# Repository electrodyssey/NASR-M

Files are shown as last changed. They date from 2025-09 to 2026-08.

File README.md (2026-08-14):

# NASR-M

SYZYGY carrier board powered by ZYNQ7000 SOC

Work in progress.

[Project goals and short design description](https://electrodyssey.net/nasr-m-syzygy-carrier-board.html)

[PDF schema is in schema-export folder](schema-export/NASR.pdf)

[Please watch ERRATA.txt for issues discovered during the board bringup](ERRATA.txt)

Version D 0.9.5 0b79528 (commit eba317391af35e6ee1b4c2de4c383aa31be21669) was submitted to production for a first prototype.

Things that worked so far:

+power distribution

+base controller (mostly works, but the MCU ethernet circuit isn't soldered in yet). [The Zephyr firmware is here](https://github.com/electrodyssey/NASR-M-ZFW)

+clock generator is configured with 33.333MHz signal

+CPU can run bare metal applications via JTAG

+DDR3 subsystem passes Zynq DDR tests with no errors

+PS Ethernet works

+Linux boots of SD card

+PS to PL DMA transfers works!

Watch [the blog](https://electrodyssey.net/tag_nasr-m.html) for an immersive soap opera experience.

The project is distributed under [Permissive OSHW License version 2](cern_ohl_p_v2.txt).

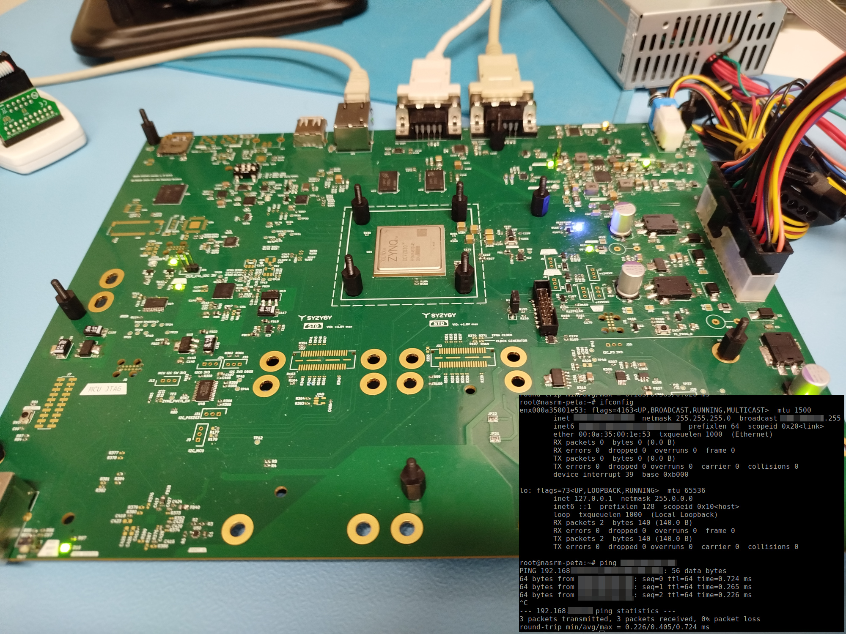
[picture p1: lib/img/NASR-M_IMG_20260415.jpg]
board photo NASR-M


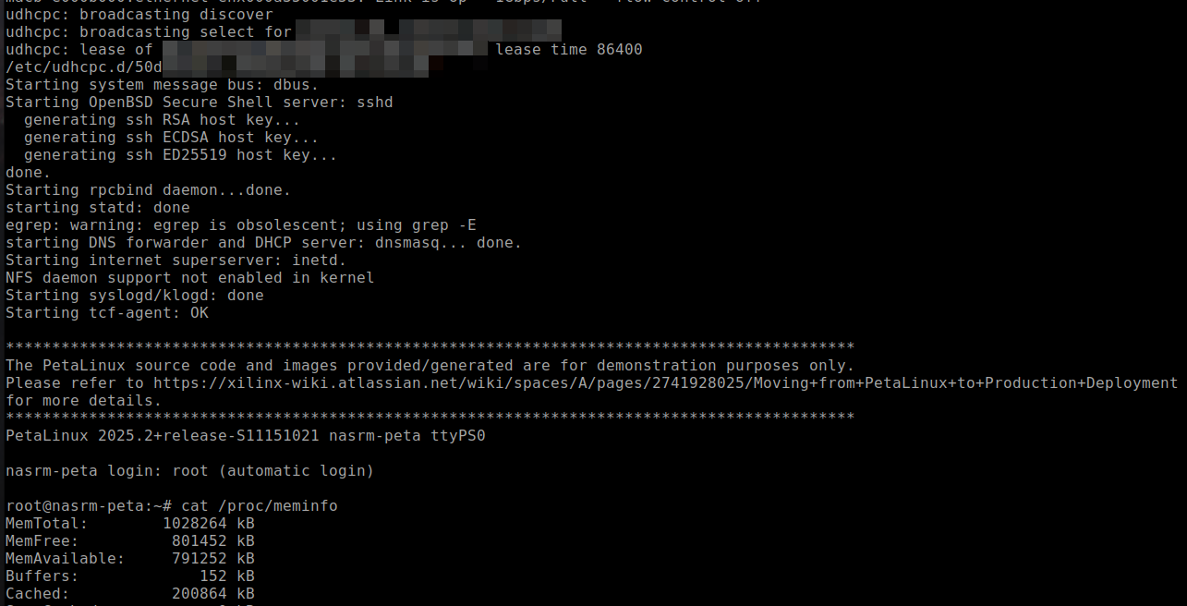
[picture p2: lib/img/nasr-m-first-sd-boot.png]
Linux boot in console NASR-M Linux boot


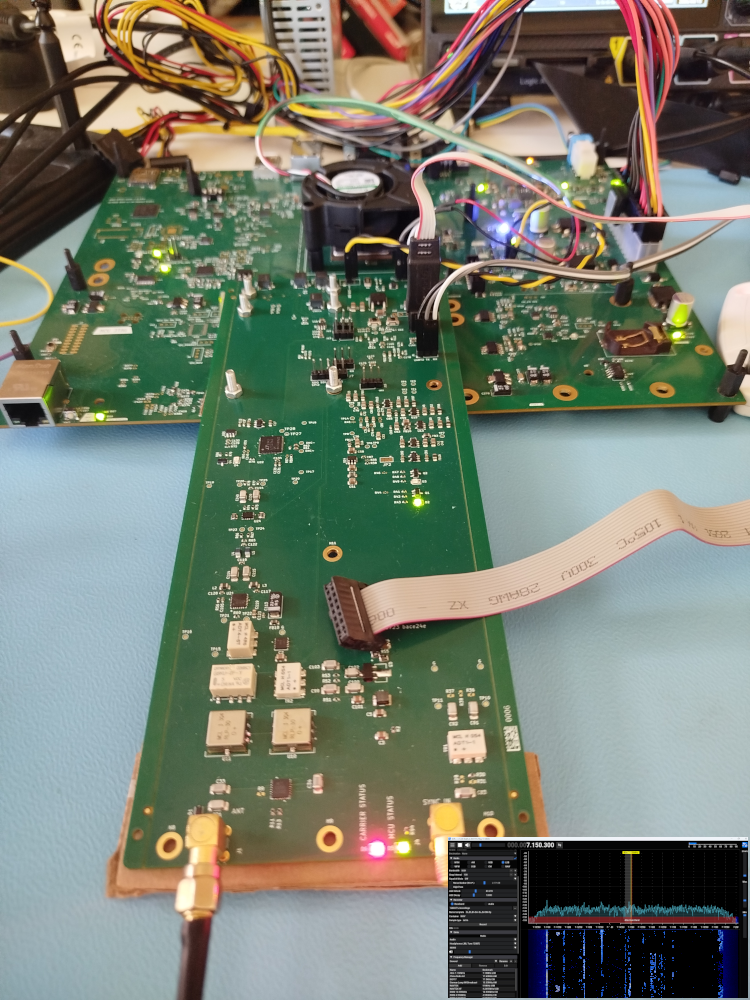
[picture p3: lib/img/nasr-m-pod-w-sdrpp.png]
SDR++ receives HF radio stream NASR-M with an HF receiver pod & SDR++


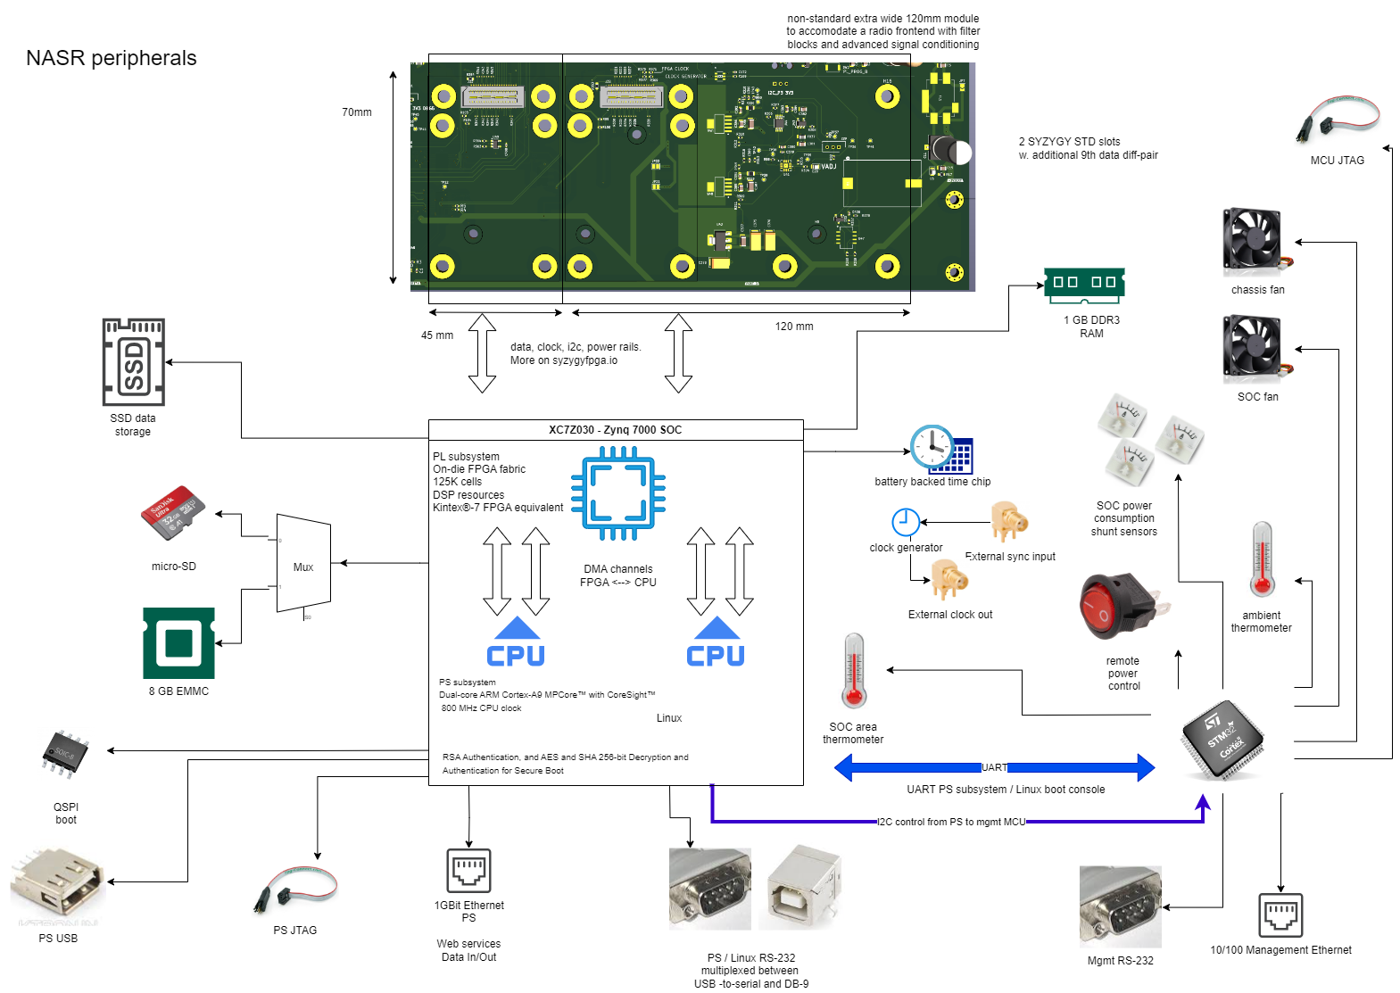
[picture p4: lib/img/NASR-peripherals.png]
Peripherals map Perhipherals map


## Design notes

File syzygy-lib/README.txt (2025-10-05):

SYZYGY templates were obtained from:

https://github.com/SYZYGYfpga/pcb-templates

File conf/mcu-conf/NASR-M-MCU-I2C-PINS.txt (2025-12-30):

PB6 -> I2C1 TREE SCL
PB7 -> I2C1 TREE SDA

PF0 -> I2C2 MCU SDA
PF1 -> I2C2 MCU SCL

PF14 ->I2C4 CLK SCL
PF15 ->I2C4 CLK SDA

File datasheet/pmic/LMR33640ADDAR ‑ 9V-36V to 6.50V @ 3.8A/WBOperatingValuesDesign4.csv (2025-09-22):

Name | Value | Category | Description
Vout | 6.5 V | System Information | Operational Output Voltage
IC Tolerance | 15 mV | IC | IC Feedback Tolerance
Cin IRMS | 1.5 A | Capacitor | Input capacitor RMS ripple current
Cin Pd | 748.89 µW | Capacitor | Input capacitor power dissipation
Cout IRMS | 266.48 mA | Capacitor | Output capacitor RMS ripple current
Cout Pd | 71.89 µW | Capacitor | Output capacitor power dissipation
Coutx IRMS | 346.01 µA | Capacitor | Output capacitor_x RMS ripple current
Coutx Pd | 2.39 nW | Capacitor | Output capacitor_x power loss
L Ipp | 924.33 mA | Inductor | Peak-to-peak inductor ripple current
L Pd | 275.71 mW | Inductor | Inductor power dissipation
Ipp percentage | 24.32% | Inductor | Inductor ripple current percentage (with respect to average inductor current)
Duty Cycle | 19.12% | System Information | Duty cycle
Efficiency | 91.4% | System Information | Steady state efficiency
Frequency | 400 kHz | System Information | Switching frequency
IC Tj | 118.41 °C | IC | IC junction temperature
ICThetaJA | 42.9 °C/W | IC | IC junction-to-ambient thermal resistance
IC Pd | 2.06 W | IC | IC power dissipation
Pout | 24.7 W | System Information | Total output power
Iin Avg | 751.05 mA | IC | Average input current
IC Ipk | 4.26 A | IC | Peak switch current in IC
Mode | CCM | System Information | Conduction Mode
Vout p-p | 3.79 mV | System Information | Peak-to-peak output ripple voltage
Vin p-p | 126.94 mV | System Information | Peak-to-peak input voltage
Phase Marg | 57.63 ° | System Information | Bode Plot Phase Margin
Cross Freq | 29.64 kHz | System Information | Bode plot crossover frequency
Low Freq Gain | 89.51 dB | System Information | Gain at 1Hz
Gain Marg | -28.19 dB | System Information | Bode Plot Gain Margin
Total Pd | 2.34 W | Power | Total Power Dissipation
FootPrint | 600 mm² | System Information | Total Foot Print Area of BOM components
Vin | 36 V | System Information | Vin operating point
Iout | 3.8 A | System Information | Iout operating point
Cin Pd | 748.89 µW | Power | Input capacitor power dissipation
Cout Pd | 71.89 µW | Power | Output capacitor power dissipation
Coutx Pd | 2.39 nW | Power | Output capacitor_x power loss
L Pd | 275.71 mW | Power | Inductor power dissipation
IC Pd | 2.06 W | Power | IC power dissipation
Vout Actual | 6.49 V | System Information | Vout Actual calculated based on selected voltage divider resistors
Vout Tolerance | 3.23% | System Information | Vout Tolerance based on IC Tolerance (no load) and voltage divider resistors if applicable
Total BOM | $4.26 | System Information | Total BOM Cost
BOM Count | 23 | System Information | Total Design BOM count

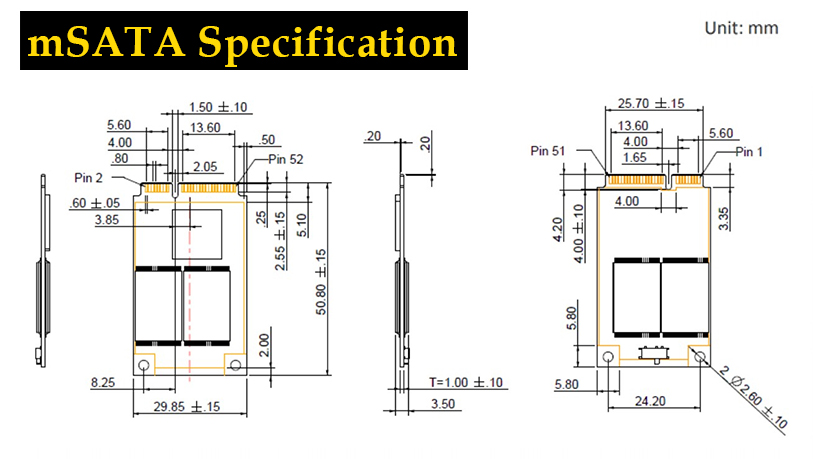
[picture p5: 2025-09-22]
mech/msata/mSATA-size-Specification.jpg

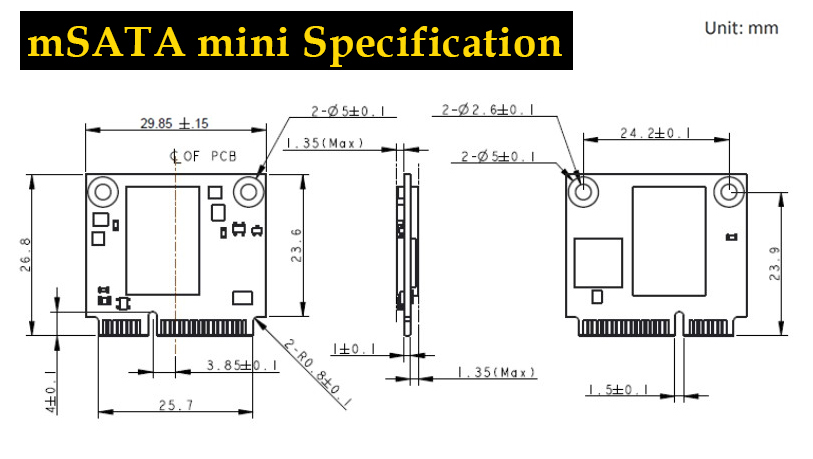
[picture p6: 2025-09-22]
mech/msata/mSATA-mini-size-Specification.jpg

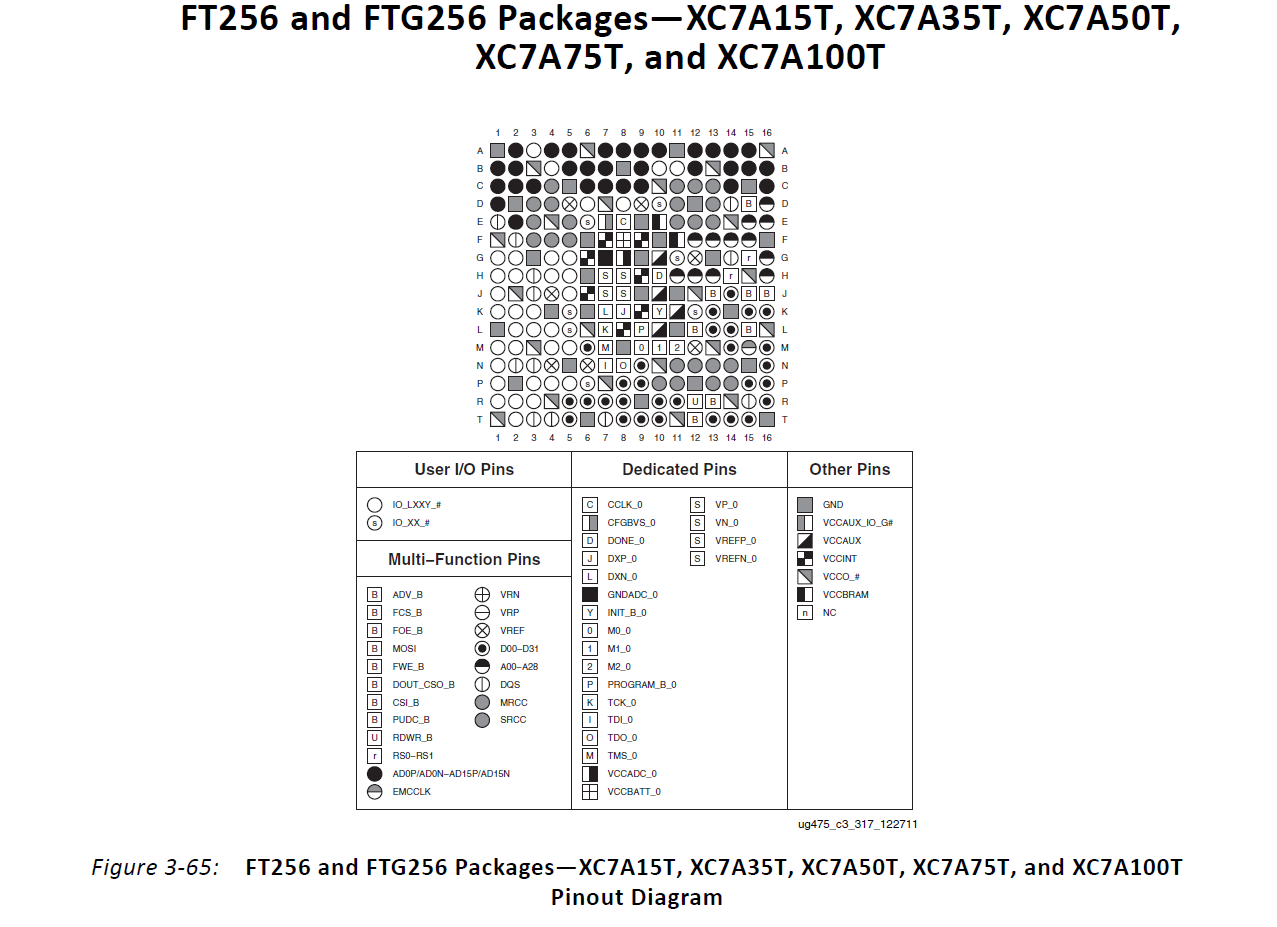
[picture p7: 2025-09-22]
datasheet/xilinx-7/artix-7-clocking/XC7A50T-FTG256-pinout.png

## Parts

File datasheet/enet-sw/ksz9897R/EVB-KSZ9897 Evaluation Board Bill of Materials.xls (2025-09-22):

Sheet: BOM Report
Bill of Materials |  | EVB-KSZ9897 |  |  |  | Build Qty: | 10
Document Number: | 02-PCB-UNG_8076
Board Number: | 04-PCB-UNG_8076
Part Number: | EVB-KSZ9897
Revision: | B1
Engineer:
Drawn By:
Creation Date: | 10:40:54 AM
Print Date: | 18:50:46
Quantity Per Build | Designator | Description_ | Manufacturer 1 | Manufacturer Part Number 1 | Supplier 1 | Supplier Part Number 1 | Supplier Unit Price 1 | Price / 1 Board | Populated | Quantity | Quantity Override | Notes
560 | C1, C2, C3, C4, C5, C6, C7, C8, C9, C10, C11, C12, C13, C14, C15, C16, C22, C23, C24, C25, C31, C32, C45, C51, C52, C53, C54, C55, C56, C57, C58, C59, C65, C66, C67, C68, C69, C70, C71, C72, C77, C78, C79, C80, C81, C82, C83, C84, C94, C118, C119, C120, C122, C134, C143, C144 | CAP CER 0.1uF 50V 10% X7R SMD 0402 | TDK Corporation | C1005X7R1H104K050BB | Digi-Key | 445-5932-1-ND |  | $0.00 |  | 56 | 56
10 | C17 | CAP CER 1UF 50V 10% X7R 0603 | Taiyo Yuden | UMK107AB7105KA-T | Digi-Key | 587-3247-1-ND |  | $0.00 |  | 1 | 1
350 | C18, C19, C21, C26, C27, C28, C34, C37, C38, C41, C42, C46, C47, C48, C64, C107, C109, C110, C112, C113, C114, C115, C116, C117, C124, C125, C127, C128, C129, C137, C138, C139, C140, C141, C142 | CAP CER 0.1UF 35V X5R 0402 | TDK Corporation | C1005X5R1V104M050BB | Digi-Key | 445-7385-1-ND |  | $0.00 |  | 35 | 35
20 | C20, C135 | CAP CER 0.1uF 25V 10% X7R SMD 0603 | Murata | GRM188R71E104KA01D | Digi-Key | 490-1524-1-ND |  | $0.00 |  | 2 | 2
60 | C29, C106, C108, C111, C123, C126 | CAP CER 4.7uF 6.3V 20% X5R SMD 0603 | Panasonic | ECJ-1VB0J475M | Digi-Key | PCC2318CT-ND |  | $0.00 |  | 6 | 6
10 | C33 | CAP CER 2.2uF 6.3V 10% X7R SMD 0603 | TDK | C1608X7R0J225K | Digi-Key | 445-5960-1-ND |  | $0.00 |  | 1 | 1
20 | C35, C36 | CAP CER 0.1uF 10V 10% X5R SMD 0402 | KEMET | C0402C104K8PACTU | Digi-Key | 399-3027-1-ND |  | $0.00 |  | 2 | 2
60 | C39, C43, C130, C131, C167, C168 | CAP CER 15pF 50V 5% NP0 SMD 0402 | Murata | GRM1555C1H150JA01D | Digi-Key | 490-5888-2-ND |  | $0.00 |  | 6 | 6
40 | C40, C44, C132, C136 | CAP CER 1uF 16V 10% X5R SMD 0603 | AVX | 0603YD105KAT2A | Digi-Key | 478-1249-1-ND |  | $0.00 |  | 4 | 4
80 | C49, C60, C61, C62, C76, C85, C88, C89 | CAP CER 10uF 25V 10% X5R SMD 0805 | Murata | GRM21BR61E106KA73L | Digi-Key | 490-5523-1-ND |  | $0.00 |  | 8 | 8
20 | C50, C75 | CAP CER 1uF 16V 10% X5R SMD 0402 | TDK Corporation | C1005X5R1C105K | Digi-Key | 445-4978-2-ND |  | $0.00 |  | 2 | 2
20 | C63, C90 | CAP CER 1UF 35V 10% X5R SMD 0402 | Murata Electronics North America | GRM155R6YA105KE11D | Digi-Key | 490-10019-1-ND |  | $0.00 |  | 2 | 2
40 | C73, C74, C86, C96 | CAP CER 10uF 6.3V 20% X5R SMD 0603 | AVX | 06036D106MAT2A | Digi-Key | 478-5318-2-ND |  | $0.00 |  | 4 | 4
10 | C91 | CAP CER 0.33uF 50V 10% X7R SMD 0805 | TDK Corporation | C2012X7R1H334K125AA | Digi-Key | 445-7541-1-ND |  | $0.00 |  | 1 | 1
10 | C92 | CAP CER 47UF 25V X5R 1206 | TDK Corporation | C3216X5R1E476M160AC | Mouser | 810-C3216X5R1E476M |  | $0.00 |  | 1 | 1
10 | C93 | CAP TANT 330uF 6.3V 20% 45mOhm SMD D | KEMET | T520D337M006ATE045 | Digi-Key | 399-4055-1-ND |  | $0.00 |  | 1 | 1
10 | C95 | CAP CER 1000PF 2KV 1808 | Murata | GR442QR73D102KW01L | Mouser | 81-GR442QR73D102KW01 |  | $0.00 |  | 1 | 1
10 | R89 | CAP CER 12pF 50V 5% NP0 SMD 0603 | Panasonic | ECJ-1VC1H120J | Digi-Key | 478-1164-1-ND |  |  |  | 1 | 1
10 | D1 | DIO SCTKY MBRX140-TP 550mV 1A 40V SMD SOD-123 | Micro Commercial Co | MBRX140-TP | Digi-Key | MBRX140TPMSCT-ND |  | $0.00 |  | 1 | 1
20 | D2, D12 | LED, Bright Green, 0603 | Lite-On | LTST-C191KGKT | Digi-Key | 160-1446-6-ND |  | $0.00 |  | 2 | 2
20 | D3, D4 | LED, Blue, 0603 | Kingbright | APT1608VBC/D | Digi-Key | 754-1789-6-ND |  | $0.00 |  | 2 | 2
10 | D5 | DIO LED YELLOW 2.1V 20mA 14mcd Diffuse SMD 0603 | Lumex | sml-lx0603yw | Digi-Key | 67-1550-6-ND |  | $0.00 |  | 1 | 1
10 | D6 | LED, Bright Red, 0603 | Lite-On | LTST-C191KRKT | Digi-Key | 160-1447-6-ND |  | $0.00 |  | 1 | 1
10 | D7 | DIO SCTKY B340A 500mV 3A 40V DO-214AC_SMA | Diodes Incorporated | B340A-13-F | Digi-Key | B340A-FDICT-ND |  | $0.00 |  | 1 | 1
10 | F1 | Surface Mount Fuses Fuseblock w/ fuse 2A OMNI BLOK 154 | Littelfuse | 0154002.DR | Mouser | 576-0154002.DR |  | $0.00 |  | 1 | 1
100 | FB4, FB5, FB8, FB11, FB12, FB13, FB14, FB15, FB16, FB17 | FERRITE 2A 220R SMD 0805 | Murata Electronics North America | BLM21PG221SN1D | Digi-Key | 490-1054-1-ND |  | $0.00 |  | 10 | 10
60 | J1, J2, J3, J4, J5, J20 | CON MODULAR RJ45 MAGJACK TH R/A | Amphenol Commercial Products | RJMG2012211A0FR | Digikey | RJMG2012211A0FR-ND |  | $0.00 |  | 6 | 6
30 | J6, J8, J11 | HDR 3POS .100" SGL GOLD | Samtec Inc. | TSW-103-07-G-S | Digi-Key | SAM1029-03-ND |  | $0.00 |  | 3 | 3
10 | J7 | CONN PWR JACK 2.5X5.5MM HIGH CUR | CUI Inc. | PJ-002AH | Digi-Key | CP-002AH-ND |  | $0.00 |  | 1 | 1
10 | J9 | CONN RCPT USB TYPE B 3.0 R/A | Wurth Electronics Inc | 692221030100 | Digi-Key | 732-3158-ND |  | $0.00 |  | 1 | 1
10 | J14 | CON HDR-2.54 MALE 1x8 GOLD 5.84MH TH VERT | Samtec | TSW-108-07-G-S | Digi-Key | SAM1029-08-ND |  | $0.00 |  | 1 | 1
10 | J15 | CONN HEADER 6POS .100" DUAL GOLD | Samtec | TSW-103-07-G-D | Digi-Key | SAM1028-03-ND |  | $0.00 |  | 1 | 1
40 | J16, J18, J24, J25 | CON HDR-2.54 MALE 1x2 GOLD 5.84MH TH VERT | Samtec | TSW-102-07-G-S | Digi-Key | SAM1029-02-ND |  | $0.00 |  | 4 | 4
10 | J17 | CON HDR-2.54 Male 2x3 Gold 5.84MH TH VERT | Samtec | TSW-104-07-G-D | Digi-Key | SAM1028-04-ND |  | $0.00 |  | 1 | 1
20 | J21, J23 | CON HDR-2.54 MALE 1x3 GOLD 5.84MH TH VERT | Samtec | TSW-103-07-G-S | Digi-Key | SAM1029-03-ND |  | $0.00 |  | 2 | 2
10 | J22 | HDR 10POS .100" DUAL SHROUDED | Adam Tech | BHR-10-VUA | Future Electronics | BHR-10-VUA |  | $0.00 |  | 1 | 1
10 | J28 | HDR 2POS .100" SGL GOLD | Samtec Inc. | TSW-102-07-G-S | Digi-Key | SAM1029-02-ND |  | $0.00 |  | 1 | 1
10 | L1 | IND 27uH 20 % 2.35A SMD | Bourns | SRR1240-270M | Mouser | 652-SRR1240-270M |  | $0.00 |  | 1 | 1
20 | L2, L3 | INDUCTOR 15uH 1.16A 20% SMD MSS6132 | Coilcraft | MSS6132-153ML | Coilcraft | MSS6132-153ML |  | $0.00 |  | 2 | 2
120 | R1, R2, R3, R4, R5, R6, R7, R8, R9, R15, R87, R124 | RES TKF 100R 5% 1/10W SMD 0603 | Panasonic | ERJ-3GEYJ101V | Digi-Key | P100GTR-ND |  | $0.00 |  | 12 | 12
10 | R10 | RES TKF 20R 5% 1/10W SMD 0603 | NIC Components | NRC06J200TRF | NIC Components | NRC06J200TRF |  | $0.00 |  | 1 | 1
20 | R13, R54 | RES 1k 5% 1/10W SMD 0603 | Panasonic Electronic Components | ERJ-3GEYJ102V | Digi-Key | P1.0KGDKR-ND |  | $0.00 |  | 2 | 2
160 | R14, R31, R32, R44, R47, R52, R56, R106, R107, R110, R111, R123, R125, R127, R128, R129 | RES TKF 0R 1/10W SMD 0603 | Panasonic | ERJ-3GEY0R00V | Digi-Key | P0.0GTR-ND |  | $0.00 |  | 16 | 16
10 | R49 | RES TKF 0R SMD 0402 | Panasonic | ERJ-2GE0R00X | Digi-Key | P0.0JCT-ND |  |  |  | 1 | 1
150 | R16, R22, R29, R50, R51, R61, R64, R65, R66, R67, R68, R72, R84, R85, R86 | RES TKF 10k 5% 1/10W SMD 0603 | Panasonic | ERJ-3GEYJ103V | Digi-Key | P10KGCT-ND |  | $0.00 |  | 15 | 15
10 | R17 | RES TKF 20k 5% 1/10W SMD 0603 | Panasonic | ERJ-3GSYJ203 | Digi-Key | P20KGCT-ND |  | $0.00 |  | 1 | 1
10 | R19 | RES TKF 2k 1% 1/10W SMD 0603 | Panasonic | ERJ-3EKF2001V | Digi-Key | P2.00KHTR-ND |  | $0.00 |  | 1 | 1
110 | R20, R34, R41, R42, R48, R115, R116, R117, R118, R119, R120 | RES 22ohm 5% 1/10W SMD 0402 | Panasonic | ERJ-2GEJ220X | Mouser | P22JTR-ND |  | $0.00 |  | 11 | 11
10 | R21 | RES TKF 40.2k 1% 1/16W SMD 0603 | Panasonic Electronic Components | ERJ-3EKF4022V | Digi-Key | P40.2KHCT-ND |  | $0.00 |  | 1 | 1
10 | R23 | RES TKF 12k 1% 1/10W SMD 0603 | Yageo | RC0603FR-0712KL | Digi-Key | 311-12.0KHRCT-ND |  | $0.00 |  | 1 | 1
20 | R24, R93 | RES TKF 2.05k 1% 1/10W SMD 0603 | Yageo | RC0603FR-072K05L | Digi-Key | 311-2.05KHRTR-ND |  | $0.00 |  | 2 | 2
120 | R25, R26, R27, R28, R30, R35, R75, R76, R77, R78, R80, R82 | RES TKF 22R 1% 1/10W SMD 0603 | Yageo | RC0603FR-0722RL | Digi-Key | 311-22.0HRCT-ND |  | $0.00 |  | 12 | 12
10 | R37 | RES TKF 330R 5% 1/10W SMD 0603 | Panasonic Electronic Components | ERJ-3GEYJ331V | Digi-Key | P330GDKR-ND |  | $0.00 |  | 1 | 1
170 | R39, R40, R74, R79, R81, R83, R91, R96, R98, R99, R100, R101, R103, R104, R109, R112, R113 | RES TKF 1k 5% 1/10W SMD 0603 | Panasonic | ERJ-3GEYJ102V | Digi-Key | P1.0KGDKR-ND |  | $0.00 |  | 17 | 17
20 | R45, R92 | RES TKF 10k 5% 1/10W SMD 0603 | Panasonic | ERJ-3GEYJ103V | Digi-Key | P10KGCT-ND |  | $0.00 |  | 2 | 2
10 | R53 | RES TKF 31.6K 1% 1/10W SMD 0603 | Panasonic Electronic Components | ERJ-3EKF3162V | Digi-Key | P31.6KHCT-ND |  | $0.00 |  | 1 | 1
20 | R55, R59 | RES TKF 10k 1% 1/10W SMD 0603 | NIC Components | NRC06F1002TRF | NIC Components | NRC06F1002TRF |  | $0.00 |  | 2 | 2
10 | R57 | RES TKF 4.7k 5% 1/10W SMD 0603 | Panasonic | ERJ-3GEYJ472V | Digi-Key | P4.7KGCT-ND |  | $0.00 |  | 1 | 1
10 | R58 | RES TKF 21.5K 1% 1/10W SMD 0603 | Panasonic | ERJ-3EKF2152V | DigiKey | P21.5KHCT-ND |  | $0.00 |  | 1 | 1
20 | R69, R114 | RES TKF 100k 5% 1/10W SMD 0603 | Panasonic | ERJ-3GEYJ104V | Digi-Key | P100KGCT-ND |  | $0.00 |  | 2 | 2
10 | R73 | RES 12.1K 1% 1/10W 0603 | Panasonic Electronic Components | ERJ-3EKF1212V | Digi-Key | P12.1KHCT-ND |  | $0.00 |  | 1 | 1
10 | R108 | RES TKF 6.04k 1% 1/10W SMD 0603 | Yageo | 9T06031A6041FBHFT | Digi-Key | 9T06031A6041FBHFT-ND |  | $0.00 |  | 1 | 1
10 | R122 | RES TKF 330R 5% 1/10W SMD 0603 | Panasonic | ERJ-3GEYJ331V | Digi-Key | P330GTR-ND |  | $0.00 |  | 1 | 1
10 | SW1 | Tactile Switch SPST-NO Top Actuated Surface Mount | C&K | PTS810 SJM 250 SMTR LFS | Digi-Key | CKN10502CT-ND |  | $0.00 |  | 1 | 1
10 | SW2 | Slide Switch SPDT Through Hole | C&K | 1101M2S3CQE2 | Digi-Key | CKN5001-ND |  | $0.00 |  | 1 | 1
10 | SW4 | SWITCH SLIDE SPST 24V 100mA 1825058-9EXT ACT 8POS 24V | TE Connectivity Alcoswitch Switches | 1-1825058-9 | Mouser | 506-ADE08S04 |  | $0.00 |  | 1 | 1
10 | TP1 | TEST POINT PC MINI .040"D WHITE | Keystone Electronics | 5002 | Digi-Key | 5002K-ND |  | $0.00 |  | 1 | 1
40 | TP2, TP4, TP5, TP8 | TEST POINT PC MINI .040"D BLACK | Keystone Electronics | 5001 | Digi-Key | 5001K-ND |  | $0.00 |  | 4 | 4
10 | TP3 | TEST POINT PC MINI .040"D ORANGE | Keystone Electronics | 5003 | Digi-Key | 5003K-ND |  | $0.00 |  | 1 | 1
10 | TP6 | TEST POINT PC MINI .040"D YELLOW | Keystone Electronics | 5004 | Digi-Key | 5004K-ND |  | $0.00 |  | 1 | 1
10 | TP7 | TEST POINT PC MINI .040"D RED | Keystone Electronics | 5000 | Digi-Key | 5000K-ND |  | $0.00 |  | 1 | 1
50 | U2, U9, U10, U14, U15 | 74LVC1G14GW,125 SCHMITT-TRG INVERTER | NXP | 74LVC1G14GW,125 | Mouser | 771-74LVC1G14GW-G |  | $0.00 |  | 5 | 5
Microchip Parts listed below
10 | U1 | Edinburgh LAN7801/RGMII pinout, QFN64 | Microchip | LAN7801/RGMII_QFN64 | Microchip | LAN7801/RGMII_QFN64 |  | $0.00 |  | 1 | 1
10 | U3 | IC, 7-Port Gigabit Ethernet Switch with 2 RGMII / MII / RMII Interfaces, TQFP128 | Microchip Technology | KSZ9897RTXC | Microchip Technology | KSZ9897RTXC |  | $0.00 |  | 1 | 1
10 | U4 | IC EEPROM 4KBIT 3MHZ 8SOIC | Microchip Technology | 93AA66C-I/SN | Digi-Key | 93AA66C-I/SN-ND |  | $0.00 |  | 1 | 1
20 | U5, U6 | IC REG BUCK SYNC ADJ 1A 8TDFN | Microchip Technology | MCP16311T-E/MNY | Mouser | 579-MCP16311T-E/MNY |  | $0.00 |  | 2 | 2
10 | U7 | IC REG BUCK ADJ 2A 8SOIC | Micrel Inc | MIC4684YM-TR | Mouser | 998-MIC4684YM |  | $0.00 |  | 1 | 1
10 | U8 | KSZ9031RNXCC Gigabit Ethernet PHY with RGMII | Microchip | KSZ9031RNXCC | Mouser | 998-KSZ9031RNXCC |  | $0.00 |  | 1 | 1
10 | X1 | OSC MEMS CONFIGURABLE FOUR OUTPUT | Microchip Technology | DSC400-1111Q0085KI1 | Microchip Technology | DSC400-1111Q0085KI1 |  | $0.00 |  | 1 | 1
Mechanical Parts to be added in the package
10 | SERIAL1 | Label, Serial Number, Laminated, 250 x 800 | Brother | 1/4" x 0.8" |  |  |  | $0.00 | MECH | 1 | 1
10 | RUBBER FEET | Foot, Silicone Rubber, Adhesive, Clear, Cylindrical, .500"x.250" | Richco | RBS-6 |  |  |  | $0.00 | MECH | 1 | 1
PCB
10 | PCB1 | Printed Circuit Board |  | EVB-KSZ9897 |  |  |  | $0.00 | PCB | 1 | 1
 |  |  |  |  |  |  |  | $0.00
Do Not Populate Parts listed below
0 | C30 | CAP CER 4.7uF 6.3V 20% X5R SMD 0603 | Panasonic | ECJ-1VB0J475M | Digi-Key | PCC2318CT-ND |  | $0.00 | DNP | 1 | 0
0 | C87, C97, C98 | CAP CER 0.1UF 35V X5R 0402 | TDK Corporation | C1005X5R1V104M050BB | Digi-Key | 445-7385-1-ND |  | $0.00 | DNP | 3 | 0
0 | J10, J12, J13, J19 | CON HDR-2.54 Male 2x5 Gold 5.84MH TH VERT | Samtec Inc | TSW-106-07-G-D |  |  |  | $0.00 | DNP | 4 | 0
0 | R11, R12, R18, R94 | RES TKF 10k 5% 1/10W SMD 0603 | Panasonic | ERJ-3GEYJ103V | Digi-Key | P10KGCT-ND |  | $0.00 | DNP | 4 | 0
0 | R33, R36, R38, R43, R46, R60, R102, R105, R126 | RES TKF 0R 1/10W SMD 0603 | Panasonic | ERJ-3GEY0R00V | Digi-Key | P0.0GTR-ND |  | $0.00 | DNP | 9 | 0
0 | R70, R71, R88, R90 | RES TKF 1k 5% 1/10W SMD 0603 | Panasonic | ERJ-3GEYJ102V | Digi-Key | P1.0KGCT-ND |  | $0.00 | DNP | 4 | 0
0 | TP10, TP17 | TEST POINT PC MINI .040"D ORANGE | Keystone Electronics | 5003 | Digi-Key | 5003K-ND |  | $0.00 | DNP | 2 | 0
0 | Y1, Y2, Y3 | Crystal 25MHz 10pF SMD 4Pin DFN LCC | Abracon | ABM8G-25.000MHZ-B4Y-T | Mouser | 815-ABM8G-25-B4Y-T |  | $0.00 | DNP | 3 | 0
 |  |  |  |  |  |  |  | #REF!
Approved | Notes

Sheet: Project Information
Project Full Path | C:\Users\jhancock\Perforce\txusperforce_1999\jhancock_AUS-LT-C21683\depot_np_hweng_boards\ung_hweng\UNG_8076_KSZ9897_EVB (Queen)\Rev B\EVB-KSZ9897_B.PrjPcb
Project Filename | EVB-KSZ9897_B.PrjPcb
Variant Name | None
Board Number | PCB-UNG_8076
Data-Source Filename | EVB-KSZ9897_B.PrjPcb
Data-Source Full Path | C:\Users\jhancock\Perforce\txusperforce_1999\jhancock_AUS-LT-C21683\depot_np_hweng_boards\ung_hweng\UNG_8076_KSZ9897_EVB (Queen)\Rev B\EVB-KSZ9897_B.PrjPcb
Title | Queen
Total Quantity | 348
Report Time | 10:40:54 AM
Report Date | 12/2/2016
Report Date & Tine | 12/2/2016 10:40:54 AM
Output Name | Bill of Materials
Output Type | BOM_PartType
Output Generator Name | BOM
Output Generator Description | Bill of Materials
PCB Label Number | <Parameter ProjectBoardLabel not found>
Part Number | EVB-KSZ9897

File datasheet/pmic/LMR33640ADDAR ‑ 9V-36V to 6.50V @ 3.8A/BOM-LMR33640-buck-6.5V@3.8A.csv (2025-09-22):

Part | Manufacturer | Part Number | Quantity | Price ($) | Footprint (mm²) | Description
Cb_inpflt | Nichicon | UUD1H270MCL1GS | 2 | 0.18 | 79.98 | Cap: 27 µF Total Derated Cap: 54 µF VDC: 50 V ESR: 680 mΩ Package: 6.3x7.7
Cf_inpflt | TDK | C3225X7R1H106M250AC | 3 | 0.27 | 14.7 | Cap: 10 µF Total Derated Cap: 9.5 µF VDC: 50 V ESR: 1 mΩ Package: 1210
Rd_inpflt | Panasonic | ERJ-3RSFR10V | 1 | 0.03 | 4.68 | Resistance: 100 mΩ Tolerance: 1.0% Power: 100 mW
Lf_inpflt | MuRata Toko | DFE252012F-1R0M=P2 | 1 | 0.13 | 10.5 | L: 1 µH DCR: 40 mΩ IDC: 3.3 A
Rpg | Vishay-Dale | CRCW0603100KFKEA | 1 | 0.01 | 4.68 | Resistance: 100 kΩ Tolerance: 1.0% Power: 100 mW
L1 | Coilcraft | MSS1210-153MEB | 1 | 0.81 | 204.49 | L: 15 µH DCR: 19 mΩ IDC: 8.7 A
Cboot | MuRata | GRM155R71A104KA01D | 1 | 0.01 | 3 | Cap: 100 nF Total Derated Cap: 100 nF VDC: 10 V ESR: 1 mΩ Package: 0402
Cin | TDK | C3225X7R1H106M250AC | 3 | 0.27 | 14.7 | Cap: 10 µF Total Derated Cap: 12 µF VDC: 50 V ESR: 1 mΩ Package: 1210
U1 | Texas Instruments | LMR33640ADDAR | 1 | 0.7 | 55.2
Coutx | MuRata | GRM188R71H104KA93D | 1 | 0.02 | 4.68 | Cap: 100 nF Total Derated Cap: 99 nF VDC: 50 V ESR: 20 mΩ Package: 0603
Cout | MuRata | GRM32ER61C476KE15L | 3 | 0.17 | 14.7 | Cap: 47 µF Total Derated Cap: 78 µF VDC: 16 V ESR: 3.04 mΩ Package: 1210
Cvcc | MuRata | GRM188R60J105KA01D | 1 | 0.01 | 4.68 | Cap: 1 µF Total Derated Cap: 1 µF VDC: 6.3 V ESR: 6.07 mΩ Package: 0
Cinx | Taiyo Yuden | UMK212B7224KG-T | 1 | 0.02 | 6.75 | Cap: 220 nF Total Derated Cap: 220 nF VDC: 50 V ESR: 1 mΩ Package: 0805
Rfbt | Vishay-Dale | CRCW0402100KFKED | 1 | 0.01 | 3 | Resistance: 100 kΩ Tolerance: 1.0% Power: 63 mW
Rfbb | Vishay-Dale | CRCW040218K2FKED | 1 | 0.01 | 3 | Resistance: 18.2 kΩ Tolerance: 1.0% Power: 63 mW
Cff | MuRata | GRM1555C1H270JA01D | 1 | 0.01 | 3 | Cap: 27 pF Total Derated Cap: 27 pF VDC: 50 V ESR: 1 mΩ Package: 0402

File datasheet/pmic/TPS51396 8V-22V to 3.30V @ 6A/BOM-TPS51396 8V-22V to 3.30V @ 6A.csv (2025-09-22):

Part | Manufacturer | Part Number | Quantity | Price ($) | Footprint (mm²) | Description
Rfbt | Yageo | RC0603FR-0790K9L | 1 | 0.01 | 4.68 | Resistance: 90.9 kΩ Tolerance: 1.0% Power: 100 mW
Rfbb | Vishay-Dale | CRCW080520K0FKEA | 1 | 0.01 | 6.75 | Resistance: 20 kΩ Tolerance: 1.0% Power: 125 mW
Cb_inpflt | Panasonic | EEHZA1H100R | 1 | 0.4567 | 58.4 | Cap: 10 µF Total Derated Cap: 10 µF VDC: 50 V ESR: 120 mΩ Package: 5x5.8
Cf_inpflt | Panasonic | 35SVPF82M | 1 | 1.17 | 106.09 | Cap: 82 µF Total Derated Cap: 82 µF VDC: 35 V ESR: 20 mΩ Package: 8x11.9
Rd_inpflt | Panasonic | ERJ-3RQFR39V | 1 | 0.02 | 4.68 | Resistance: 390 mΩ Tolerance: 1.0% Power: 100 mW
Lf_inpflt | NIC Components | NPI54C2R2MTRF | 1 | 0.09 | 60.75 | L: 2.2 µH DCR: 30 mΩ IDC: 2.8 A
Dz | ON Semiconductor | BZX84C3V6LT1G | 1 | 0.03 | 14 | Type: SMT VRWM: 3.6 V
Cboot | Taiyo Yuden | EMK107B7104KA-T | 1 | 0.01 | 4.68 | Cap: 100 nF Total Derated Cap: 100 nF VDC: 16 V ESR: 1 mΩ Package: 0603
Rml | Yageo | RC0603FR-075K1L | 1 | 0.01 | 4.68 | Resistance: 5.1 kΩ Tolerance: 1.0% Power: 100 mW
Cinx | MuRata | GRM188R71H104KA93D | 1 | 0.02 | 4.68 | Cap: 100 nF Total Derated Cap: 87 nF VDC: 50 V ESR: 20 mΩ Package: 0603
Rent | Vishay-Dale | CRCW060318K2FKEA | 1 | 0.01 | 4.68 | Resistance: 18.2 kΩ Tolerance: 1.0% Power: 100 mW
Renb | Yageo | RC0603FR-075K1L | 1 | 0.01 | 4.68 | Resistance: 5.1 kΩ Tolerance: 1.0% Power: 100 mW
Cin | TDK | C3216X5R1E476M160AC | 1 | 0.35 | 10.92 | Cap: 47 µF Total Derated Cap: 2.8 µF VDC: 25 V ESR: 2.08 mΩ Package: 1206
Rmh | Yageo | RC0603FR-07330KL | 1 | 0.01 | 4.68 | Resistance: 330 kΩ Tolerance: 1.0% Power: 100 mW
Rpg | Vishay-Dale | CRCW0603100KFKEA | 1 | 0.01 | 4.68 | Resistance: 100 kΩ Tolerance: 1.0% Power: 100 mW
Cvcc | Taiyo Yuden | EMK107B7105KA-T | 1 | 0.01 | 4.68 | Cap: 1 µF Total Derated Cap: 1 µF VDC: 16 V ESR: 1 mΩ Package: 0603
L1 | NIC Components | NPI52P3R3MTRF | 1 | 0.356 | 444.63 | L: 3.3 µH DCR: 14 mΩ IDC: 10 A
Cout | MuRata | GRM31CR71A226KE15L | 4 | 0.12 | 10.92 | Cap: 22 µF Total Derated Cap: 72 µF VDC: 10 V ESR: 3.59 mΩ Package: 1206
U1 | Texas Instruments | TPS51396ARJER | 1 | 0.37 | 16
Cff | Taiyo Yuden | UMK105CG560JV-F | 1 | 0.01 | 3 | Cap: 56 pF Total Derated Cap: 56 pF VDC: 5 V ESR: 0 Ω Package: 0402

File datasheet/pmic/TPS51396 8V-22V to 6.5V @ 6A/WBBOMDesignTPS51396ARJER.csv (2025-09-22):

Part | Manufacturer | Part Number | Quantity | Price ($) | Footprint (mm²) | Description
Rfbt | Yageo | RC0603FR-07196KL | 1 | 0.01 | 4.68 | Resistance: 196 kΩ Tolerance: 1.0% Power: 100 mW
Rfbb | Vishay-Dale | CRCW080520K0FKEA | 1 | 0.01 | 6.75 | Resistance: 20 kΩ Tolerance: 1.0% Power: 125 mW
Dz | ON Semiconductor | BZX84C3V6LT1G | 1 | 0.03 | 14 | Type: SMT VRWM: 3.6 V
Cboot | Taiyo Yuden | EMK107B7104KA-T | 1 | 0.01 | 4.68 | Cap: 100 nF Total Derated Cap: 100 nF VDC: 16 V ESR: 1 mΩ Package: 0603
Rml | Yageo | RC0603FR-075K1L | 1 | 0.01 | 4.68 | Resistance: 5.1 kΩ Tolerance: 1.0% Power: 100 mW
Cinx | MuRata | GRM188R71H104KA93D | 1 | 0.02 | 4.68 | Cap: 100 nF Total Derated Cap: 87 nF VDC: 50 V ESR: 20 mΩ Package: 0603
Rent | Vishay-Dale | CRCW060318K2FKEA | 1 | 0.01 | 4.68 | Resistance: 18.2 kΩ Tolerance: 1.0% Power: 100 mW
Renb | Yageo | RC0603FR-075K1L | 1 | 0.01 | 4.68 | Resistance: 5.1 kΩ Tolerance: 1.0% Power: 100 mW
Cin | TDK | C3216X5R1E476M160AC | 1 | 0.35 | 10.92 | Cap: 47 µF Total Derated Cap: 2.8 µF VDC: 25 V ESR: 2.08 mΩ Package: 1206
Rmh | Yageo | RC0603FR-07330KL | 1 | 0.01 | 4.68 | Resistance: 330 kΩ Tolerance: 1.0% Power: 100 mW
Rpg | Vishay-Dale | CRCW0603100KFKEA | 1 | 0.01 | 4.68 | Resistance: 100 kΩ Tolerance: 1.0% Power: 100 mW
Cvcc | Taiyo Yuden | EMK107B7105KA-T | 1 | 0.01 | 4.68 | Cap: 1 µF Total Derated Cap: 1 µF VDC: 16 V ESR: 1 mΩ Package: 0603
L1 | Coilcraft | XAL6060-472MEB | 1 | 0.82 | 71.56 | L: 4.7 µH DCR: 13.1 mΩ IDC: 10.5 A
Cout | TDK | CGA9N3X7R1C476M230KB | 4 | 0.67 | 53.9 | Cap: 47 µF Total Derated Cap: 160 µF VDC: 16 V ESR: 3.16 mΩ Package: 2220_250
U1 | Texas Instruments | TPS51396ARJER | 1 | 0.37 | 16
Cff | MuRata | GRM0335C1E470JA01D | 1 | 0.01 | 2.08 | Cap: 47 pF Total Derated Cap: 47 pF VDC: 25 V ESR: 0 Ω Package: 0201

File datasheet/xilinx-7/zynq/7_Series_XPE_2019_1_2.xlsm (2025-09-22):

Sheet: Summary
 |  |  | Xilinx Power Estimator (XPE) - 2019.1.2 |  |  |  |  |  |  |  |  |  |  |  |  |  |  |  |  |  |  |  |  |  |  |  |  | 1 |  | Pkgs | 1 | CLKROW | CLKCOL | LUT | FF | BRAM | MMCM | PLL | DSP | GT | PCIE |  | 3.3 Pins | Pins | Banks | ThetaJA | ThetaJB
 |  | Spartan®-7, Artix®-7, Kintex®-7, Virtex®-7, Zynq®-7000 |  |  |  |  |  |  |  |  |  |  | Release: 14-Aug-2019 |  |  |  |  |  |  |  |  |  |  |  |  |  |  |  |  | FBG484 | 44 | 5 | 72 | 78600 | 157200 | 265 | 5 | 5 | 400 | 4 | 1 | 0 | 100 | 250 | 17 | 11.5 | 3.6
 |  |  |  |  |  |  |  |  |  |  |  |  |  |  |  |  |  |  |  |  |  |  |  |  |  |  |  |  |  | SBG485 | 2 | 1 |  | 53200 |  |  |  |  |  | 0
 |  |  |  |  |  |  |  |  |  |  |  |  |  |  |  |  |  |  |  |  |  |  |  |  |  |  |  |  |  | SBV485 |  | 1
Project |  |  |  |  |  |  |  |  |  |  |  |  |  |  |  |  |  |  |  |  |  |  |  |  |  |  |  |  |  | FBG676 |  |  |  |  |  |  |  |  |  | 0
Settings |  |  |  |  | Summary |  |  |  |  |  |  |  |  |  |  |  |  |  |  |  |  |  |  |  |  |  |  |  |  | FFG676
Device |  |  |  |  | Total On-Chip Power |  |  | 3.672 W |  |  | 0% | Transceiver…… |  | 0.000W |  |  |  |  |  |  |  |  |  |  |  |  |  |  |  | FBV484
Family | Zynq-7000 |  |  |  |  |  |  |  |  |  | 21.09595331% | I/O……………… |  | 0.775W |  |  |  |  |  |  |  |  |  |  |  |  |  |  |  | FBV676
Device | XC7Z030 |  |  |  | Junction Temperature |  |  | 41.4 °C |  |  | 74.26571619% | PS+FPGA Dyn.. |  | 2.727W |  |  |  |  |  |  |  |  |  |  |  |  |  |  |  | FFV676
Package | FFG676 |  |  |  | Thermal Margin |  |  | 58.6°C | 12.4W |  | 4.6383305% | Device Static….. |  | 0.170W |  |  |  |  |  |  |  |  |  |  |  |  |  | 10 | 0.12 | 0.12
Speed Grade | -2 |  |  |  | Effective ΘJA |  |  | 4.5 °C/W |  | Power supplied to off-chip devices… |  |  |  | 0.000W |  |  |  |  |  |  |  |  |  |  |  |  |  | 25 | 0.16 | 0.16
Temp Grade | Industrial |  |  |  |  |  |  |  |  |  |  |  |  |  |  |  |  |  |  |  |  |  |  |  |  |  |  | 40 | 0.22 | 0.22
Process | Typical |  |  |  | On-Chip Power |  |  |  |  |  | Power Supply |  |  |  |  |  |  |  |  |  |  |  |  |  |  |  |  | 55 | 0.35 | 0.35
Voltage ID Used | No |  |  |  | Resource |  |  | Power |  |  | Source |  | Voltage | Total (A) | Static | Active |  |  |  |  |  |  |  |  |  |  |  | 70 | 0.59 | 0.59 |  |  |  |  |  | static | 0
Characterization | Production |  |  |  |  |  | (Jump to sheet) | (W) | (%) |  | VCCINT |  | 1.000 | 2.333 | 0.042 | 2.290 |  |  |  |  |  |  |  |  |  |  |  | 85 | 0.99 | 0.99 |  |  |  |  |  |  | 1
 |  |  |  |  | Core Dynamic |  |  | 0.677 | 18.44373088 |  | VCCBRAM |  | 1.000 | 0.027 | 0.004 | 0.023 |  |  |  |  |  |  |  |  |  |  |  | 100 | 1.63 | 1.63 |  |  |  |  |  |  | 1
Environment |  |  |  |  |  |  |  | 0.954 | 25.98311757 |  | VCCAUX |  | 1.800 | 0.411 | 0.019 | 0.391 |  |  |  |  |  |  |  |  |  |  |  |  |  |  |  |  |  |  |  |  | 1
Junction Temperature |  |  | 41.4 °C |  |  |  |  | 0.379 | 10.31783567 |  | VCCAUX_IO |  | 2.000 | 0.000 | 0.000 | 0.000 |  |  |  |  |  |  |  |  |  |  |  | 0.97 | 0.15 |  |  |  |  |  |  |  | 1
Ambient Temp | 25.0 °C |  |  |  |  |  |  | 0.147 | 4.002152813 |  | VCCO 3.3V |  | 3.300 | 0.000 | 0.000 | 0.000 |  |  |  |  |  |  |  |  |  |  |  | 0.985 | 0.15 |  |  |  |  |  |  | 0 | 1
Effective ΘJA |  |  | 4.5 °C/W |  |  |  |  | 0.114 | 3.098489091 |  | VCCO 2.5V |  | 2.500 | 0.000 | 0.000 | 0.000 |  |  |  |  |  |  |  |  |  |  |  | 1 | 0.16 |  |  |  |  |  |  | 0 | 1
Airflow | 250 LFM |  |  |  |  |  |  | 0.124 | 3.369455182 |  | VCCO 1.8V |  | 1.800 | 0.000 | 0.000 | 0.000 |  |  |  |  |  |  |  |  |  |  |  | 1.015 | 0.16 |  |  |  |  |  |  | 0 | 1
Heat Sink | None |  |  |  |  |  |  | 0.332 | 9.050934987 |  | VCCO 1.5V |  | 1.500 | 0.324 | 0.001 | 0.323 |  |  |  |  |  |  |  |  |  |  |  | 1.03 | 0.16 |  |  |  |  |  |  | 0.001 | 1
ΘSA | 0.0 °C/W |  |  |  |  |  |  | 0.000 | 0 |  | VCCO 1.35V |  | 1.350 | 0.000 | 0.000 | 0.000 |  |  |  |  |  |  |  |  |  |  |  |  |  |  |  |  |  |  |  | 0 | 1
Board Selection | Medium (10"x10") |  |  |  | I/O |  |  | 0.775 | 21.09595331 |  | VCCO 1.2V |  | 1.200 | 0.000 | 0.000 | 0.000 |  |  |  |  |  |  |  |  |  |  |  |  |  |  |  |  |  |  |  | 0 | 1
# of Board Layers | 8 to 11 |  |  |  | Transceiver |  |  | 0.000 | 0 |  | MGTVCCAUX |  | 1.800 | 0.000 | 0.000 | 0.000 |  |  |  |  |  |  |  |  |  |  |  |  |  |  |  |  |  |  |  |  | 1
ΘJB | 2.6 °C/W |  |  |  |  |  |  | 0.000 | 0 |  | MGTAVCC |  | 1.000 | 0.000 | 0.000 | 0.000 |  |  |  |  |  |  |  |  |  |  |  |  |  |  |  |  |  |  |  |  | 1
Board Temperature | 25.0 °C |  |  |  | PS Dynamic Static |  |  | 0.000 | 0 |  | MGTAVTT |  | 1.200 | 0.000 | 0.000 | 0.000 |  |  |  |  |  |  |  |  |  |  |  | Temp | 50 | 85 | 100 |  |  |  |  |  | 1
 |  |  |  |  |  |  |  | 0.052 | 1.406183586 |  | VCCPINT |  | 1.000 | 0.028 | 0.028 | 0.000 |  |  |  |  |  |  |  |  |  |  |  | Typical (1.0V) | 0.30 | 0.99 | 1.632003614 |  |  |  |  | 0.02764214126 | 1
PL Implementation |  |  |  |  | PL Static | 0.170 |  | 0.119 | 3.232146914 |  | VCCPAUX |  | 1.800 | 0.010 | 0.010 | 0.000 |  |  |  |  |  |  |  |  |  |  |  | Maximum (1.03V) | 0.50 | 1.53 | 2.428447891 |  |  |  |  | 0.01033 | 1
Usage/Optimization | Power Optimization |  |  | 2 |  |  |  |  |  |  | VCCPLL |  | 1.800 | 0.003 | 0.003 | 0.000 |  |  |  |  |  |  |  |  |  |  |  |  |  |  |  |  |  |  |  | 0.003 | 1
 |  |  |  |  |  |  |  |  |  |  | VCCO_DDR |  | 1.500 | 0.000 | 0.000 | 0.000 |  |  |  |  |  |  |  |  |  |  |  |  |  |  |  |  |  |  |  |  | 1
Messages |  |  |  |  |  |  |  |  |  |  | VCCO_MIO0 |  | 1.800 | 0.000 | 0.000 | 0.000 |  |  |  |  |  |  |  |  |  |  |  |  |  |  |  |  |  |  |  |  | 1
 |  |  |  |  |  |  |  |  |  |  | VCCO_MIO1 |  | 1.800 | 0.000 | 0.000 | 0.000 |  |  |  |  |  |  |  |  |  |  |  |  |  |  |  |  |  |  |  |  | 1
 |  |  |  |  |  |  |  |  |  |  | VCCADC |  | 1.800 | 0.020 | 0.020 | 0.000 |  |  |  |  |  |  |  |  |  |  |  |  |  |  |  |  |  |  |  | 0.02 | 1
XILINX Power Advantage (check for updates) (http://www.xilinx.com/products/technology/power/index.htm) |  |  |  | File Support Request (WebCase) (https://www.xilinx.com/support.html) |  |  |  |  |  |  | Xilinx Power Estimator User Guide (http://www.xilinx.com/cgi-bin/docs/rdoc?l=en;v=latest;d=ug440-xilinx-power-estimator.pdf)
© Copyright 1994-2019 Xilinx, Inc. All Rights Reserved |  |  |  | Introduction to XPE (video) (http://www.xilinx.com/training/vivado/using-the-xilinx-power-estimator.htm) |  |  |  | Whitepaper - 7 Steps for Worst Case Power Estimation (http://www.xilinx.com/support/documentation/white_papers/wp353.pdf)
Legend |  | User Entry |  |  | Calculated Value |  | Summary Value |  |  | User Override |  | Warning |  | Error
 |  |  |  |  |  |  |  |  |  |  |  |  |  |  |  |  |  |  | JEDEC | 7.7
 |  |  |  |  | Piccq | Iccauxq | Tj | Iccq |  |  |  |  |  |  |  |  |  |  | BoardType | 2 |  | Airflow | Opt | Leakage | 0.119 | 42.17916562 | Utilization
 |  |  |  | 0.003913727789 | 0.02760204275 | 0.01947621526 | 41.07077335 | 0.04210470794 | Non-int Leakage | 0.0145 |  |  |  |  |  |  |  |  | BoardLyr | 1 |  | N/A | Default | CLOCK | 0.6772679631 | 3.913727789
 |  |  | Temp | 41.07077335 | 0.02764150845 | 0.01949635691 | 41.11298745 | 0.04217799035 | Scaled ICCQ_D | 0.0215 |  |  |  | Max Adj | Typ Adj |  |  |  | Airflow | 1 |  | 0 | Power Optimization | LOGIC | 0.9541200325 | 19.49667978
 |  |  | Initial | 40.84595157 | 0.02764213127 | 0.01949667469 | 41.11365315 | 0.04217914708 | Non-aux Leakage | 0.0230 |  |  | MMF Factor | 1 | 0.7 |  |  |  | Heatsink | 3 |  | 250 | Powered Off | BRAM | 0.37887885 | 0
 |  |  | Max | 125 | 0.0276421411 | 0.0194966797 | 41.11366366 | 0.04217916533 | Scaled ICCAUXQ_D | 0.0599 |  |  | MMF Aux | 1 | 1.8 |  |  |  | Pkg size | 729 |  | 500 | Y44:Y46 | DSP | 0.146962125 | 0
 |  |  |  |  | 0.02764214125 | 0.01949667978 | 41.11366382 | 0.04217916562 | Iccint_c1 | 1.580176729e-05 |  |  | MMF Bram | 1 | 1 |  |  |  | Air | 228.6236854 |  | 750 |  | PLL | 0.1137788991 | 0
 |  |  |  |  | 0.02764214126 | 0.01949667978 | 41.11366383 | 0.04217916562 | Iccint_c2 | 0.0062 |  |  | VID Factor | 1 |  |  |  |  | ThetaSA | 0.000 |  | X45:X48 |  | MMCM | 0.1237289821 | 0
 |  |  |  |  | 0.02764214126 | 0.01949667978 | 41.11366383 | 0.04217916562 | Iccintq_d | 0.0296 |  |  | Bali Factor | 1 |  |  |  |  | ThetaCS | 0.100 |  |  |  | PHASER | 0.332357284 | 1
 |  |  |  |  |  |  |  |  | Iccintq_des | 0.0308 |  |  | Vccint | 4.506291548e-06 | 1.580176729e-05 | 0.006162041921 | 0.6424429568 | 7.635943638 | ThetaJB | 3.600 |  |  |  | PCIE | 0 | 0
 |  |  |  |  |  |  |  |  | Iccaux_c1 | -2.110976902e-05 |  |  | Vccaux | 2.829620252e-07 | -2.110976902e-05 | 0.002704211844 | 0.07123081058 | 3.990463226 | ThetaJA | 4.468 |  |  |  | IO | 0.7746596075 | 0
 |  |  |  |  |  |  |  |  | Iccaux_c2 | 0.0027 |  |  | Vccbram | 2.275361095e-07 | -4.701012945e-06 | 3.366112371e-05 | 0.02426550549 | 0.141661515 | ThetaJX | 4.557 |  |  |  | GTX | 0 | 0
 |  |  |  |  |  |  |  |  | Iccauxq_d | 0.0072 |  |  |  |  |  |  |  |  | eThetaJA | 4.468 |  |  |  | PS | 0 | 0
 |  |  |  |  |  |  |  |  | Iccoq | 0.0010 |  |  |  |  |  |  |  |  | TJA-Top | 7.700 |  |  |  |  |  | 0
 |  |  |  |  |  |  |  |  | Iccbram_c1 | -4.701012945e-06 |  |  |  |  |  |  |  |  | TJ | 34.008 |  |  |  |  |  | 27.64214126
 |  |  |  |  |  |  |  |  | Iccbram_c2 | 3.366112371e-05 |  |  |  |  |  |  |  |  | eThetaJA | 2.453 |  |  |  |  |  | 10.33
 |  |  |  |  |  |  |  |  | Iccbramq | 0.0016 | 0.001197 | 1.808391493 |  |  |  |  |  |  | Power | 3.593 |  |  |  |  |  | 3
 |  |  |  |  |  |  |  |  | Process | 1.0000 |  |  |  |  |  |  |  |  | Power2 |  |  |  |  |  |  | 0
 |  |  |  |  |  |  |  |  | I-Grade | 0.6424 |  |  |  |  |  |  |  |  | Temp | 52.668 |  |  |  |  |  | 0
 |  |  |  |  |  |  |  |  | Q-Grade | 7.6359 |  |  |  |  |  |  |  |  | Temp | 33.815 |  |  |  |  |  | 0
 |  |  |  |  |  |  |  |  | I-Grade | 0.0712 |  |  |  |  |  |  |  |  | Temp | 52.31 |  |  |  |  |  | 20
 |  |  |  |  |  |  |  |  | Q-Grade | 3.9905
 |  |  |  |  |  |  |  |  | I-Grade | 0.0243 |  |  |  | PowerUp | Int | Aux | I/O | Aux_io | Bram | Avcc | Avtt | GTVccaux
 |  |  |  |  |  |  |  |  | Q-Grade | 0.1417 |  |  |  | Adder | 0.9 | 0.06 | 0.09 | 0.04 | 0.09 | 0.112 | 0.064 | 0.04
 |  |  |  |  |  |  |  |  | Vcc_c1 | 0.0885 |  |  |  | Min | 0 | 0 | 0 | 0 | 0 | 0 | 0 | 0
 |  |  |  |  |  |  |  |  | Vcc_c2 | 2.4249
 |  |  |  |  |  |  |  |  | VccScale | 0.7001
 |  |  |  |  |  |  |  |  | VccAuxScale | 1.8
 |  |  |  |  |  |  |  |  | VccBramScale | 1.0001
 |  |  |  |  |  |  |  |  | AVccScale | 1.0001
 |  |  |  |  |  |  |  |  | Max bram | 0.01125099757
 |  |  |  |  |  |  |  |  | Max PS | 0.2028414147
 |  |  |  |  |  |  |  |  | Max Aux | 0.0816157732
 |  |  |  |  |  |  |  |  | Max Int | 0.5999315807
 |  |  |  |  |  |  |  |  | Max Ambient | 80.35358407
 |  |  |  |  |  |  |  |  | AuxSpecialFact | 1
 |  |  |  |  |  |  |  |  | Oly | 0

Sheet: Snapshot
 |  |  | Power Comparison Snapshots
Settings | Snapshot_1
 | XPE: 2019.1.2

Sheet: GTX
GTX Transceiver Power |  |  |  |  |  |  |  |  |  |  |  |  |  |  |  |  |  |  |  |  |  |  |  | FALSE | 1 | 10.3125 |  | CPLL VCO range (MHz) | LC VCO range (MHz) |  |  | Raised Voltage |  |  |  |  |  |  |  |  |  |  |  | AV2:AV17
 |  |  |  |  |  |  |  |  |  |  |  |  |  |  |  |  |  |  |  |  |  |  |  |  |  |  |  | 1.2 | 5.93 | 9.8 |  | 0 |  |  |  |  |  |  |  |  |  |  | PCIe |  | 250 | 269
Active Current |  |  |  | Power |  |  |  |  | 0.000W |  | Utilization |  |  |  |  |  |  | Transceivers User Guide (http://www.xilinx.com/support/documentation/user_guides/ug476_7Series_Transceivers.pdf) |  |  |  |  |  |  | Iccq | 0 |  | 3.3 | 8 | 12.5 |  |  |  |  |  |  |  |  |  |  |  |  |  |  | 300 | 336
Source |  | Active |  |  |  |  |  |  |  |  | GTX Channels |  | 0 | 0% |  |  |  |  |  |  |  |  |  |  |  |  |  |  |  |  |  |  |  |  |  |  |  |  |  |  |  |  |  |  | 350 | 407
VCCINT | 1.000V | 0.000A |  | Source | Power |  | PCIe | PCS | PMA |  | PCIe Blocks |  | 0 | 0% |  |  |  | XPE User Guide (http://www.xilinx.com/cgi-bin/docs/rdoc?l=en;v=latest;d=ug440-xilinx-power-estimator.pdf) |  |  |  |  |  |  |  |  |  |  |  |  |  |  |  |  |  |  |  |  |  |  |  |  |  |  | 400 | 474
MGTVCCAUX | 1.800V | 0.000A |  | VCCINT | 0.000W |  | 0.000W | 0.000W | 0.000W |  |  |  |  |  |  |  |  |  |  |  |  |  |  |  |  |  |  |  |  |  |  |  |  |  |  |  |  |  |  |  |  |  |  |  | 450 | 543
MGTAVCC | 1.000V | 0.000A |  | MGTVCCAUX | 0.000W |  |  |  |  |  | Power Planes |  | 0 |  |  |  |  | Introduction to XPE (video) (http://www.xilinx.com/training/vivado/using-the-xilinx-power-estimator.htm) |  |  |  |  |  |  |  |  |  |  |  |  |  |  |  |  |  |  |  |  |  |  |  |  |  |  | 500 | 609
MGTAVTT | 1.200V | 0.000A |  | MGTAVCC | 0.000W |  |  |  |  |  |  |  |  |  |  |  |  |  |  |  |  |  |  |  |  |  |  |  |  |  |  |  |  |  |  |  |  |  |  |  |  |  |  |  | 550 | 677
 |  |  |  | MGTAVTT | 0.000W | 0% of total on-chip power 3.672W |  |  |  |  | BSCAN |  |  |  |  |  |  |  |  |  |  |  |  |  |  |  |  |  |  |  |  |  |  |  |  |  |  |  |  |  |  |  |  |  | 600 | 741
 |  |  |  |  |  |  |  |  |  |  |  |  |  |  |  |  |  |  |  |  |  |  |  |  |  |  |  |  |  |  |  |  |  |  |  |  |  |  |  |  |  |  |  |  | 650 | 807
 |  |  |  |  |  |  |  | RX |  |  |  | TX |  |  |  |  |  |  |  |  |  |  |  |  |  |  |  |  |  |  |  |  |  |  |  |  |  |  |  |  |  |  |  |  | 700 | 866
Name |  |  | GTX Channels | Operational Mode | EyeScan | Power Mode | Channels Sharing QPLL | Clock Source | Data Rate (Gb/s) | Data Path | Data Mode | Clock Source | Data Rate (Gb/s) | Data Path | Data Mode | O/P (mV) | OOB Used | Hard PCIe | VCCINT Power (W) | MGTVCCAUX Power (W) | MGTAVCC Power (W) | MGTAVTT Power (W) |  | Operate Mode | Quads | RX VCO LC (MHz) | TX VCO LC (MHz) | RX VCO CPLL (MHz) | TX VCO CPLL (MHz) | RX USERCLK | TX USERCLK | RX Power Mode | TX Voltage Swing Current | AVTT Current (CPLL) | AVTT Current (LC) | AVCC Current (RX) | AVCC Current (TX) | AVCC Current (CPLL) | AVCC Current (LC) | AVCC CLK | AVTT CLK |  |  | PCIe | 750 | 924
 |  |  |  | Transceiver | Off | Low Power | 4 | QPLL | 5.0000 | 32 | 8b/10b | QPLL | 5.0000 | 32 | 8b/10b | 269 | No |  | 0.000 | 0.000 | 0.000 | 0.000 |  | 3 | 0 | 10000 | 10000 | 2500 | 2500 | 125 | 125 | 0 | 5.575 | 0 | 7.579332025 | 53.875 | 43.53733333 | 0 | 16.46694215 | 25.6 | 1.55 | 10 | 10 | 0 | 800 | 973
 |  |  |  | Transceiver | Off | Low Power | 4 | QPLL | 5.0000 | 32 | 8b/10b | QPLL | 5.0000 | 32 | 8b/10b | 269 | No |  | 0.000 | 0.000 | 0.000 | 0.000 |  | 3 | 0 | 10000 | 10000 | 2500 | 2500 | 125 | 125 | 0 | 5.575 | 0 | 7.579332025 | 53.875 | 43.53733333 | 0 | 16.46694215 | 25.6 | 1.55 | 10 | 10 | 0 | 850 | 1018
 |  |  |  | Transceiver | Off | Low Power | 4 | QPLL | 5.0000 | 32 | 8b/10b | QPLL | 5.0000 | 32 | 8b/10b | 269 | No |  | 0.000 | 0.000 | 0.000 | 0.000 |  | 3 | 0 | 10000 | 10000 | 2500 | 2500 | 125 | 125 | 0 | 5.575 | 0 | 7.579332025 | 53.875 | 43.53733333 | 0 | 16.46694215 | 25.6 | 1.55 | 10 | 10 | 0 | 900 | 1056
 |  |  |  | Transceiver | Off | Low Power | 4 | QPLL | 5.0000 | 32 | 8b/10b | QPLL | 5.0000 | 32 | 8b/10b | 269 | No |  | 0.000 | 0.000 | 0.000 | 0.000 |  | 3 | 0 | 10000 | 10000 | 2500 | 2500 | 125 | 125 | 0 | 5.575 | 0 | 7.579332025 | 53.875 | 43.53733333 | 0 | 16.46694215 | 25.6 | 1.55 | 10 | 10 | 0 | 950 | 1092
 |  |  |  | Transceiver | Off | Low Power | 4 | QPLL | 5.0000 | 32 | 8b/10b | QPLL | 5.0000 | 32 | 8b/10b | 269 | No |  | 0.000 | 0.000 | 0.000 | 0.000 |  | 3 | 0 | 10000 | 10000 | 2500 | 2500 | 125 | 125 | 0 | 5.575 | 0 | 7.579332025 | 53.875 | 43.53733333 | 0 | 16.46694215 | 25.6 | 1.55 | 10 | 10 | 0 | 1000 | 1119
 |  |  |  | Transceiver | Off | Low Power | 4 | QPLL | 5.0000 | 32 | 8b/10b | QPLL | 5.0000 | 32 | 8b/10b | 269 | No |  | 0.000 | 0.000 | 0.000 | 0.000 |  | 3 | 0 | 10000 | 10000 | 2500 | 2500 | 125 | 125 | 0 | 5.575 | 0 | 7.579332025 | 53.875 | 43.53733333 | 0 | 16.46694215 | 25.6 | 1.55 | 10 | 10 | 0
 |  |  |  | Transceiver | Off | Low Power | 4 | QPLL | 5.0000 | 32 | 8b/10b | QPLL | 5.0000 | 32 | 8b/10b | 269 | No |  | 0.000 | 0.000 | 0.000 | 0.000 |  | 3 | 0 | 10000 | 10000 | 2500 | 2500 | 125 | 125 | 0 | 5.575 | 0 | 7.579332025 | 53.875 | 43.53733333 | 0 | 16.46694215 | 25.6 | 1.55 | 10 | 10 | 0
 |  |  |  | Transceiver | Off | Low Power | 4 | QPLL | 5.0000 | 32 | 8b/10b | QPLL | 5.0000 | 32 | 8b/10b | 269 | No |  | 0.000 | 0.000 | 0.000 | 0.000 |  | 3 | 0 | 10000 | 10000 | 2500 | 2500 | 125 | 125 | 0 | 5.575 | 0 | 7.579332025 | 53.875 | 43.53733333 | 0 | 16.46694215 | 25.6 | 1.55 | 10 | 10 | 0
 |  |  |  | Transceiver | Off | Low Power | 4 | QPLL | 5.0000 | 32 | 8b/10b | QPLL | 5.0000 | 32 | 8b/10b | 269 | No |  | 0.000 | 0.000 | 0.000 | 0.000 |  | 3 | 0 | 10000 | 10000 | 2500 | 2500 | 125 | 125 | 0 | 5.575 | 0 | 7.579332025 | 53.875 | 43.53733333 | 0 | 16.46694215 | 25.6 | 1.55 | 10 | 10 | 0
 |  |  |  | Transceiver | Off | Low Power | 4 | QPLL | 5.0000 | 32 | 8b/10b | QPLL | 5.0000 | 32 | 8b/10b | 269 | No |  | 0.000 | 0.000 | 0.000 | 0.000 |  | 3 | 0 | 10000 | 10000 | 2500 | 2500 | 125 | 125 | 0 | 5.575 | 0 | 7.579332025 | 53.875 | 43.53733333 | 0 | 16.46694215 | 25.6 | 1.55 | 10 | 10 | 0
 |  |  |  | Transceiver | Off | Low Power | 4 | QPLL | 5.0000 | 32 | 8b/10b | QPLL | 5.0000 | 32 | 8b/10b | 269 | No |  | 0.000 | 0.000 | 0.000 | 0.000 |  | 3 | 0 | 10000 | 10000 | 2500 | 2500 | 125 | 125 | 0 | 5.575 | 0 | 7.579332025 | 53.875 | 43.53733333 | 0 | 16.46694215 | 25.6 | 1.55 | 10 | 10 | 0
 |  |  |  | Transceiver | Off | Low Power | 4 | QPLL | 5.0000 | 32 | 8b/10b | QPLL | 5.0000 | 32 | 8b/10b | 269 | No |  | 0.000 | 0.000 | 0.000 | 0.000 |  | 3 | 0 | 10000 | 10000 | 2500 | 2500 | 125 | 125 | 0 | 5.575 | 0 | 7.579332025 | 53.875 | 43.53733333 | 0 | 16.46694215 | 25.6 | 1.55 | 10 | 10 | 0
 |  |  |  | Transceiver | Off | Low Power | 4 | QPLL | 5.0000 | 32 | 8b/10b | QPLL | 5.0000 | 32 | 8b/10b | 269 | No |  | 0.000 | 0.000 | 0.000 | 0.000 |  | 3 | 0 | 10000 | 10000 | 2500 | 2500 | 125 | 125 | 0 | 5.575 | 0 | 7.579332025 | 53.875 | 43.53733333 | 0 | 16.46694215 | 25.6 | 1.55 | 10 | 10 | 0
 |  |  |  | Transceiver | Off | Low Power | 4 | QPLL | 5.0000 | 32 | 8b/10b | QPLL | 5.0000 | 32 | 8b/10b | 269 | No |  | 0.000 | 0.000 | 0.000 | 0.000 |  | 3 | 0 | 10000 | 10000 | 2500 | 2500 | 125 | 125 | 0 | 5.575 | 0 | 7.579332025 | 53.875 | 43.53733333 | 0 | 16.46694215 | 25.6 | 1.55 | 10 | 10 | 0
 |  |  |  | Transceiver | Off | Low Power | 4 | QPLL | 5.0000 | 32 | 8b/10b | QPLL | 5.0000 | 32 | 8b/10b | 269 | No |  | 0.000 | 0.000 | 0.000 | 0.000 |  | 3 | 0 | 10000 | 10000 | 2500 | 2500 | 125 | 125 | 0 | 5.575 | 0 | 7.579332025 | 53.875 | 43.53733333 | 0 | 16.46694215 | 25.6 | 1.55 | 10 | 10 | 0
 |  |  |  | Transceiver | Off | Low Power | 4 | QPLL | 5.0000 | 32 | 8b/10b | QPLL | 5.0000 | 32 | 8b/10b | 269 | No |  | 0.000 | 0.000 | 0.000 | 0.000 |  | 3 | 0 | 10000 | 10000 | 2500 | 2500 | 125 | 125 | 0 | 5.575 | 0 | 7.579332025 | 53.875 | 43.53733333 | 0 | 16.46694215 | 25.6 | 1.55 | 10 | 10 | 0
 |  |  |  | Transceiver | Off | Low Power | 4 | QPLL | 5.0000 | 32 | 8b/10b | QPLL | 5.0000 | 32 | 8b/10b | 269 | No |  | 0.000 | 0.000 | 0.000 | 0.000 |  | 3 | 0 | 10000 | 10000 | 2500 | 2500 | 125 | 125 | 0 | 5.575 | 0 | 7.579332025 | 53.875 | 43.53733333 | 0 | 16.46694215 | 25.6 | 1.55 | 10 | 10 | 0
 |  |  |  | Transceiver | Off | Low Power | 4 | QPLL | 5.0000 | 32 | 8b/10b | QPLL | 5.0000 | 32 | 8b/10b | 269 | No |  | 0.000 | 0.000 | 0.000 | 0.000 |  | 3 | 0 | 10000 | 10000 | 2500 | 2500 | 125 | 125 | 0 | 5.575 | 0 | 7.579332025 | 53.875 | 43.53733333 | 0 | 16.46694215 | 25.6 | 1.55 | 10 | 10 | 0
 |  |  |  | Transceiver | Off | Low Power | 4 | QPLL | 5.0000 | 32 | 8b/10b | QPLL | 5.0000 | 32 | 8b/10b | 269 | No |  | 0.000 | 0.000 | 0.000 | 0.000 |  | 3 | 0 | 10000 | 10000 | 2500 | 2500 | 125 | 125 | 0 | 5.575 | 0 | 7.579332025 | 53.875 | 43.53733333 | 0 | 16.46694215 | 25.6 | 1.55 | 10 | 10 | 0
 |  |  |  | Transceiver | Off | Low Power | 4 | QPLL | 5.0000 | 32 | 8b/10b | QPLL | 5.0000 | 32 | 8b/10b | 269 | No |  | 0.000 | 0.000 | 0.000 | 0.000 |  | 3 | 0 | 10000 | 10000 | 2500 | 2500 | 125 | 125 | 0 | 5.575 | 0 | 7.579332025 | 53.875 | 43.53733333 | 0 | 16.46694215 | 25.6 | 1.55 | 10 | 10 | 0
 |  |  |  | Transceiver | Off | Low Power | 4 | QPLL | 5.0000 | 32 | 8b/10b | QPLL | 5.0000 | 32 | 8b/10b | 269 | No |  | 0.000 | 0.000 | 0.000 | 0.000 |  | 3 | 0 | 10000 | 10000 | 2500 | 2500 | 125 | 125 | 0 | 5.575 | 0 | 7.579332025 | 53.875 | 43.53733333 | 0 | 16.46694215 | 25.6 | 1.55 | 10 | 10 | 0
 |  |  |  | Transceiver | Off | Low Power | 4 | QPLL | 5.0000 | 32 | 8b/10b | QPLL | 5.0000 | 32 | 8b/10b | 269 | No |  | 0.000 | 0.000 | 0.000 | 0.000 |  | 3 | 0 | 10000 | 10000 | 2500 | 2500 | 125 | 125 | 0 | 5.575 | 0 | 7.579332025 | 53.875 | 43.53733333 | 0 | 16.46694215 | 25.6 | 1.55 | 10 | 10 | 0
 |  |  |  | Transceiver | Off | Low Power | 4 | QPLL | 5.0000 | 32 | 8b/10b | QPLL | 5.0000 | 32 | 8b/10b | 269 | No |  | 0.000 | 0.000 | 0.000 | 0.000 |  | 3 | 0 | 10000 | 10000 | 2500 | 2500 | 125 | 125 | 0 | 5.575 | 0 | 7.579332025 | 53.875 | 43.53733333 | 0 | 16.46694215 | 25.6 | 1.55 | 10 | 10 | 0
 |  |  |  | Transceiver | Off | Low Power | 4 | QPLL | 5.0000 | 32 | 8b/10b | QPLL | 5.0000 | 32 | 8b/10b | 269 | No |  | 0.000 | 0.000 | 0.000 | 0.000 |  | 3 | 0 | 10000 | 10000 | 2500 | 2500 | 125 | 125 | 0 | 5.575 | 0 | 7.579332025 | 53.875 | 43.53733333 | 0 | 16.46694215 | 25.6 | 1.55 | 10 | 10 | 0
 |  |  |  | Transceiver | Off | Low Power | 4 | QPLL | 5.0000 | 32 | 8b/10b | QPLL | 5.0000 | 32 | 8b/10b | 269 | No |  | 0.000 | 0.000 | 0.000 | 0.000 |  | 3 | 0 | 10000 | 10000 | 2500 | 2500 | 125 | 125 | 0 | 5.575 | 0 | 7.579332025 | 53.875 | 43.53733333 | 0 | 16.46694215 | 25.6 | 1.55 | 10 | 10 | 0
 |  |  |  | Transceiver | Off | Low Power | 4 | QPLL | 5.0000 | 32 | 8b/10b | QPLL | 5.0000 | 32 | 8b/10b | 269 | No |  | 0.000 | 0.000 | 0.000 | 0.000 |  | 3 | 0 | 10000 | 10000 | 2500 | 2500 | 125 | 125 | 0 | 5.575 | 0 | 7.579332025 | 53.875 | 43.53733333 | 0 | 16.46694215 | 25.6 | 1.55 | 10 | 10 | 0
 |  |  |  | Transceiver | Off | Low Power | 4 | QPLL | 5.0000 | 32 | 8b/10b | QPLL | 5.0000 | 32 | 8b/10b | 269 | No |  | 0.000 | 0.000 | 0.000 | 0.000 |  | 3 | 0 | 10000 | 10000 | 2500 | 2500 | 125 | 125 | 0 | 5.575 | 0 | 7.579332025 | 53.875 | 43.53733333 | 0 | 16.46694215 | 25.6 | 1.55 | 10 | 10 | 0
 |  |  |  | Transceiver | Off | Low Power | 4 | QPLL | 5.0000 | 32 | 8b/10b | QPLL | 5.0000 | 32 | 8b/10b | 269 | No |  | 0.000 | 0.000 | 0.000 | 0.000 |  | 3 | 0 | 10000 | 10000 | 2500 | 2500 | 125 | 125 | 0 | 5.575 | 0 | 7.579332025 | 53.875 | 43.53733333 | 0 | 16.46694215 | 25.6 | 1.55 | 10 | 10 | 0
 |  |  |  | Transceiver | Off | Low Power | 4 | QPLL | 5.0000 | 32 | 8b/10b | QPLL | 5.0000 | 32 | 8b/10b | 269 | No |  | 0.000 | 0.000 | 0.000 | 0.000 |  | 3 | 0 | 10000 | 10000 | 2500 | 2500 | 125 | 125 | 0 | 5.575 | 0 | 7.579332025 | 53.875 | 43.53733333 | 0 | 16.46694215 | 25.6 | 1.55 | 10 | 10 | 0
 |  |  |  | Transceiver | Off | Low Power | 4 | QPLL | 5.0000 | 32 | 8b/10b | QPLL | 5.0000 | 32 | 8b/10b | 269 | No |  | 0.000 | 0.000 | 0.000 | 0.000 |  | 3 | 0 | 10000 | 10000 | 2500 | 2500 | 125 | 125 | 0 | 5.575 | 0 | 7.579332025 | 53.875 | 43.53733333 | 0 | 16.46694215 | 25.6 | 1.55 | 10 | 10 | 0
 |  |  |  | Transceiver | Off | Low Power | 4 | QPLL | 5.0000 | 32 | 8b/10b | QPLL | 5.0000 | 32 | 8b/10b | 269 | No |  | 0.000 | 0.000 | 0.000 | 0.000 |  | 3 | 0 | 10000 | 10000 | 2500 | 2500 | 125 | 125 | 0 | 5.575 | 0 | 7.579332025 | 53.875 | 43.53733333 | 0 | 16.46694215 | 25.6 | 1.55 | 10 | 10 | 0
 |  |  |  | Transceiver | Off | Low Power | 4 | QPLL | 5.0000 | 32 | 8b/10b | QPLL | 5.0000 | 32 | 8b/10b | 269 | No |  | 0.000 | 0.000 | 0.000 | 0.000 |  | 3 | 0 | 10000 | 10000 | 2500 | 2500 | 125 | 125 | 0 | 5.575 | 0 | 7.579332025 | 53.875 | 43.53733333 | 0 | 16.46694215 | 25.6 | 1.55 | 10 | 10 | 0
 |  |  |  | Transceiver | Off | Low Power | 4 | QPLL | 5.0000 | 32 | 8b/10b | QPLL | 5.0000 | 32 | 8b/10b | 269 | No |  | 0.000 | 0.000 | 0.000 | 0.000 |  | 3 | 0 | 10000 | 10000 | 2500 | 2500 | 125 | 125 | 0 | 5.575 | 0 | 7.579332025 | 53.875 | 43.53733333 | 0 | 16.46694215 | 25.6 | 1.55 | 10 | 10 | 0
 |  |  |  | Transceiver | Off | Low Power | 4 | QPLL | 5.0000 | 32 | 8b/10b | QPLL | 5.0000 | 32 | 8b/10b | 269 | No |  | 0.000 | 0.000 | 0.000 | 0.000 |  | 3 | 0 | 10000 | 10000 | 2500 | 2500 | 125 | 125 | 0 | 5.575 | 0 | 7.579332025 | 53.875 | 43.53733333 | 0 | 16.46694215 | 25.6 | 1.55 | 10 | 10 | 0
 |  |  |  | Transceiver | Off | Low Power | 4 | QPLL | 5.0000 | 32 | 8b/10b | QPLL | 5.0000 | 32 | 8b/10b | 269 | No |  | 0.000 | 0.000 | 0.000 | 0.000 |  | 3 | 0 | 10000 | 10000 | 2500 | 2500 | 125 | 125 | 0 | 5.575 | 0 | 7.579332025 | 53.875 | 43.53733333 | 0 | 16.46694215 | 25.6 | 1.55 | 10 | 10 | 0
 |  |  |  | Transceiver | Off | Low Power | 4 | QPLL | 5.0000 | 32 | 8b/10b | QPLL | 5.0000 | 32 | 8b/10b | 269 | No |  | 0.000 | 0.000 | 0.000 | 0.000 |  | 3 | 0 | 10000 | 10000 | 2500 | 2500 | 125 | 125 | 0 | 5.575 | 0 | 7.579332025 | 53.875 | 43.53733333 | 0 | 16.46694215 | 25.6 | 1.55 | 10 | 10 | 0
 |  |  |  | Transceiver | Off | Low Power | 4 | QPLL | 5.0000 | 32 | 8b/10b | QPLL | 5.0000 | 32 | 8b/10b | 269 | No |  | 0.000 | 0.000 | 0.000 | 0.000 |  | 3 | 0 | 10000 | 10000 | 2500 | 2500 | 125 | 125 | 0 | 5.575 | 0 | 7.579332025 | 53.875 | 43.53733333 | 0 | 16.46694215 | 25.6 | 1.55 | 10 | 10 | 0
 |  |  |  | Transceiver | Off | Low Power | 4 | QPLL | 5.0000 | 32 | 8b/10b | QPLL | 5.0000 | 32 | 8b/10b | 269 | No |  | 0.000 | 0.000 | 0.000 | 0.000 |  | 3 | 0 | 10000 | 10000 | 2500 | 2500 | 125 | 125 | 0 | 5.575 | 0 | 7.579332025 | 53.875 | 43.53733333 | 0 | 16.46694215 | 25.6 | 1.55 | 10 | 10 | 0
 |  |  |  | Transceiver | Off | Low Power | 4 | QPLL | 5.0000 | 32 | 8b/10b | QPLL | 5.0000 | 32 | 8b/10b | 269 | No |  | 0.000 | 0.000 | 0.000 | 0.000 |  | 3 | 0 | 10000 | 10000 | 2500 | 2500 | 125 | 125 | 0 | 5.575 | 0 | 7.579332025 | 53.875 | 43.53733333 | 0 | 16.46694215 | 25.6 | 1.55 | 10 | 10 | 0
 |  |  |  | Transceiver | Off | Low Power | 4 | QPLL | 5.0000 | 32 | 8b/10b | QPLL | 5.0000 | 32 | 8b/10b | 269 | No |  | 0.000 | 0.000 | 0.000 | 0.000 |  | 3 | 0 | 10000 | 10000 | 2500 | 2500 | 125 | 125 | 0 | 5.575 | 0 | 7.579332025 | 53.875 | 43.53733333 | 0 | 16.46694215 | 25.6 | 1.55 | 10 | 10 | 0
 |  |  |  | Transceiver | Off | Low Power | 4 | QPLL | 5.0000 | 32 | 8b/10b | QPLL | 5.0000 | 32 | 8b/10b | 269 | No |  | 0.000 | 0.000 | 0.000 | 0.000 |  | 3 | 0 | 10000 | 10000 | 2500 | 2500 | 125 | 125 | 0 | 5.575 | 0 | 7.579332025 | 53.875 | 43.53733333 | 0 | 16.46694215 | 25.6 | 1.55 | 10 | 10 | 0
 |  |  |  | Transceiver | Off | Low Power | 4 | QPLL | 5.0000 | 32 | 8b/10b | QPLL | 5.0000 | 32 | 8b/10b | 269 | No |  | 0.000 | 0.000 | 0.000 | 0.000 |  | 3 | 0 | 10000 | 10000 | 2500 | 2500 | 125 | 125 | 0 | 5.575 | 0 | 7.579332025 | 53.875 | 43.53733333 | 0 | 16.46694215 | 25.6 | 1.55 | 10 | 10 | 0
 |  |  |  | Transceiver | Off | Low Power | 4 | QPLL | 5.0000 | 32 | 8b/10b | QPLL | 5.0000 | 32 | 8b/10b | 269 | No |  | 0.000 | 0.000 | 0.000 | 0.000 |  | 3 | 0 | 10000 | 10000 | 2500 | 2500 | 125 | 125 | 0 | 5.575 | 0 | 7.579332025 | 53.875 | 43.53733333 | 0 | 16.46694215 | 25.6 | 1.55 | 10 | 10 | 0
 |  |  |  | Transceiver | Off | Low Power | 4 | QPLL | 5.0000 | 32 | 8b/10b | QPLL | 5.0000 | 32 | 8b/10b | 269 | No |  | 0.000 | 0.000 | 0.000 | 0.000 |  | 3 | 0 | 10000 | 10000 | 2500 | 2500 | 125 | 125 | 0 | 5.575 | 0 | 7.579332025 | 53.875 | 43.53733333 | 0 | 16.46694215 | 25.6 | 1.55 | 10 | 10 | 0
 |  |  |  | Transceiver | Off | Low Power | 4 | QPLL | 5.0000 | 32 | 8b/10b | QPLL | 5.0000 | 32 | 8b/10b | 269 | No |  | 0.000 | 0.000 | 0.000 | 0.000 |  | 3 | 0 | 10000 | 10000 | 2500 | 2500 | 125 | 125 | 0 | 5.575 | 0 | 7.579332025 | 53.875 | 43.53733333 | 0 | 16.46694215 | 25.6 | 1.55 | 10 | 10 | 0
 |  |  |  | Transceiver | Off | Low Power | 4 | QPLL | 5.0000 | 32 | 8b/10b | QPLL | 5.0000 | 32 | 8b/10b | 269 | No |  | 0.000 | 0.000 | 0.000 | 0.000 |  | 3 | 0 | 10000 | 10000 | 2500 | 2500 | 125 | 125 | 0 | 5.575 | 0 | 7.579332025 | 53.875 | 43.53733333 | 0 | 16.46694215 | 25.6 | 1.55 | 10 | 10 | 0
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

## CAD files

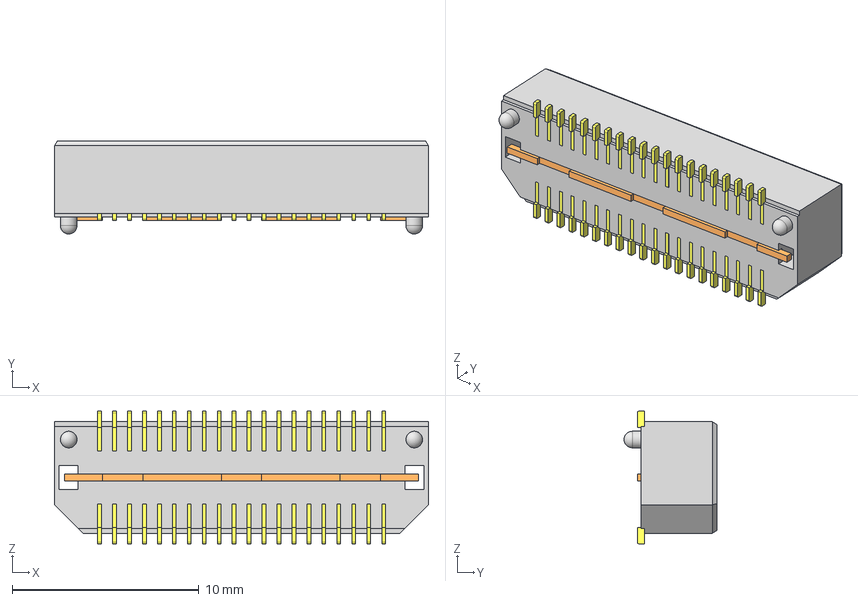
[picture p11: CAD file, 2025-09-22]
syzygy-template/pcb-templates-main/KiCAD/3D/QTE-020-01-F-D-A.stp
20.0 x 4.98 x 7.11 mm
_QTE-020-01-F-D-At
_PT-1S39-01(020-01-D)
_QTE-T-1G1-01_imp

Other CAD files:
syzygy-template/pcb-templates-main/KiCAD/3D/QTH-020-01-F-D-DP-A.stp

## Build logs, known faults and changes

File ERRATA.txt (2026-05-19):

Issue: No console output on RS-232 port
Workaround: The TRS3221ECPW RS-232 transceiver won't transmit until FORCEOFF and FORCEON pins are HIGH. 
Short pins 15(VCC) and 16(*FORCEOFF), place resistors R145, R146.

Issue: I2C EEPROM U8 SCA & SCL lines are swapped.
Workaround: either rework or unsolder it

Issue: L4 shall be replaced with an inductor of a greater saturation current, at least 5A.
Workaround: Replacements - FTC303015D1R5MBCA(C53281631), SMTC303020-1R5MT (C22463870), SPM3020-1R5MA (C7471176), FTC303020D1R5MBCA (C7423317), FTC303018D1R5MBCA (C18724425), YSMC0320H-1R5MB (C41405950). Replace the R51 resistor with a 22K to enable 6.44A limit.

Issue: The secondary power supply won't start in automatic PWM/PSM mode.
Workaround: Remove R44 and place R45 to force the PWM mode.

Issue: I forgot to put a transistor switch to light up the LED's on +1V35 and +1V0_SYS power buses.
Workaround: Remove D15, R17, D13, R64. +3V3_SYS led is enough because it will be lit last.

Issue: The master TCXO (Y3 - ECS-TXO-32CSMV-270-AN-TR) outputs a 0.8V sine which is not enough to drive the PLL chip.
Workaround: Temporary workaround is rework. The replacements are ASTX-H11-25.000MHZ-T and FT3MHUPM25.0-T1. Future board revision will include one of them.
Workaround++: Replace R127 with a 1uF capacitor and watch the clipped sine appear on the output pin. AC termination magic!

Issue: R184 connected to PS_MIO1_500 of the SOC is 330Ohm. It looks like a copy-paste error.
Workaround: replace with a 10k resistor

Issue: SW5 PS Reset button shall be connected to PS_SRST_EXT_1.8 instead of PS_RST_B
Workaround: should be fixed in a future release

Issue: PHY_LED0 must be tied down to ground to enable the internal 1V0 in PS ETH PHY.
Workaround: Remove DNP flag from R272, mark R271 as DNP. Unsolder R271, solder in R272.

Issue: PHY MDI tracks shall be on an outter layer to achieve a better SI
Workaround: I'll be fixing that in a new board re-spin

Issue: R200, R201 DDR termination resistors must be 100Ohm because I'm using 50/100Ohm tracks for DDR
Workaround: place a 100Ohm resistors

Issue: U22 is to close to the J20 PS JTAG connector
Workaround: U22 shall be moved a few millimeters away from the J20

Issue: SOC Bank_33 and Bank_34 SYZYGY Pod to Carrier clock is reversed.
Workaround: it has to be fixed in rev A.

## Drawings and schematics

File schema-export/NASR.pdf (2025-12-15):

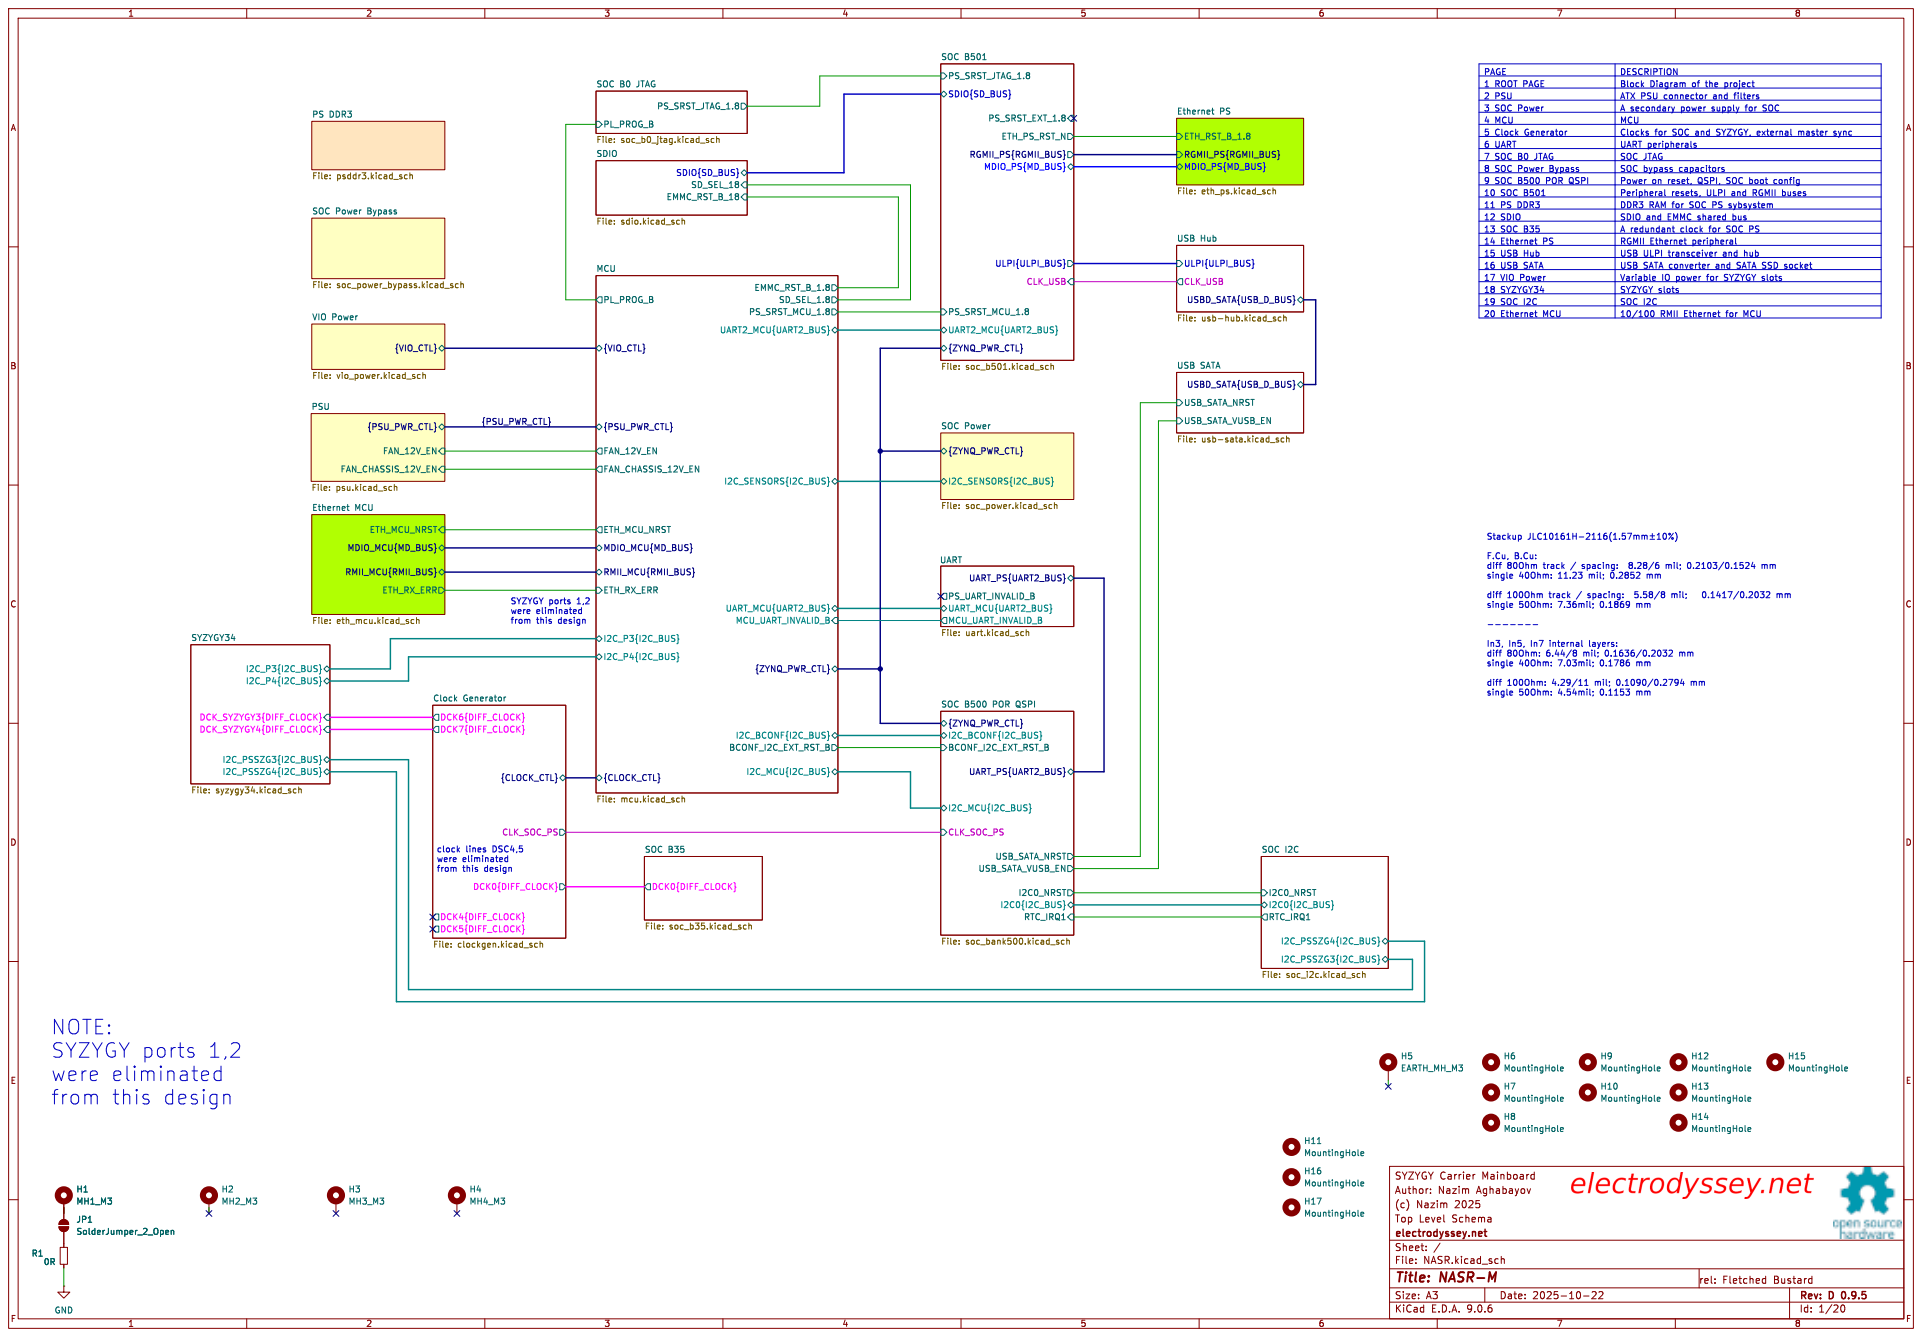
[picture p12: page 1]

File: usb-sata.kicad_sch PS DDR3 File: psddr3.kicad_sch SOC Power Bypass File: soc_power_bypass.kicad_sch

USBD_SATA{USB_D_BUS} USB Hub File: usb-hub.kicad_sch UART_MCU{UART2_BUS}

FAN_CHASSIS_12V_EN
File: psu.kicad_sch
Ethernet MCU
DCK0{DIFF_CLOCK} Clock Generator File: clockgen.kicad_sch

MDIO_MCU{MD_BUS}
SOC B500 POR QSPI File: soc_bank500.kicad_sch

SYZYGY ports 1,2 were eliminated

clock lines DSC4,5 were eliminated

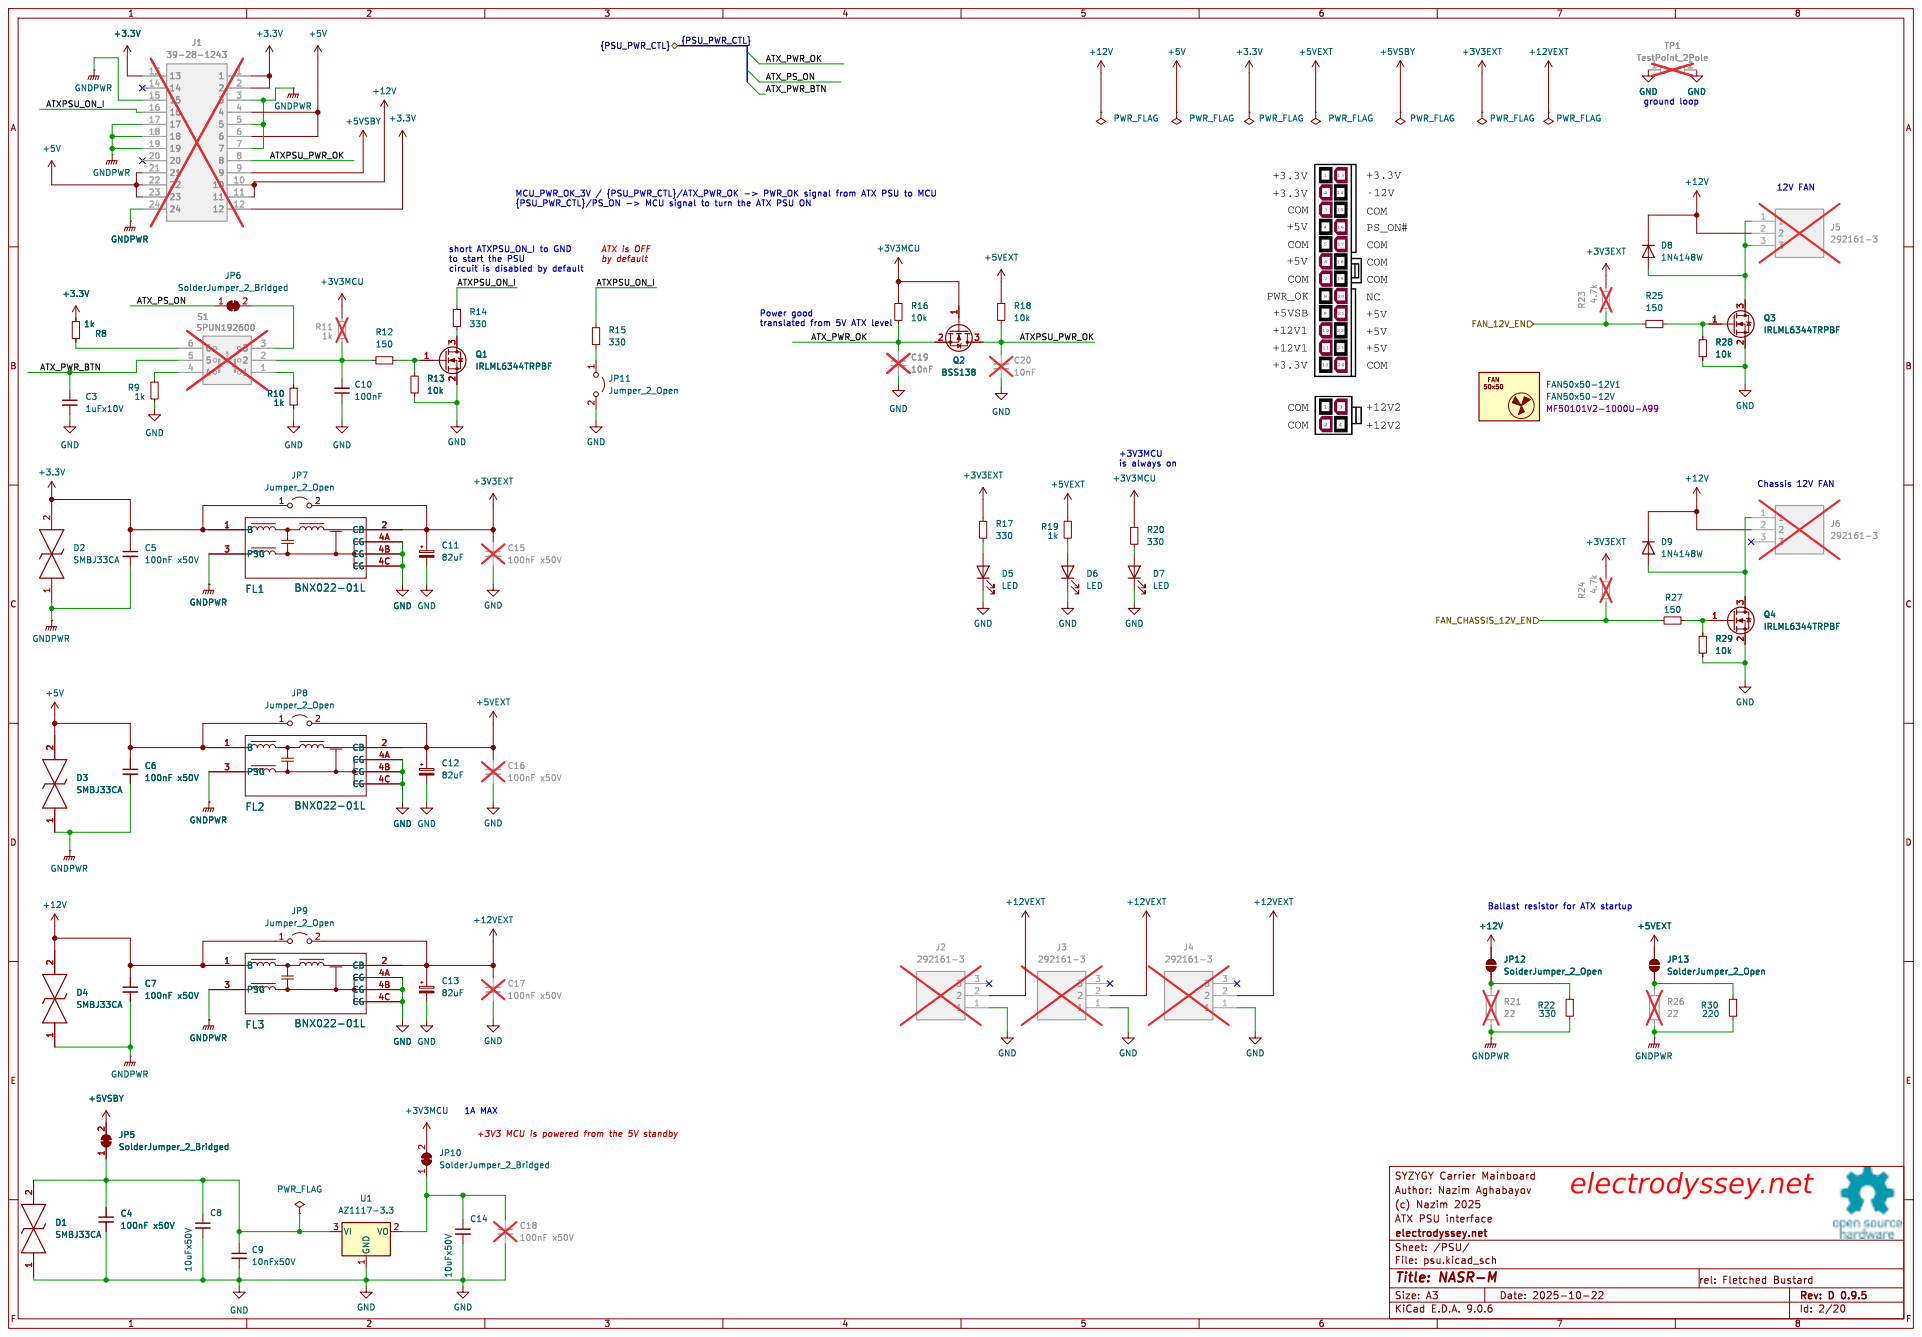
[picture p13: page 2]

short ATXPSU_ON_I to GND
to start the PSU
ATXPSU_ON_I

+3V3 MCU is powered from the 5V standby

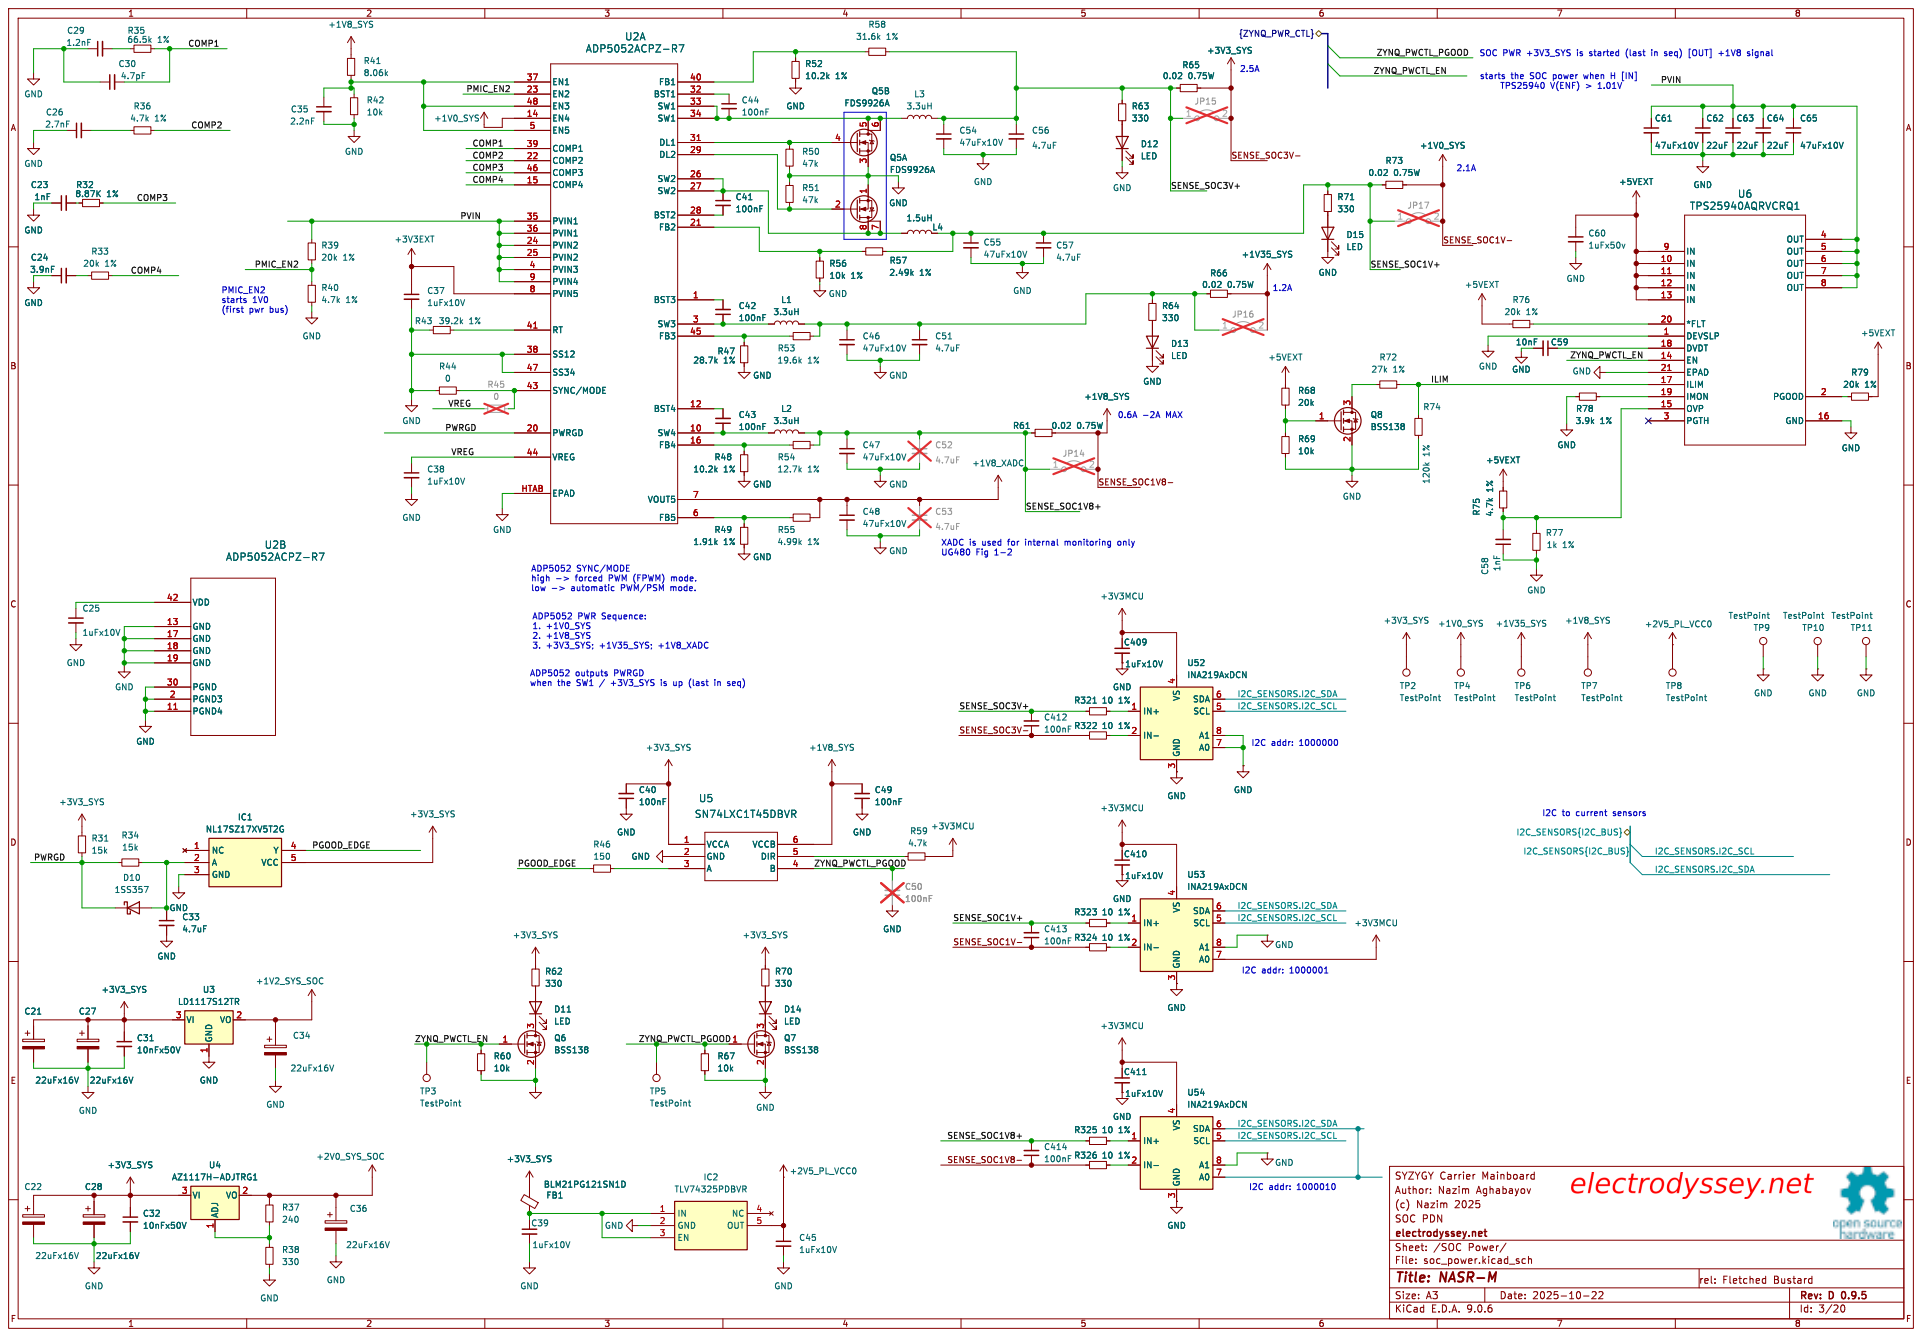
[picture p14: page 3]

SOC PWR +3V3_SYS is started (last in seq) [OUT] +1V8 signal

starts the SOC power when H [IN] TPS25940 V(ENF) > 1.01V

ADP5052 outputs PWRGD
when the SW1 / +3V3_SYS is up (last in seq)

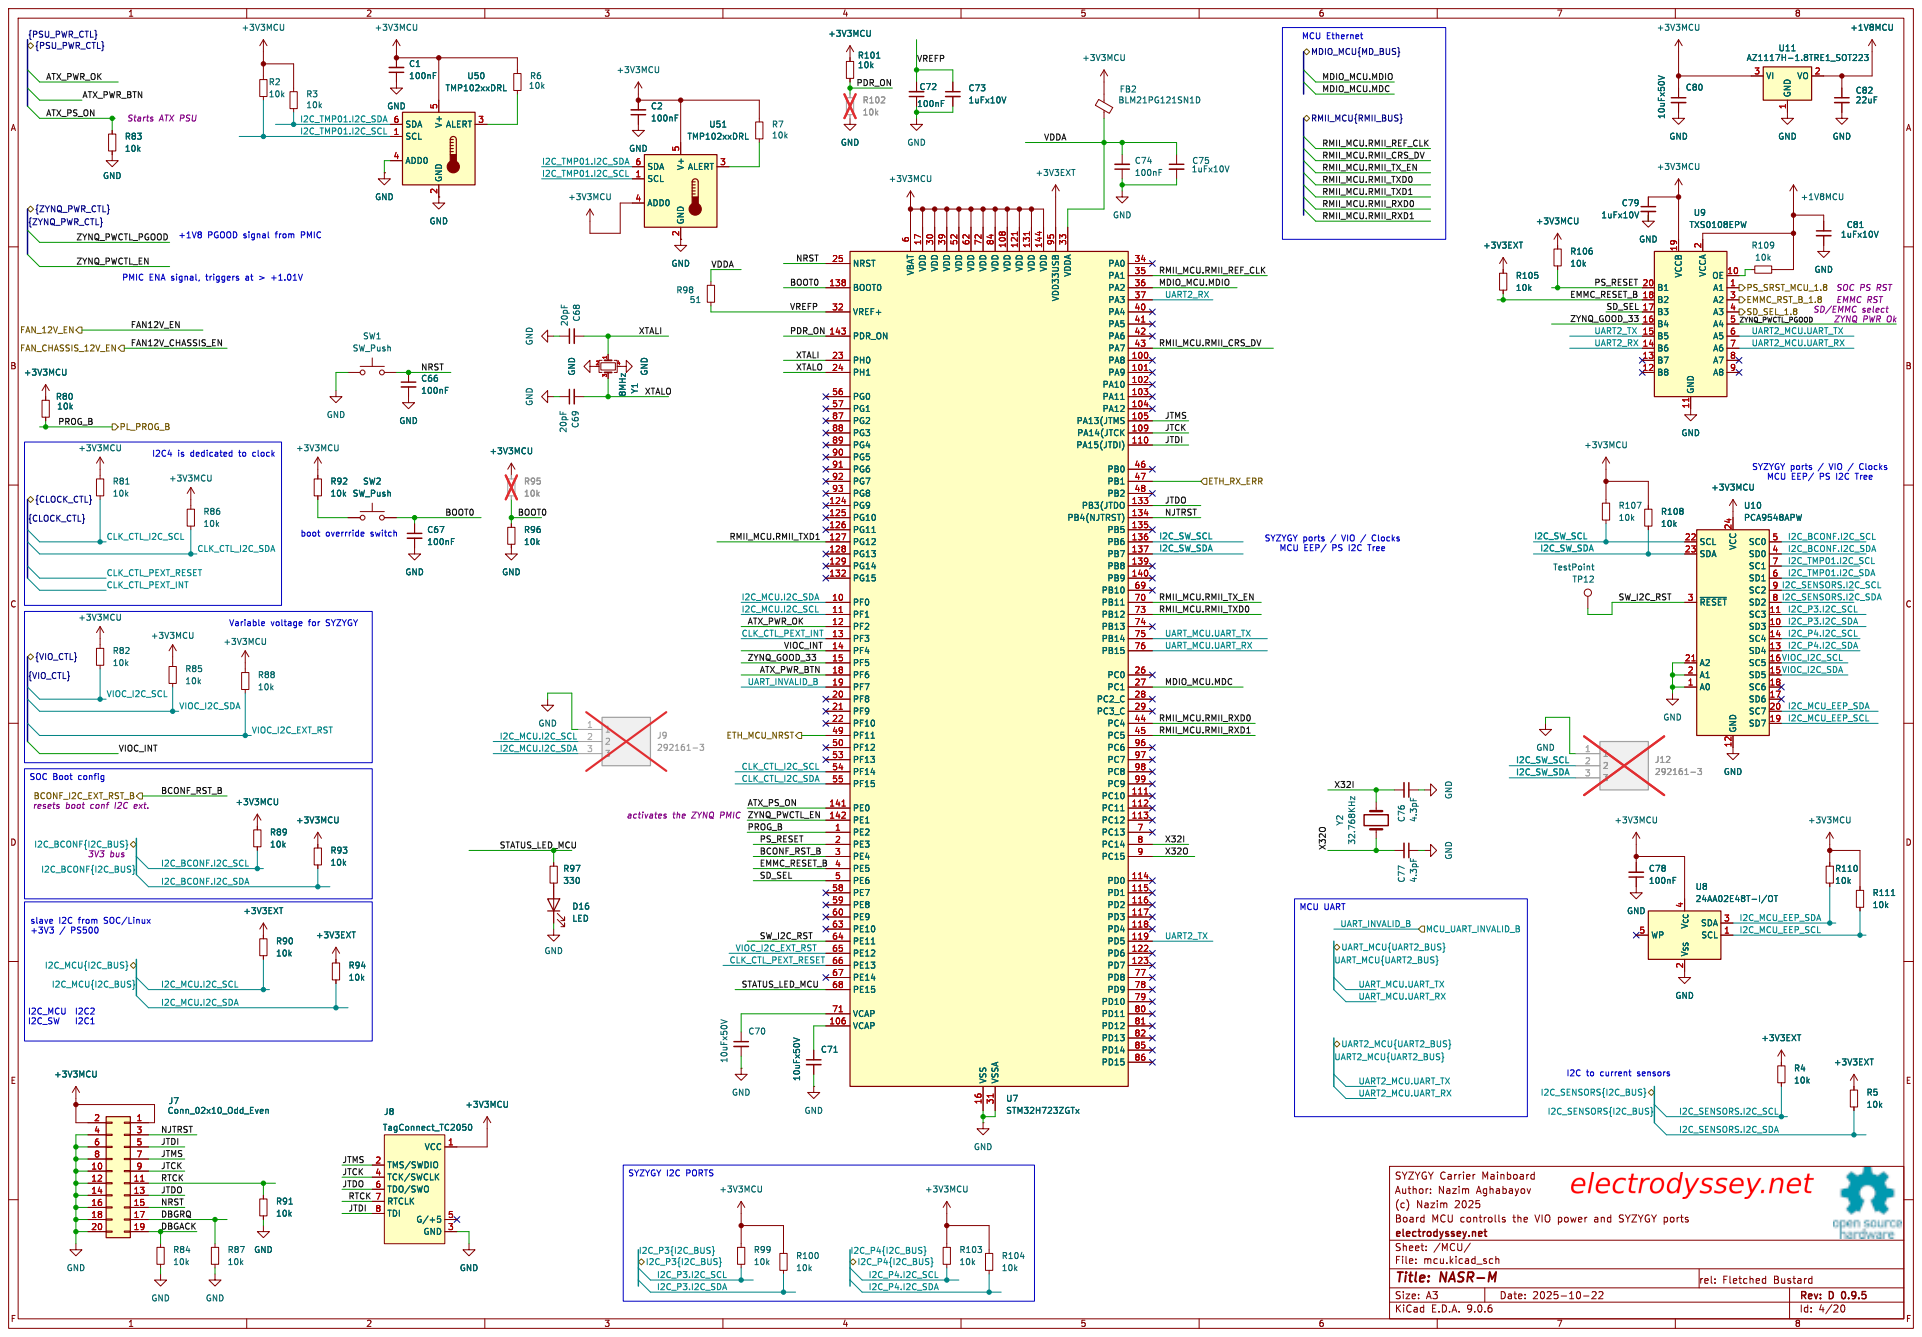
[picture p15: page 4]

+1V8 PGOOD signal from PMIC

6 VDD 17 VDD 30 VDD 39 VDD 52 VDD 62 VDD 72 VSS 16 VDD 84 VSSA 31 VDD 108 VDD 121 VDD 131 VDD 144 VDD33USB 95 VDDA 33 PA0 34 PA1 35 PA2 36 PA3 37 PA4 40 PA5 41 PA6 42 PA7 43 PA8 100 PA9 101 PA10 102 PA11 103 PA12 104 PA13(JTMS 105 PA14(JTCK 109 PA15(JTDI) 110 PB0 46 PB1 47 PB2 48 PB3(JTDO 133 PB4(NJTRST) 134 PB5 135 PB6 136 PB7 137 PB8 139 PB9 140 PB10 69 PB11 70 PB12 73 PB13 74 PB14 75 PB15 76 PC0 26 PC1 27 PC2_C 28 PC3_C 29 PC4 44 PC5 45 PC6 96 PC7 97 PC8 98 PC9 99 PC10 111 PC11 112 PC12 113 PC13 7 PC14 8 PC15 9 PD0 114 PD1 115 PD2 116 PD3 117 PD4 118 PD5 119 PD6 122 PD7 123 PD8 77 PD9 78 PD10 79 PD11 80 PD12 81 PD13 82 PD14 85 PD15 86 U7STM32H723ZGTx GND C76 4.3pF

6 VDD 17 VDD 30 VDD 39 VDD 52 VDD 62 VDD 72 VSS 16 VDD 84 VSSA 31 VDD 108 VDD 121 VDD 131 VDD 144 VDD33USB 95 VDDA 33 PA0 34 PA1 35 PA2 36 PA3 37 PA4 40 PA5 41 PA6 42 PA7 43 PA8 100 PA9 101 PA10 102 PA11 103 PA12 104 PA13(JTMS 105 PA14(JTCK 109 PA15(JTDI) 110 PB0 46 PB1 47 PB2 48 PB3(JTDO 133 PB4(NJTRST) 134 PB5 135 PB6 136 PB7 137 PB8 139 PB9 140 PB10 69 PB11 70 PB12 73 PB13 74 PB14 75 PB15 76 PC0 26 PC1 27 PC2_C 28 PC3_C 29 PC4 44 PC5 45 PC6 96 PC7 97 PC8 98 PC9 99 PC10 111 PC11 112 PC12 113 PC13 7 PC14 8 PC15 9 PD0 114 PD1 115 PD2 116 PD3 117 PD4 118 PD5 119 PD6 122 PD7 123 PD8 77 PD9 78 PD10 79 PD11 80 PD12 81 PD13 82 PD14 85 PD15 86 C78

SYZYGY ports / VIO / Clocks MCU EEP/ PS I2C Tree
22 SDA
SCL
23 ~{RESET} 3 A2

Variable voltage for SYZYGY

BCONF_I2C_EXT_RST_B
resets boot conf I2C ext.

slave I2C from SOC/Linux +3V3 / PS500

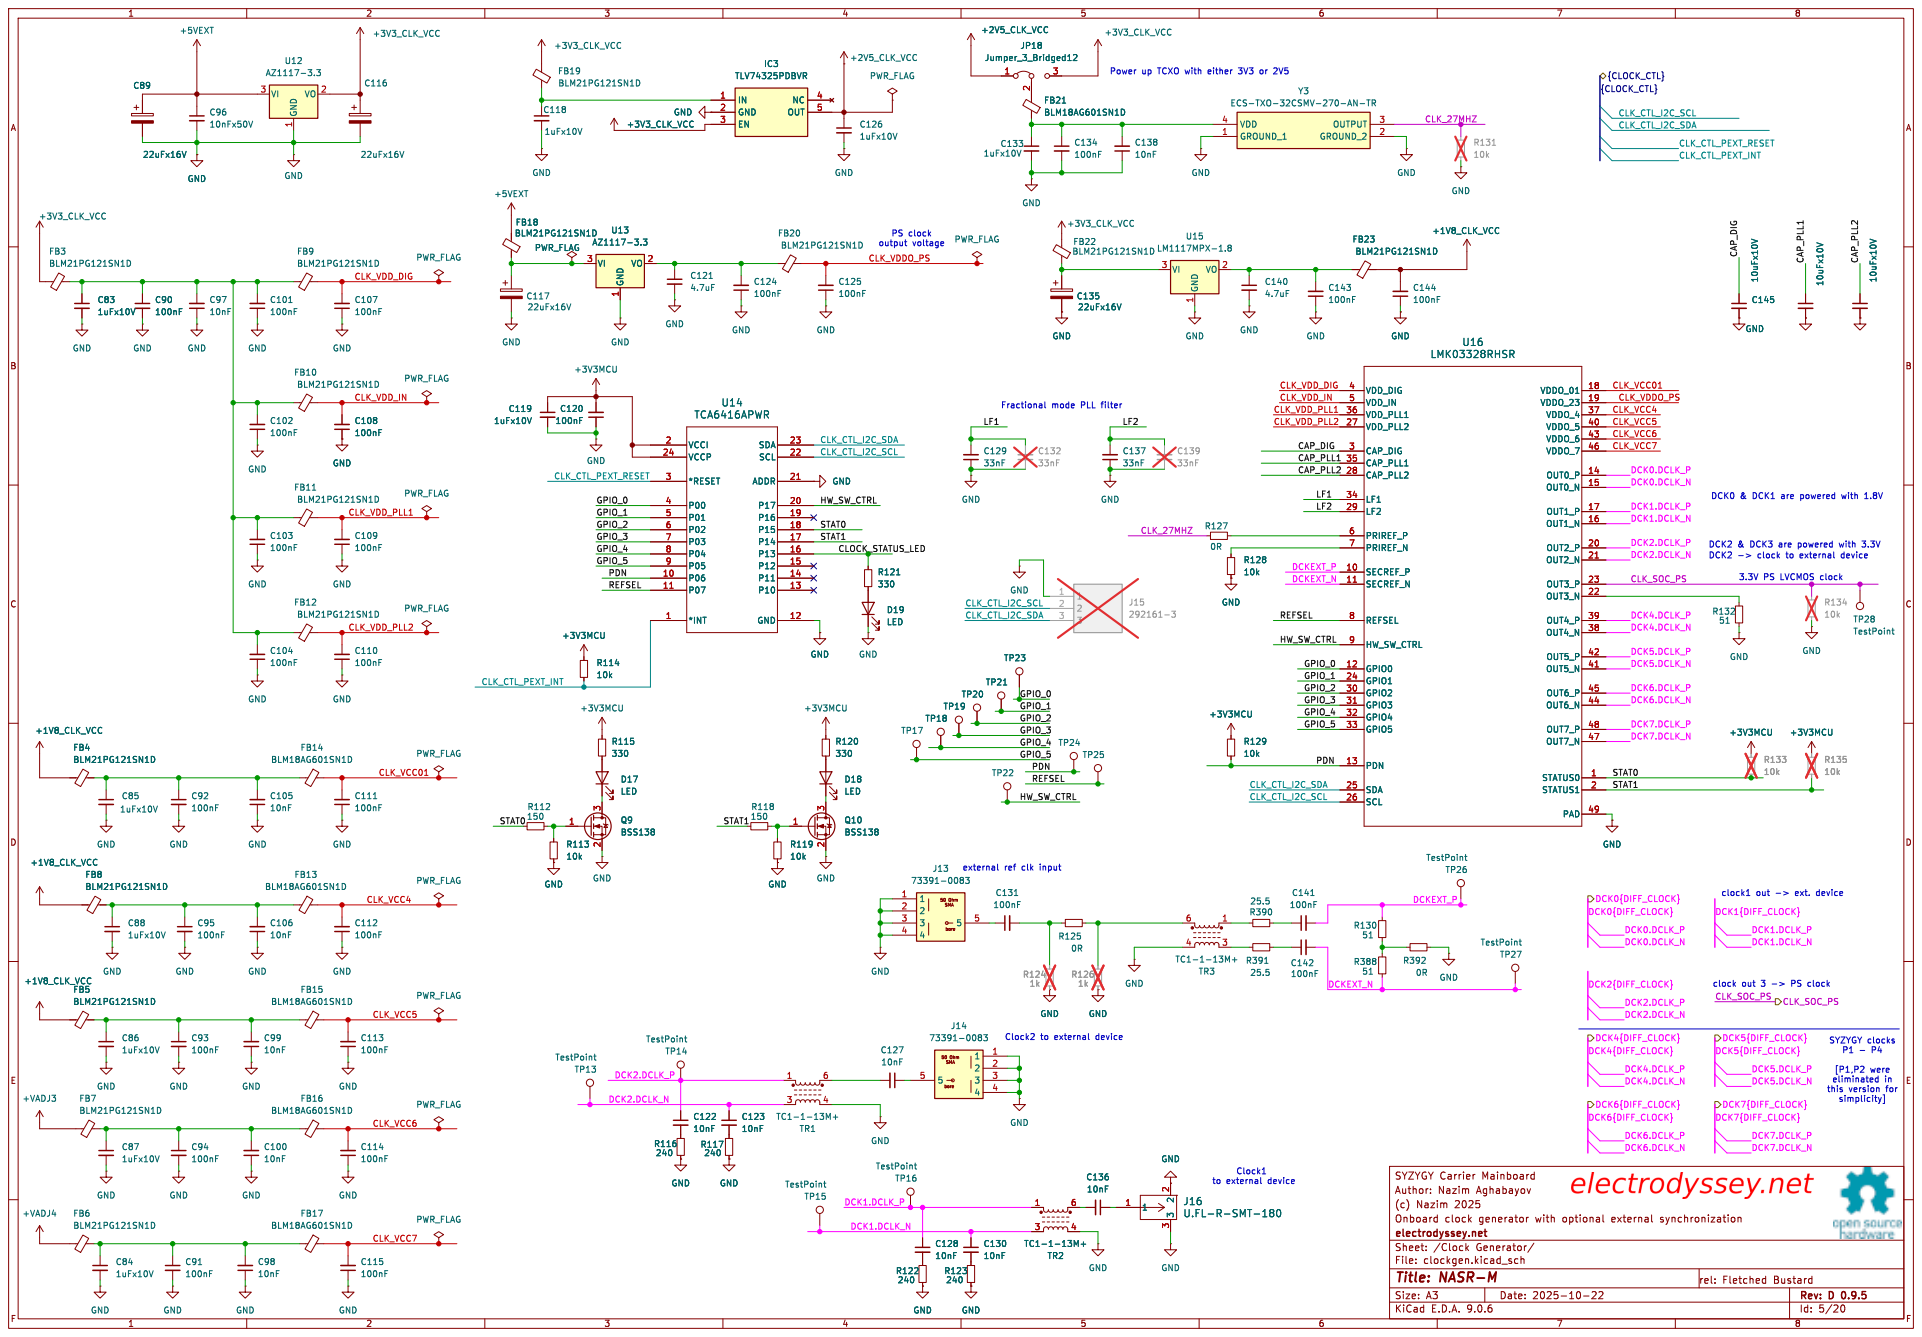
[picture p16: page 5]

Power up TCXO with either 3V3 or 2V5

CAP_PLL2
3.3V PS LVCMOS clock SYZYGY clocks P1 - P4

this version for simplicity] Clock1

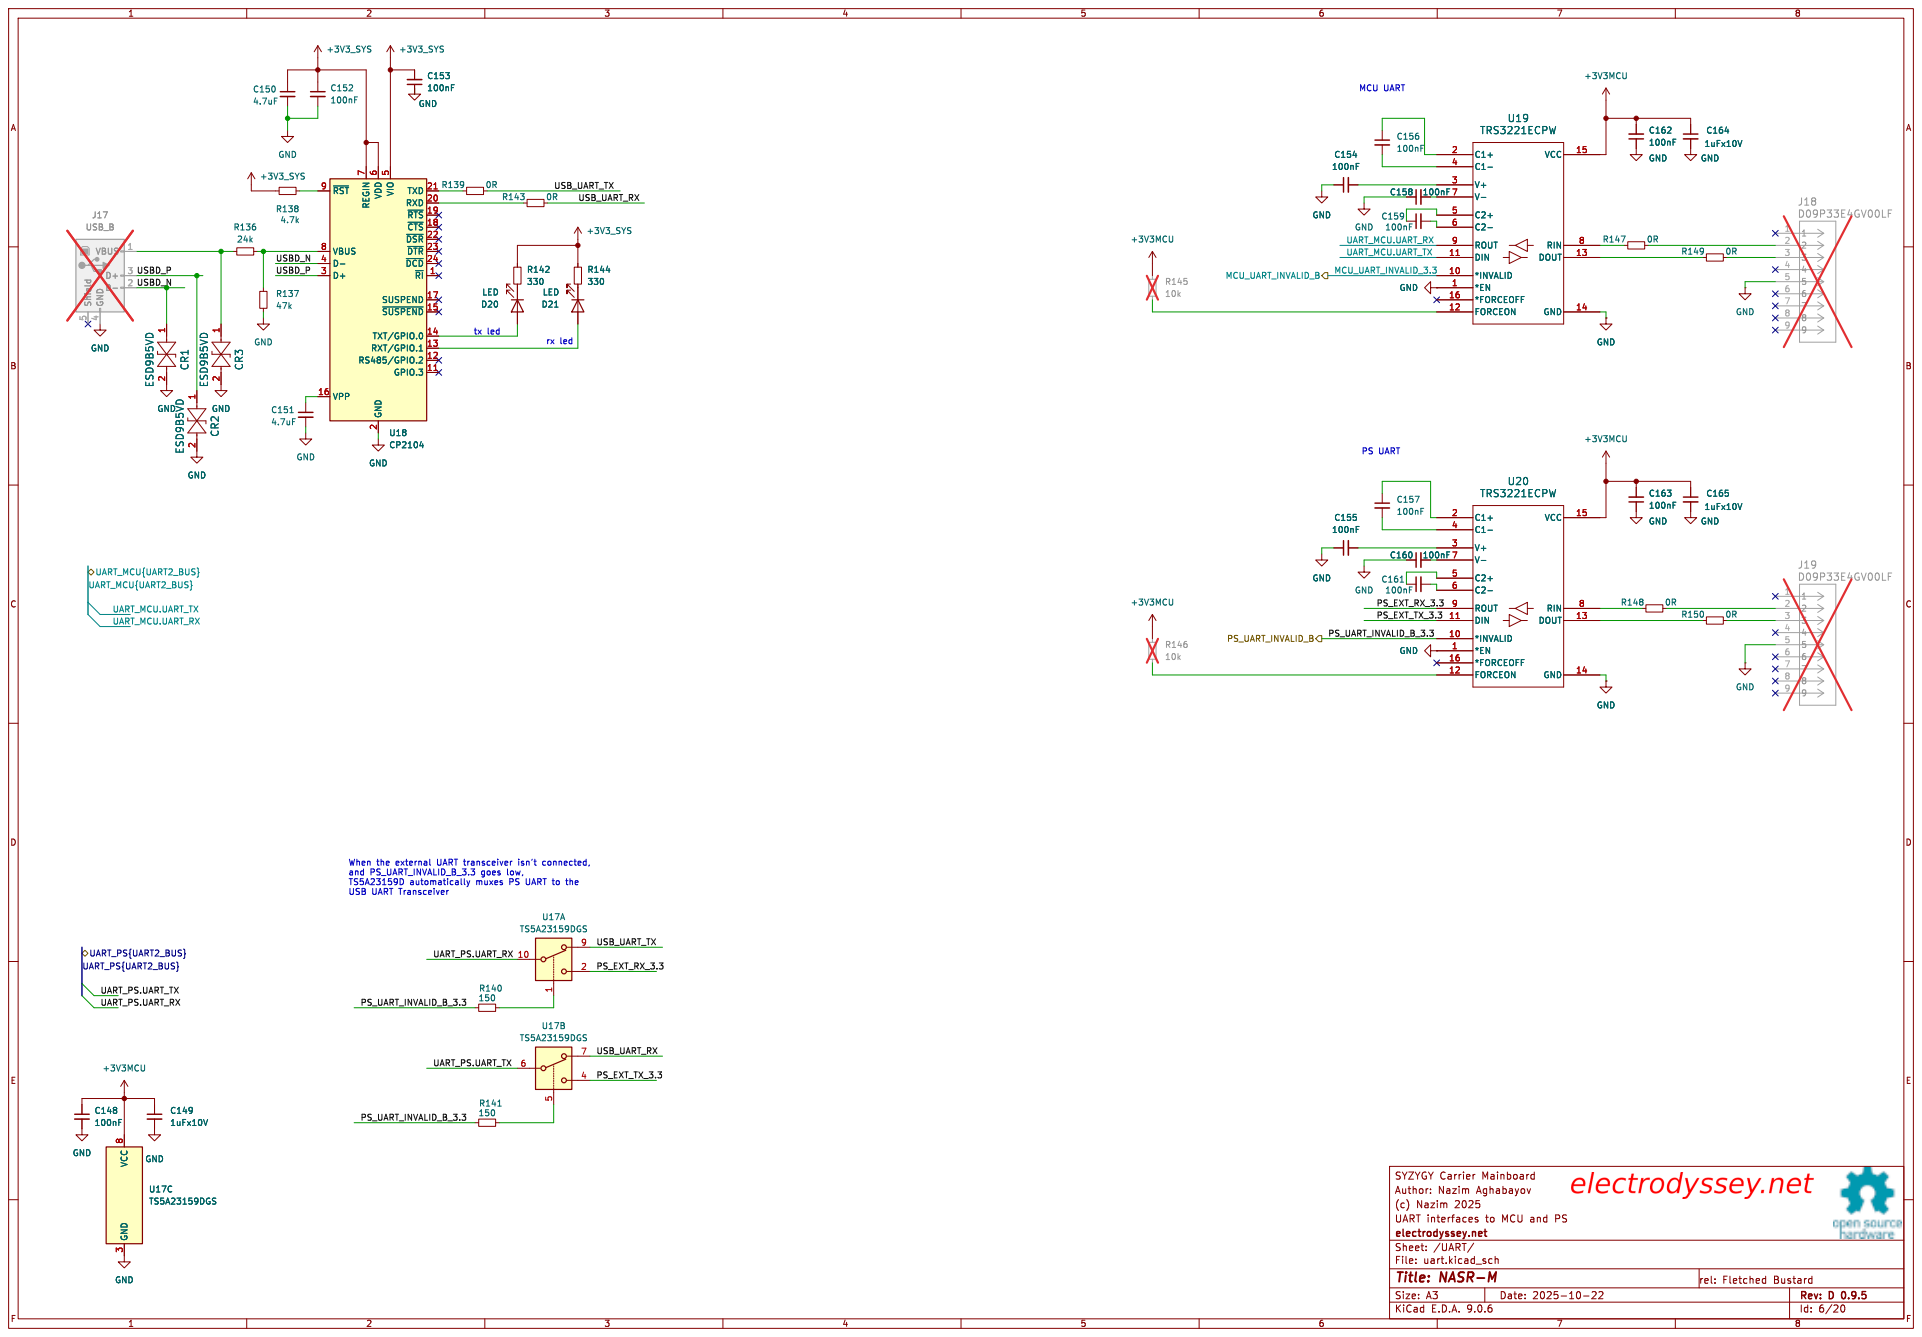
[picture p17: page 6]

MCU UART PS UART

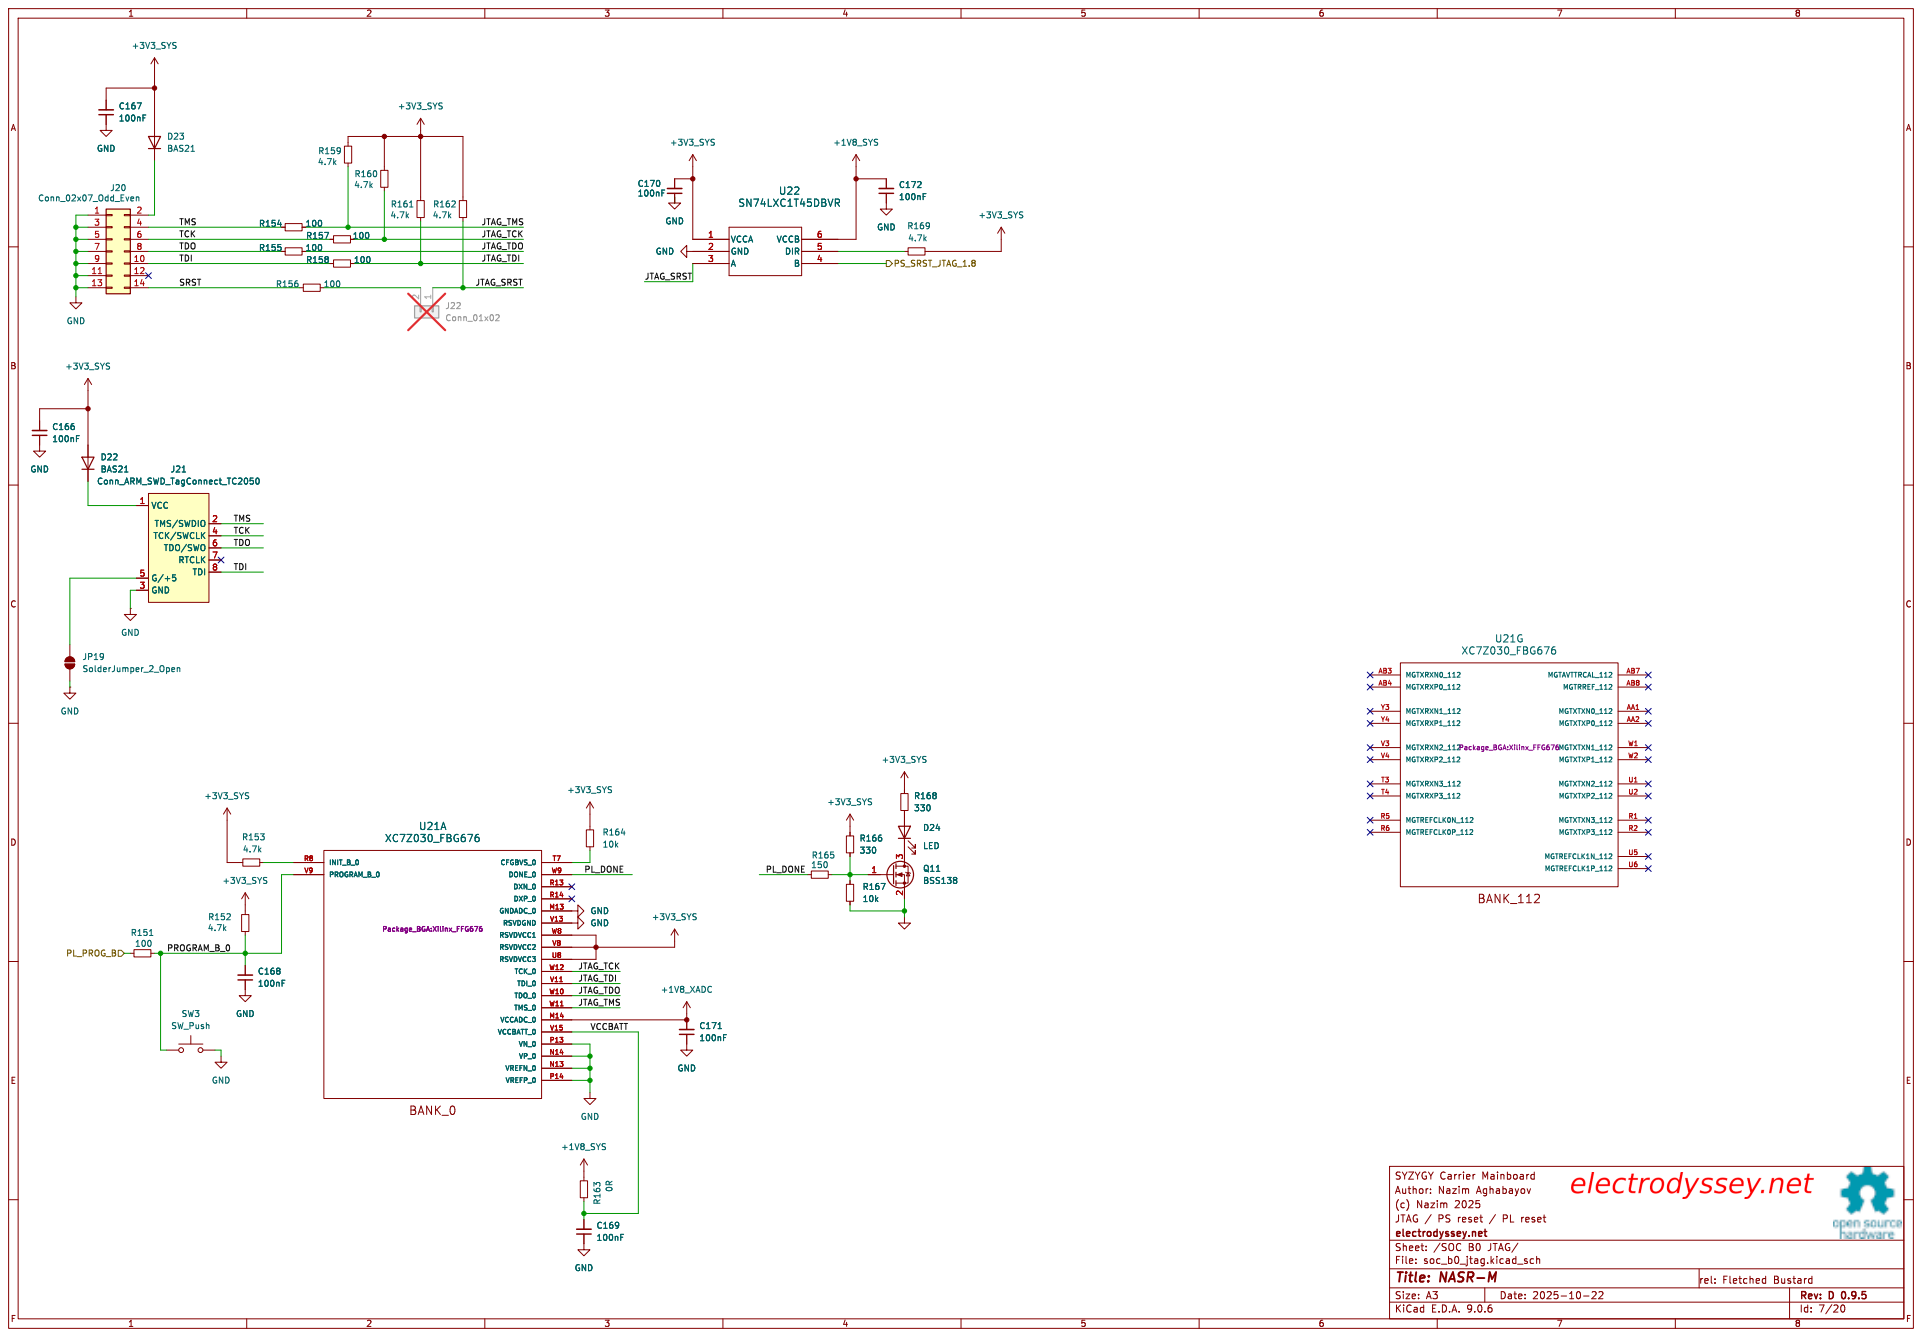
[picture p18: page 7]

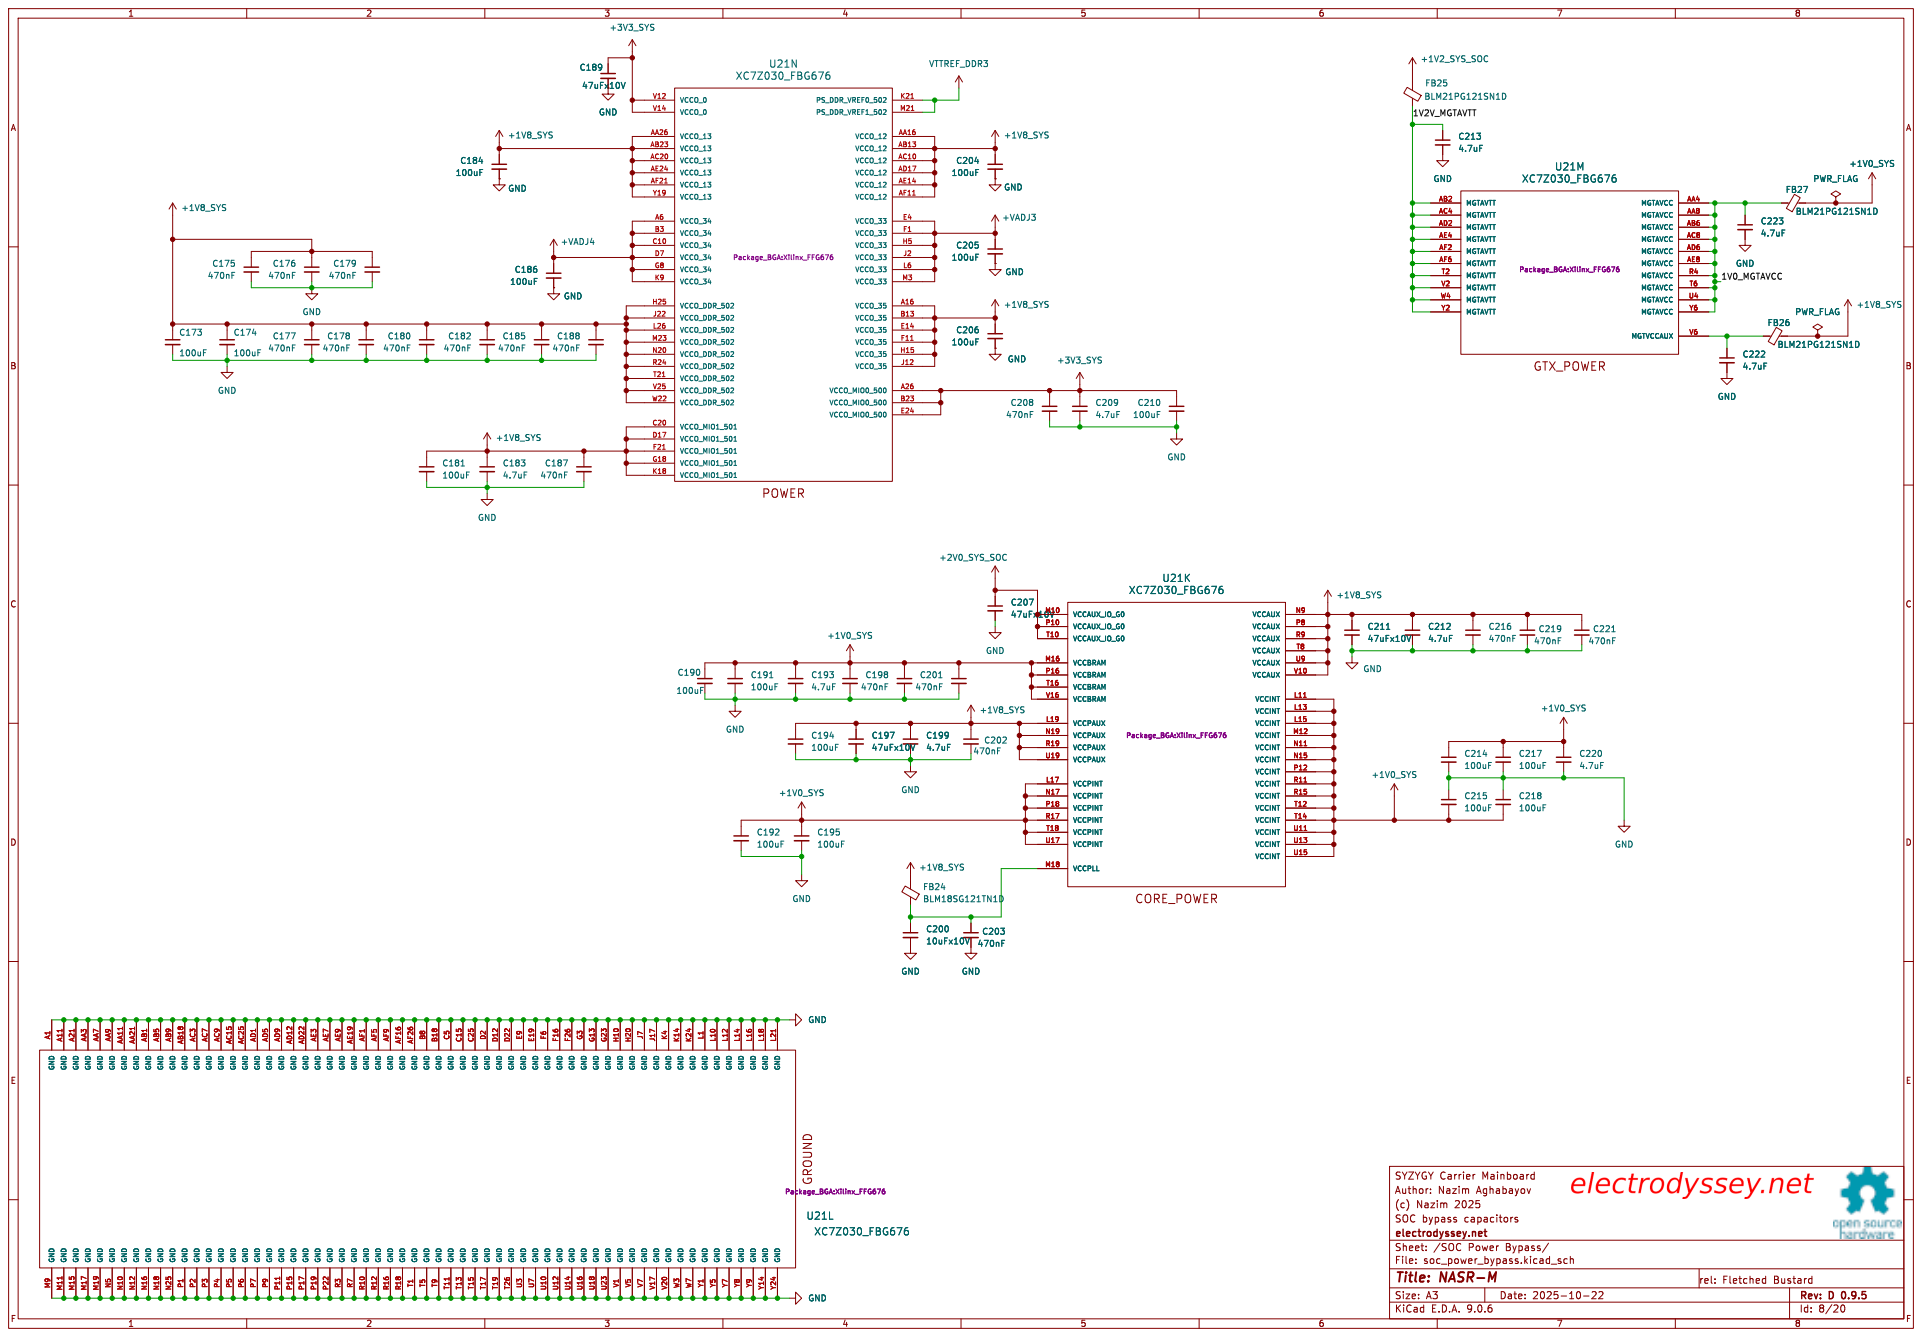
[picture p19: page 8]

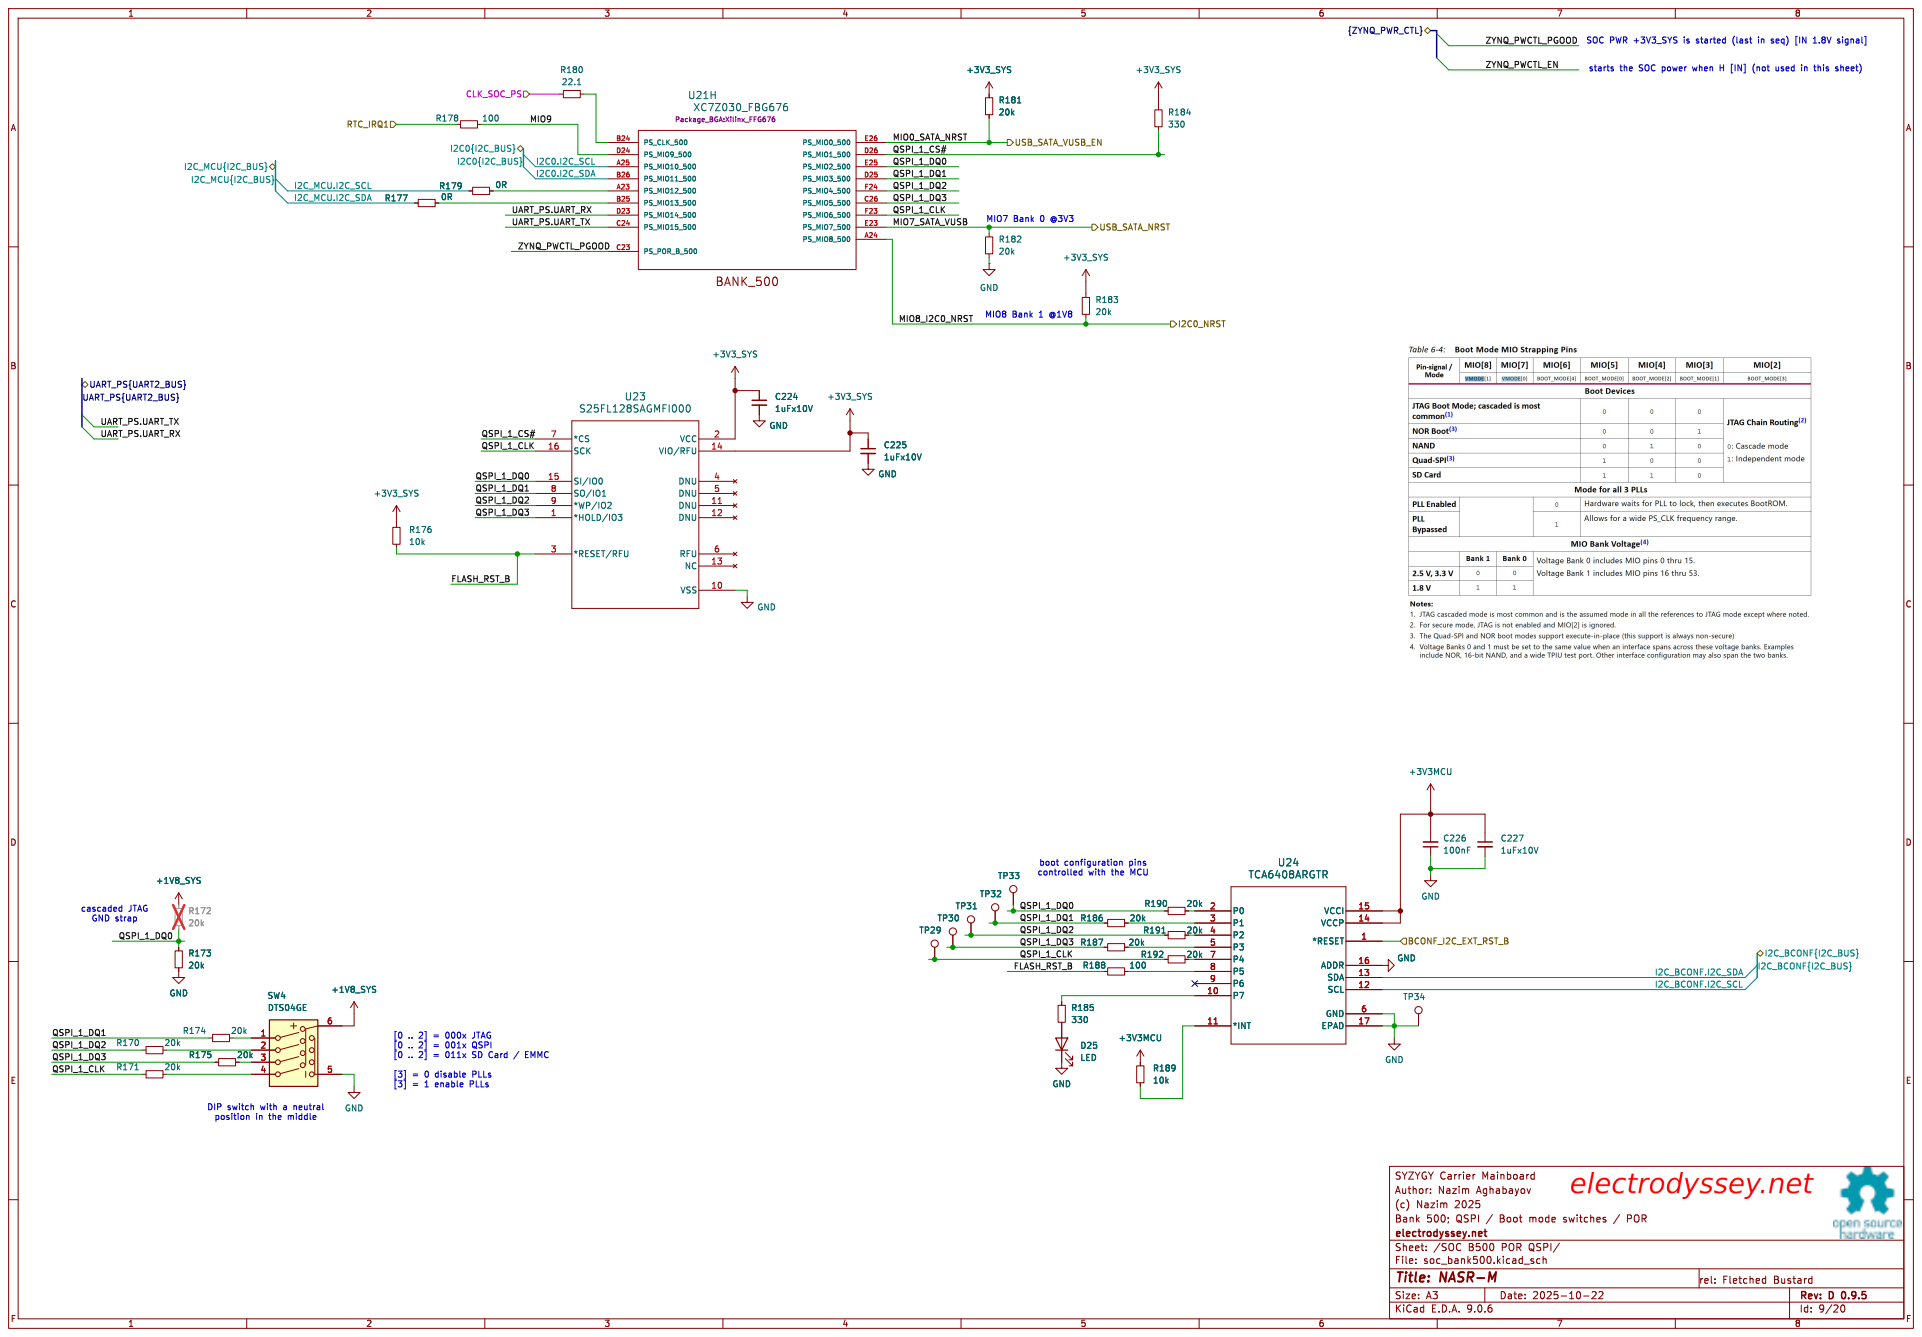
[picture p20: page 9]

{ZYNQ_PWR_CTL} USB_SATA_VUSB_EN
SOC PWR +3V3_SYS is started (last in seq) [IN 1.8V signal] R181

starts the SOC power when H [IN] (not used in this sheet)

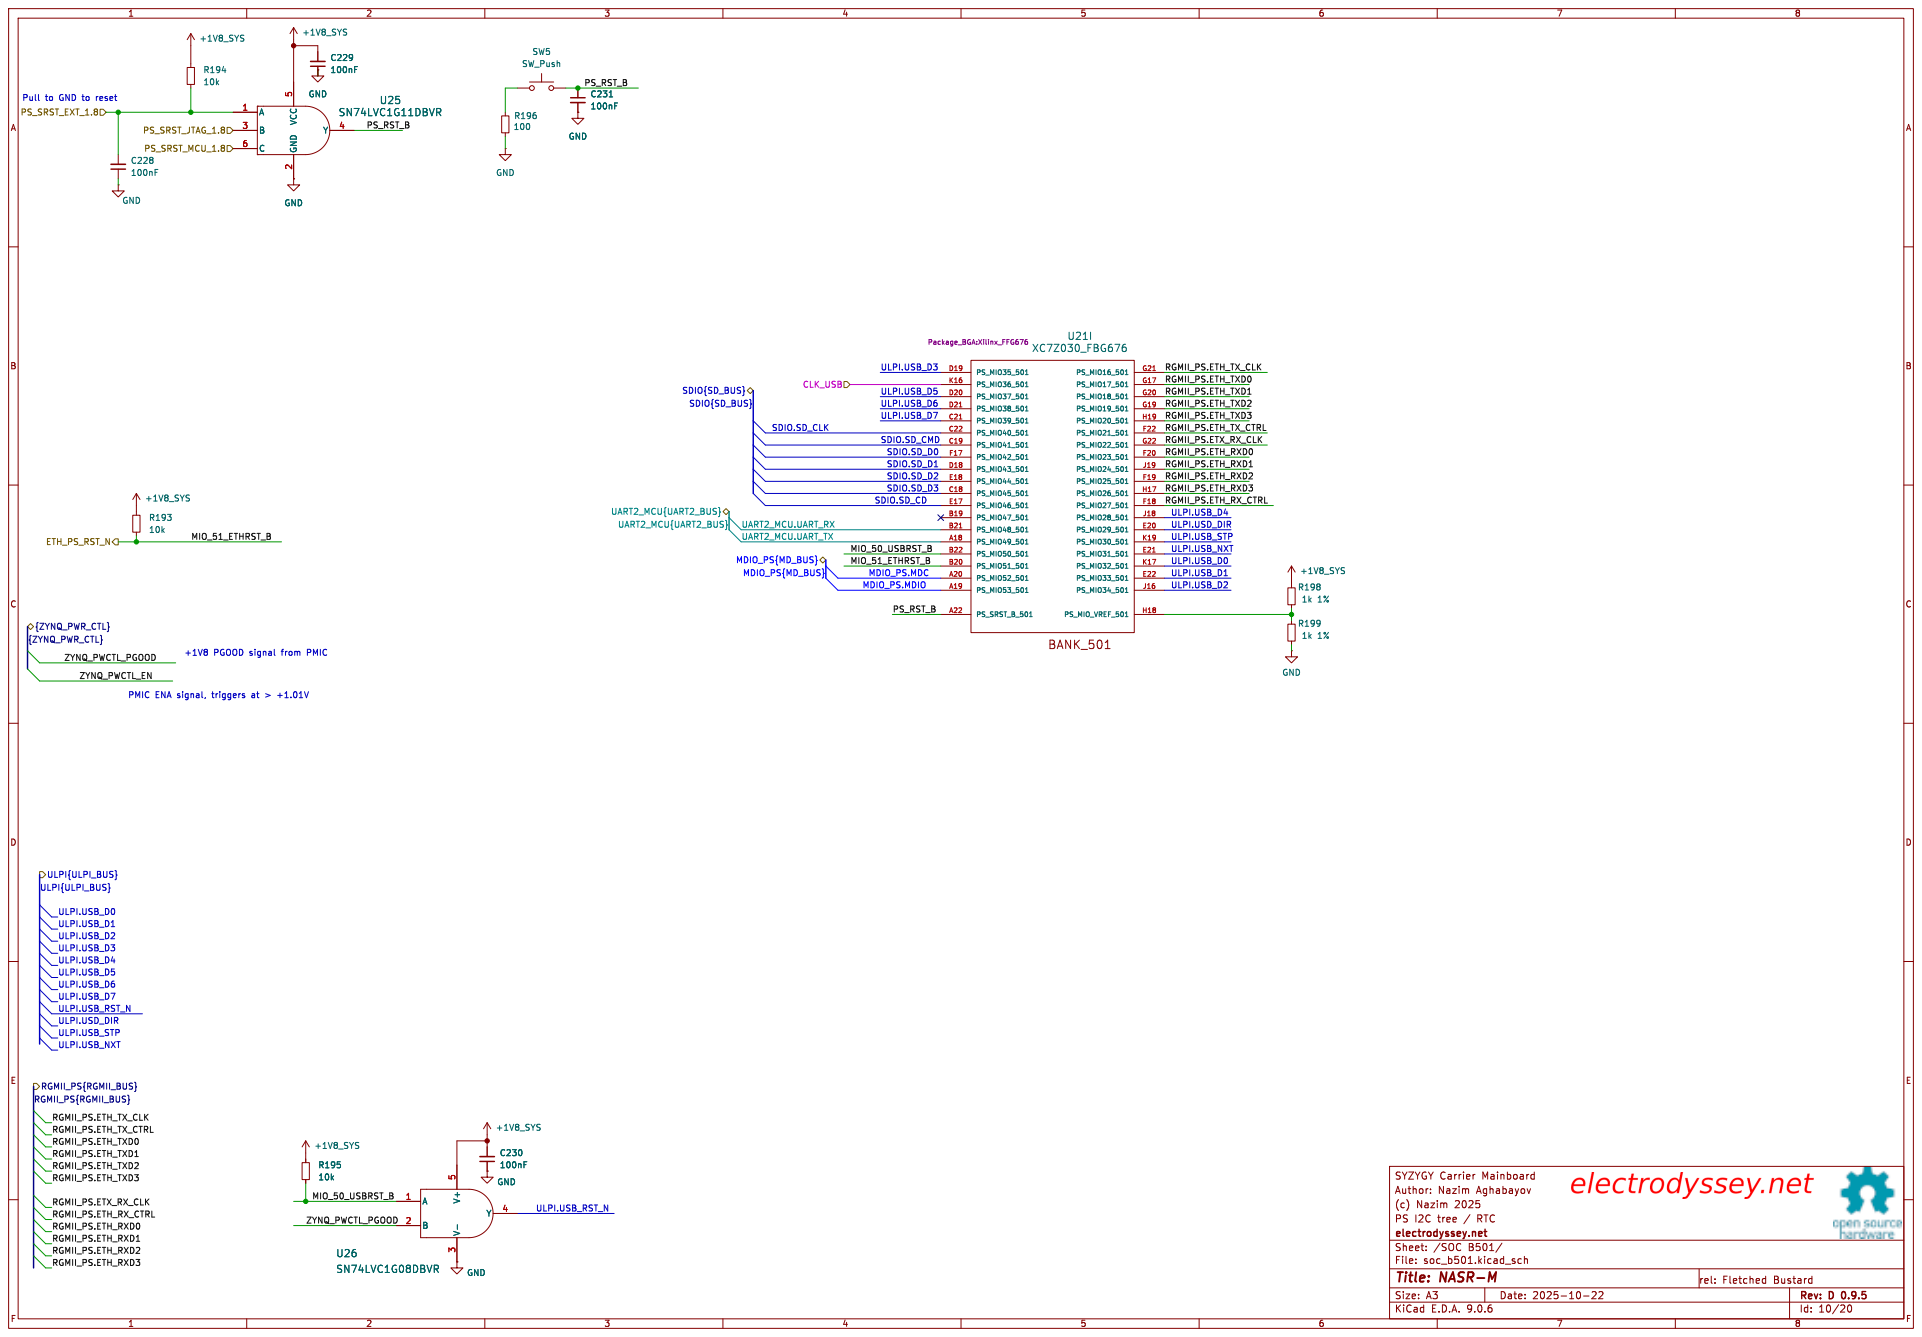
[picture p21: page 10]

Pull to GND to reset

ULPI.USB_STP ULPI.USB_NXT RGMII_PS.ETH_TXD2 RGMII_PS.ETH_TXD3 ULPI.USB_D4 RGMII_PS.ETH_TX_CTRL ULPI.USD_DIR

+1V8 PGOOD signal from PMIC

ULPI.USB_NXT ULPI{ULPI_BUS} ULPI.USB_D1 ULPI.USB_D2

ULPI.USB_D6 ULPI.USB_D5 ULPI.USB_D3 ULPI.USB_D4

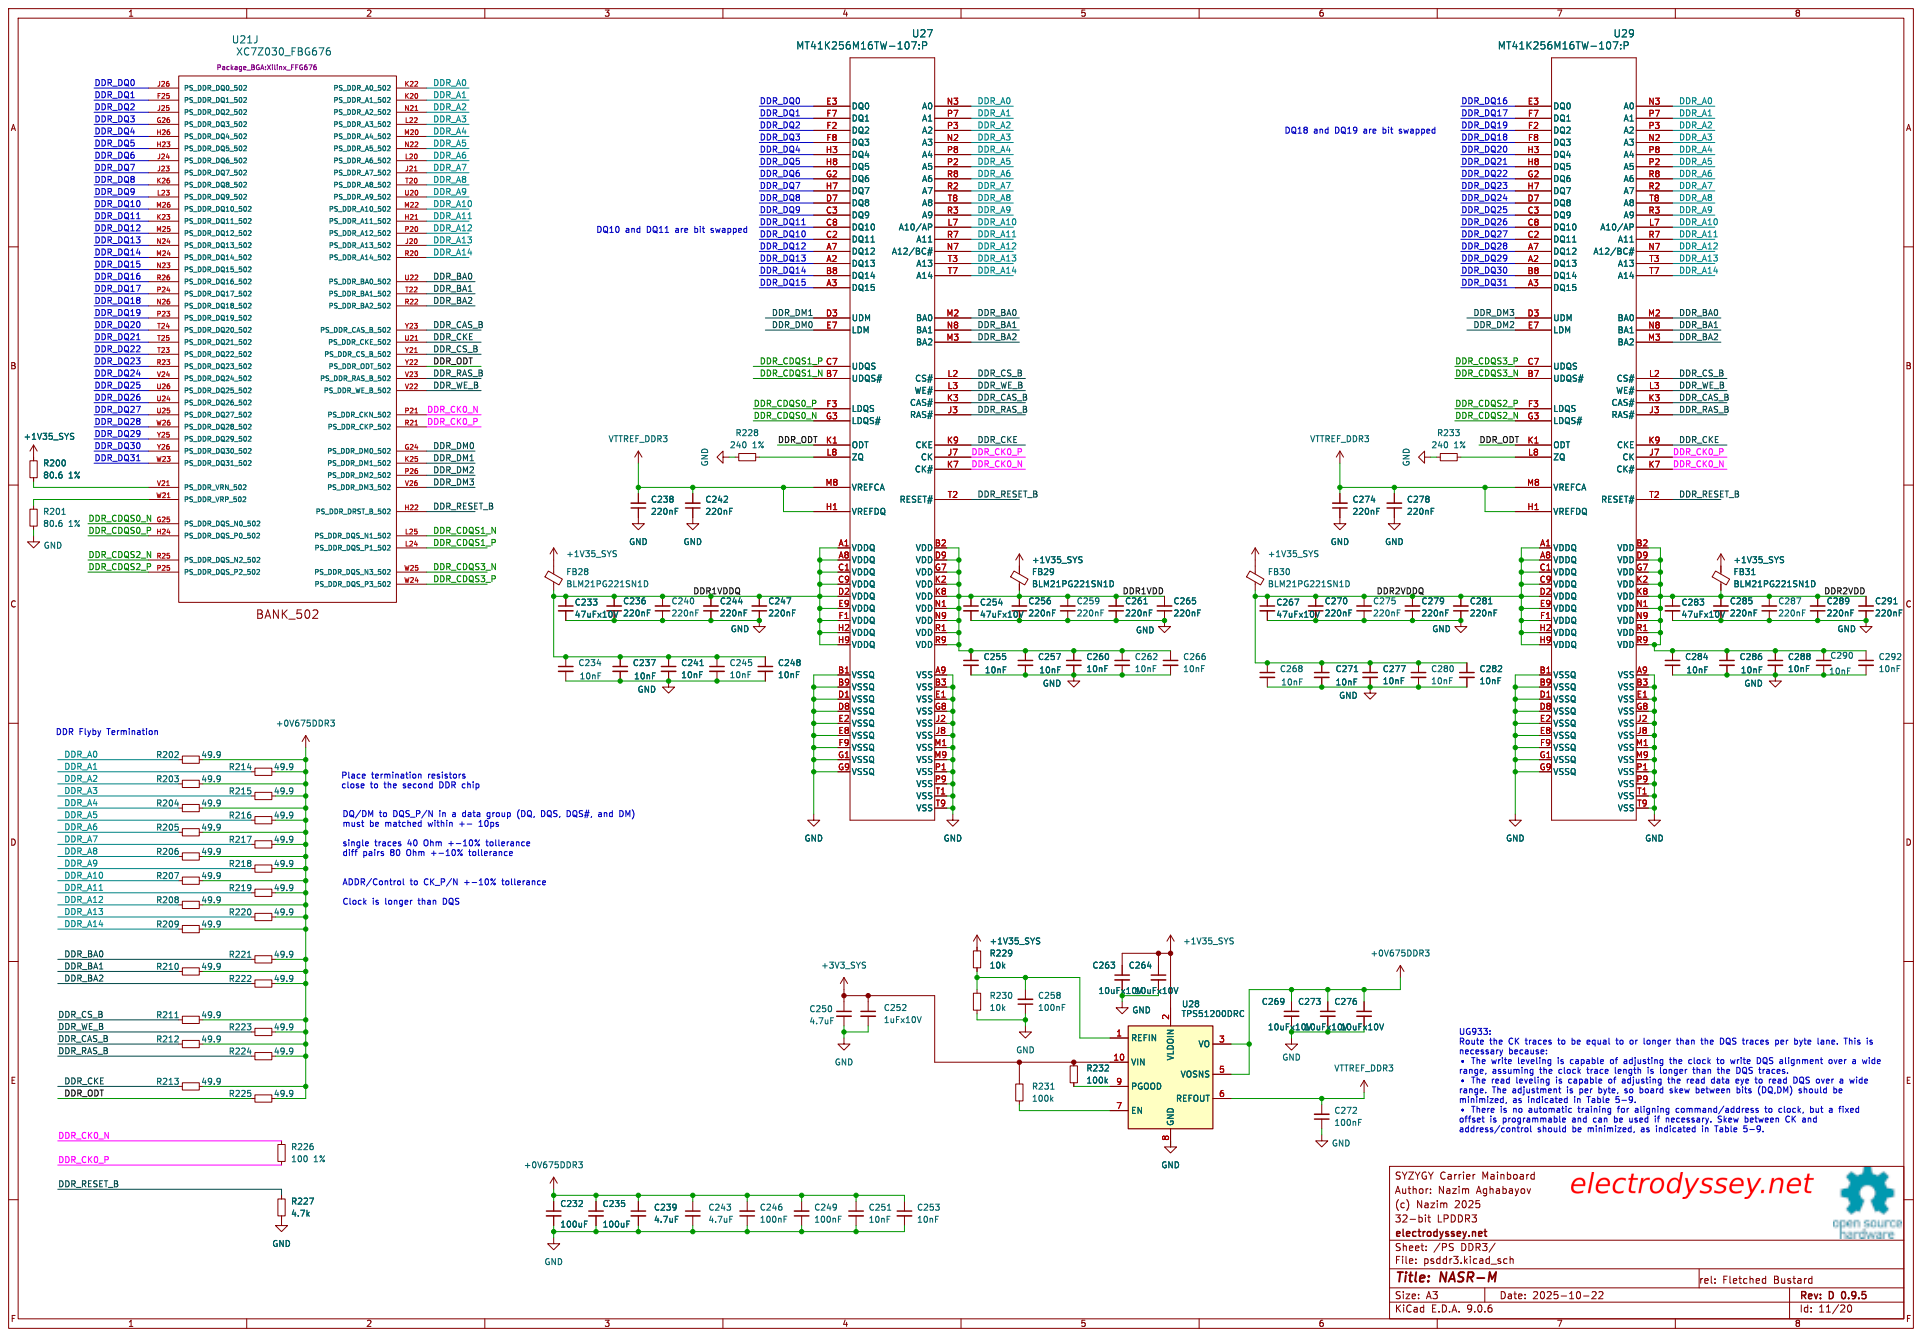
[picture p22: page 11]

DQ18 and DQ19 are bit swapped DQ10 and DQ11 are bit swapped

8 VO 3 REFOUT 6 REFIN 1 PGOOD 9 VOSNS 5 C276

8 VO 3 REFOUT 6 REFIN 1 PGOOD 9 VOSNS 5 U28 TPS51200DRC

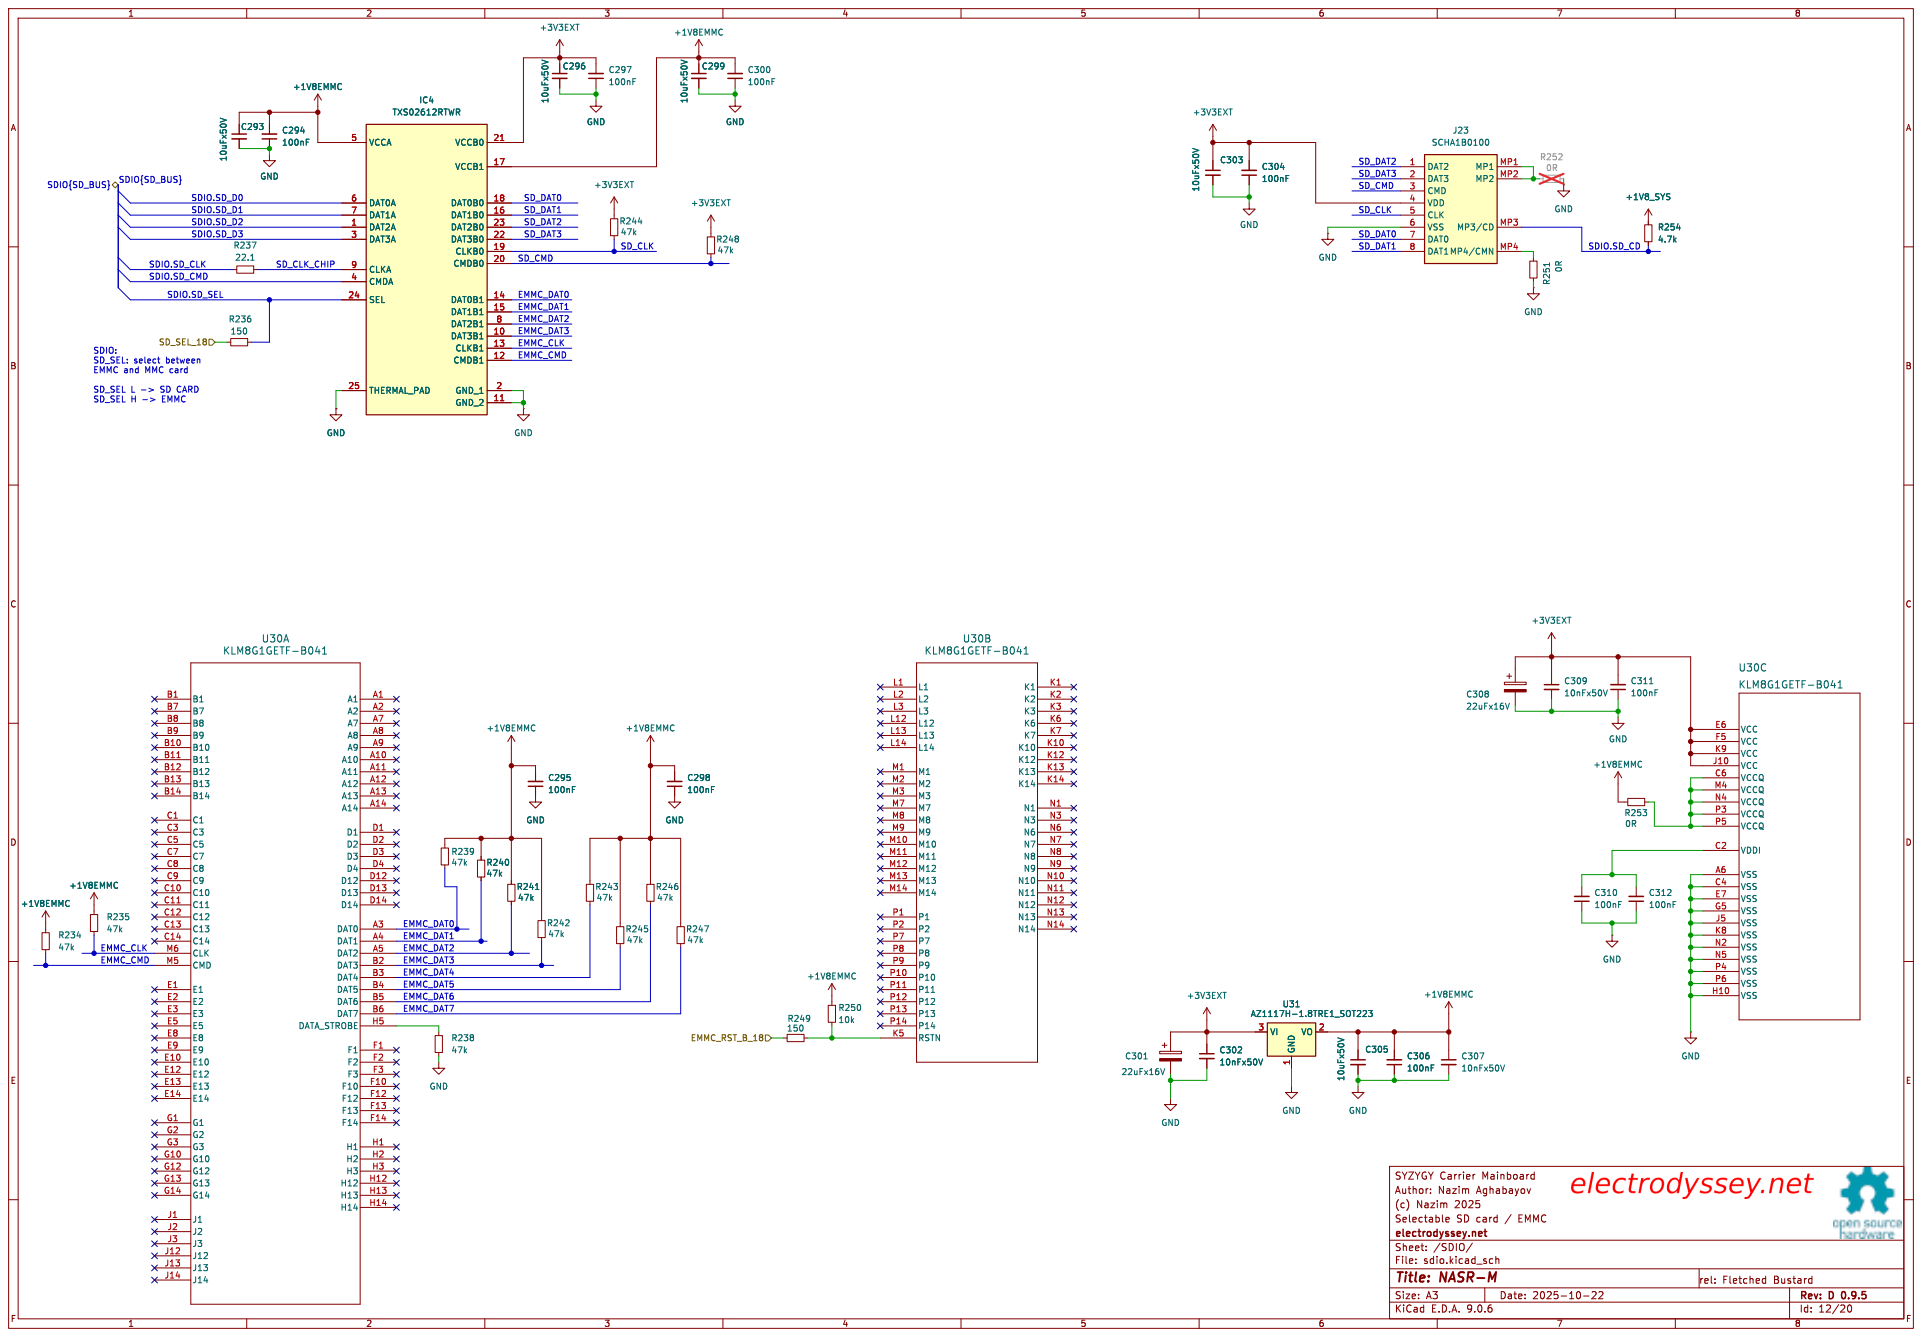
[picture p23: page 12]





TMS/SWDIO 2 TCK/SWCLK 4 TDO/SWO 6 RTCLK 7 TDI 8 VCC 1 G/+5 5 GND 3

SATA RX lines are swapped

7 PG 5 OUT 1 NC 2 GND


because SYZYGY P1,P2
were excluded from the board

VIOC_I2C_EXT_RST Resets the I2C extender when pulled low

on DAC RDY chanages Px_EXTO allows us to disable

the ADC power and outputs selectively VIO 1,2

so that 2.5V ADC out is possible

1 VSS 10 VOUTA 6 VOUTB 7 VOUTC 8 VOUTD 9 U44 MCP4728 R319

1 VSS 10 VOUTA 6 VOUTB 7 VOUTC 8 VOUTD 9 TP42 TestPoint R313


are used to pass through
the PS I2C:

File: syzygy34.kicad_sch Sheet: /SYZYGY34/ electrodyssey.net


I2C0.I2C_SDA
3V I2C DBG PORT CR2032 coin cell

to SYZYGY slot pins S25 [SDA] & S27 [SCL] R360


1 TXP 21 TXN 20 RXP 23 RXN 22 RBIAS 24

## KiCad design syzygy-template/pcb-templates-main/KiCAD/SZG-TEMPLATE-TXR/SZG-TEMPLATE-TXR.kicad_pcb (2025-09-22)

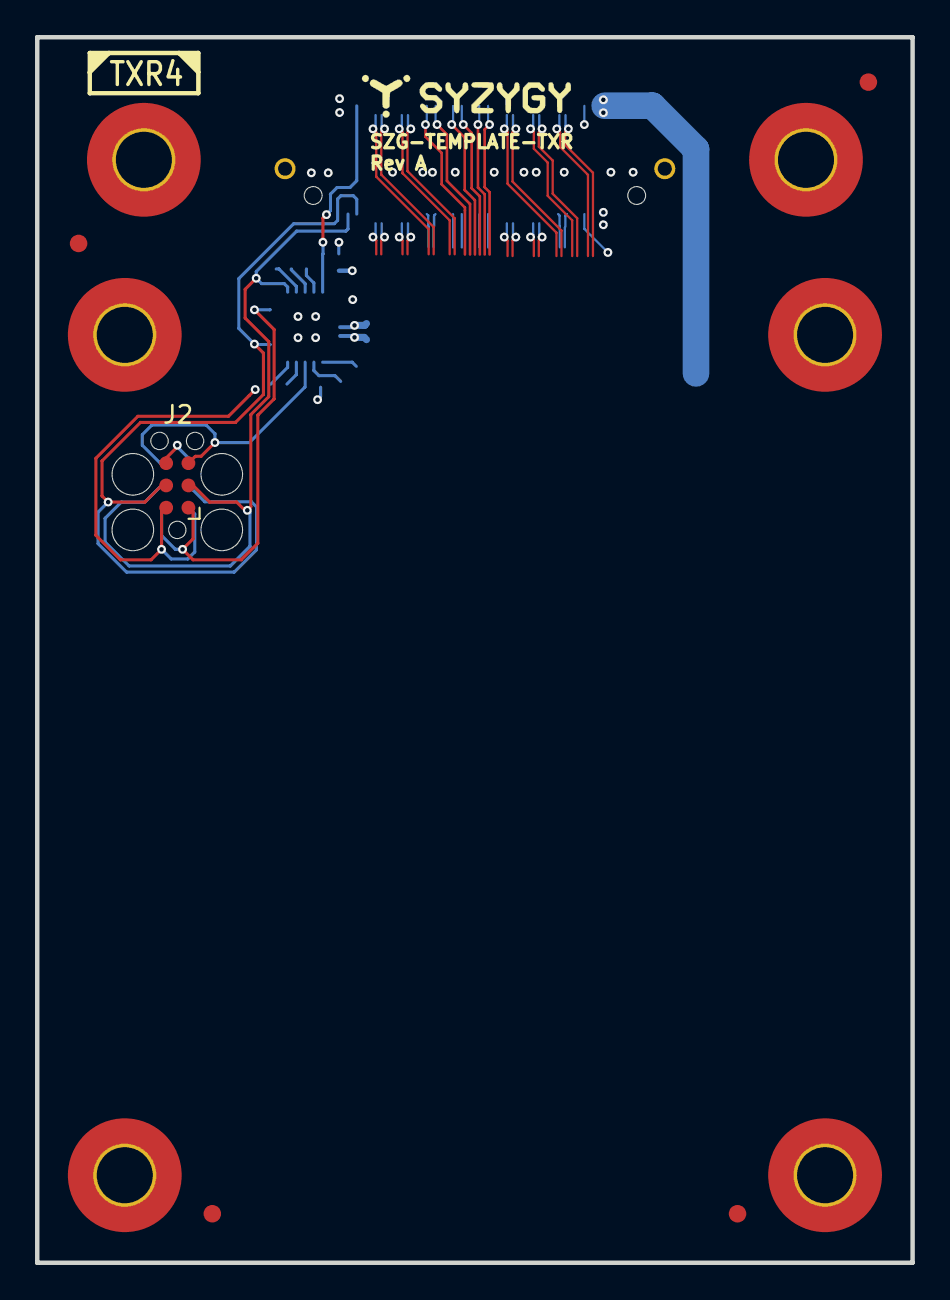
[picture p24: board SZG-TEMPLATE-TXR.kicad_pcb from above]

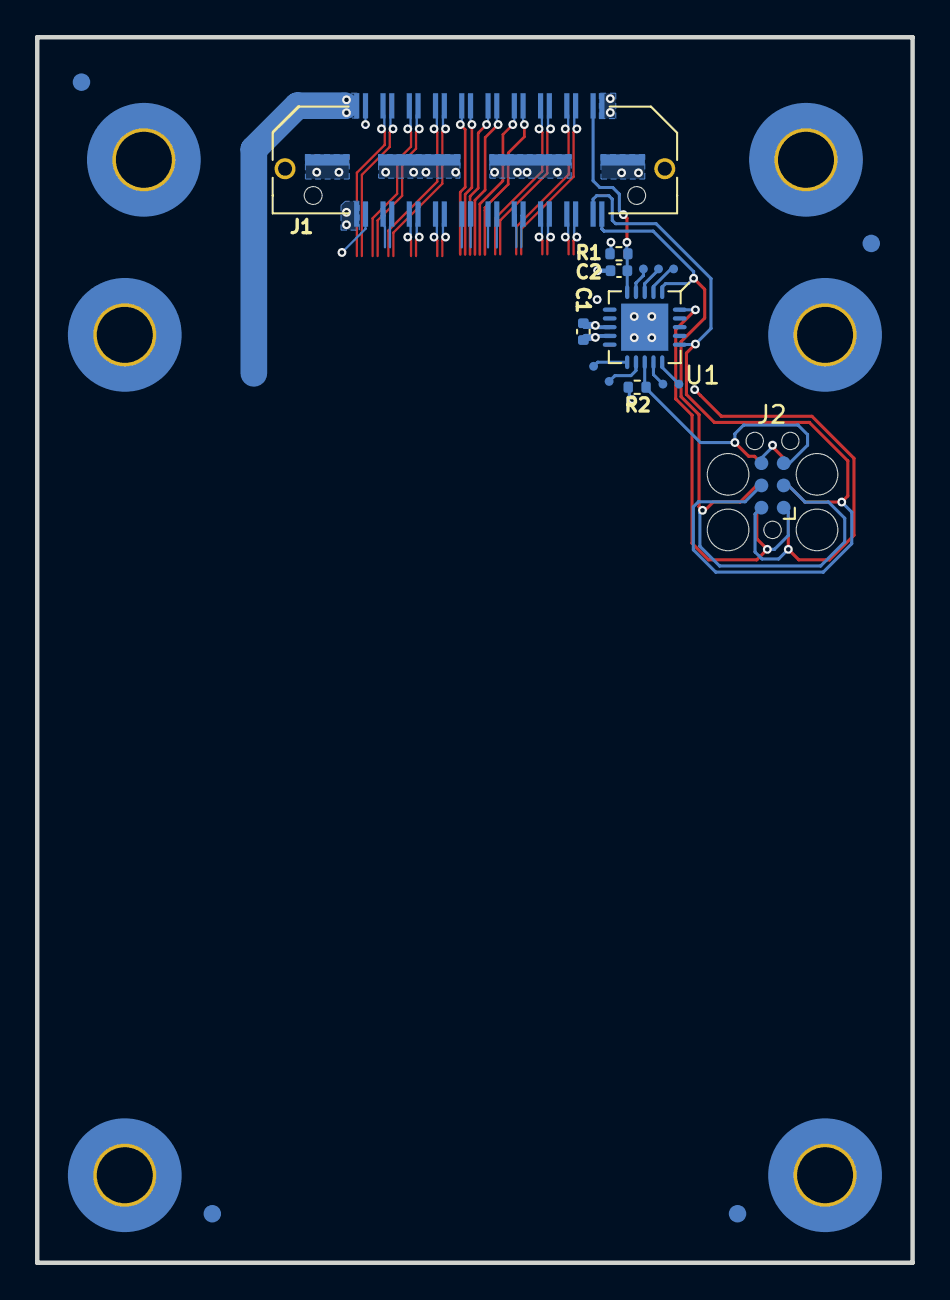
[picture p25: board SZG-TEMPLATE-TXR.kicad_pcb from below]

Board: 4 copper layers, 50.0 x 70.0 mm, 29 parts (17 on the bottom side), 14 nets.

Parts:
*1: Opal Kelly Logo; okLogo-23x5
C1: 0.1uF; C_0402_1005Metric
C2: 0.1uF DNP; C_0402_1005Metric
FID1, FID2, FID3, FID4, FID5, FID6, FID7, FID8: Fiducial; Fiducial_1mm_Mask2mm
H1, H2, H3, H4, H5, H6: MountingHole_Pad; MountingHole_3.2mm_M3_6.5mm_Pad_TopBottom
J1: SYZYGY_TXR-4; QTH-020-01-F-D-DP-A
J2: Conn_01x06; Tag-Connect_TC2030-IDC-FP_2x03_P1.27mm_Vertical
R1, R2: 10K; R_0402_1005Metric
TP5, TP6, TP7, TP8, TP9, TP10, TP11: TestPoint; TestPoint-20mil
U1: ATtiny44A-MU; QFN-24-4x4mm

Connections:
+3V3: C1.1, J1.40 (+3.3V), J2.2, R1.1, R2.1, U1.9 (VCC)
/MCU_MISO: J2.1, U1.20 (PA5)
/MCU_RESET_B: J2.5, R2.2, U1.13 (~RESET/PB3)
/MCU_SCL_USCK: J1.1 (SCL), J2.3, U1.1 (PA4)
/MCU_SDA_MOSI: J1.3 (SDA), J2.4, U1.16 (PA6)
/R_GA: C2.1, J1.4 (R_GA), R1.2, U1.5 (AREF/PA0)
GND: C1.2, C2.2, J1.0 (GND), J2.6, U1.8 (GND), U1.21 (GND)
unnamed: TP5.1, U1.11 (XTAL1/PB0)
unnamed: TP6.1, U1.4 (PA1)
unnamed: TP7.1, U1.12 (XTAL2/PB1)
unnamed: TP8.1, U1.3 (PA2)
unnamed: TP9.1, U1.14 (PB2)
unnamed: TP10.1, U1.2 (PA3)
unnamed: TP11.1, U1.15 (PA7)

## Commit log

2025-09-22 Import of NASR-M
    [7_Series_XPE_2019_1_2.xlsm, BOM-LMR33640-buck-6.5V@3.8A.csv, BOM-TPS51396 8V-22V to 3.30V @ 6A.csv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]
2025-09-22 README picture, pcb silkscreen change
2025-09-22 schematics in PDF
2025-09-24 MCU I2C4 is now directly connected to clock control
    [mcu.kicad_sch]
2025-09-24 pcb: MCU I2C4 is directly connected to clock control
2025-09-24 pdf update / mcu i2c4 is directly connected to the clock
2025-09-24 pcb: more copper pour around clock / front layer
    [mcu.kicad_sch]
2025-09-24 pcb: changed DDR3 power areas
    In3 tracks must not intersect with In2 planes, and VTTREF was rerouted
2025-09-25 pcb: minor silkscreen corrections
2025-09-26 JLCPCB part id's update
    [clockgen.kicad_sch, psu.kicad_sch, sdio.kicad_sch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]
2025-09-26 pcb: updated .net after JLCPB id's change
2025-09-26 schema timestamp update and new pdf export
    [NASR.kicad_sch, clockgen.kicad_sch, eth_mcu.kicad_sch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]
2025-09-26 minor changes here and there
    [usb-hub.kicad_sch]
2025-09-26 pcb: wider track for +1V2_MGTAVTT
2025-09-26 pcb: removed extra via for ddr reset, SOC pwr zone changes
2025-09-26 pcb: mainly silkscreen
2025-09-27 pcb: silkscreen changes mainly
2025-09-28 pcb:DDR addr on In7; I2C_PSSZG.I2C_SCL
    ddr addr small fixes on In7; I2C_PSSZG.I2C_SCL was missing
    connection to pullup resistor
2025-09-28 pcb: some of unnecessary vias were removed
2025-09-30 jlcpcb id's update
    [psddr3.kicad_sch, soc_power.kicad_sch]
2025-09-30 pcb: In2 DDR3 GND plane, JLCPCB id's update
2025-10-02 pcb: minor via placement changes
2025-10-05 CERN permissive OSHW license
    [NASR.kicad_sch]
2025-10-08 JLCPCB id's
    [psddr3.kicad_sch, soc_power.kicad_sch]
2025-10-08 minimal updates before manufacturing the boards
2025-10-15 PW filters, power GND goes to pin 3
    [psu.kicad_sch]
2025-10-15 schema update with correct power ground
2025-10-17 pcb: some DDR3 DQ lines changed, vias on microsd pins
    MicroSD footprint is hard to solder in by hand, so I've added
    hollow vias to the pins.
2025-10-21 pcb: minimal clearence on ground layers were decreased to 0.1
2025-10-21 more powerful inductors for SOC SMPS
    [soc_power.kicad_sch]
2025-10-21 schema update for new inductors in SMPS
    [NASR.kicad_sch, clockgen.kicad_sch, eth_mcu.kicad_sch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]
2025-10-22 schema: external clock input redone
    [clockgen.kicad_sch, soc_power.kicad_sch]
2025-10-22 pcb: external clock input was redone
2025-10-22 ext clock input change
    [NASR.kicad_sch, clockgen.kicad_sch, eth_mcu.kicad_sch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]
2025-10-22 pcb: ext clok input change
2025-10-31 pcb: more vias near layer changes
2025-11-15 pre-production silkscreen change
2025-11-29 pcb: silkscreen mainly
2025-12-15 schema pdf export
    This schema is valid for 0b79528 2025-11-29 Fletched Bustard (fist hw. prototype)
2026-02-03 ERRATA update. U8 I2C lines are reversed
2026-03-24 unhide ref designators from capacitors
    [clockgen.kicad_sch]
2026-03-24 Errata, SW5 PS reset button should be connected differently
2026-03-25 ERRATA, remove R271,solder in R272 to enable vreg on RTL8211
2026-04-03 Datasheet for M2 sata connector

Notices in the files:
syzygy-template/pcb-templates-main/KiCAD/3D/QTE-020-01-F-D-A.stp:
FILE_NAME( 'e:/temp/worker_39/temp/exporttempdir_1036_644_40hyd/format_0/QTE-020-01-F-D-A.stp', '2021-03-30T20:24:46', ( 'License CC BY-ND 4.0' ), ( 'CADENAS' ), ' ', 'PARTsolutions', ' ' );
